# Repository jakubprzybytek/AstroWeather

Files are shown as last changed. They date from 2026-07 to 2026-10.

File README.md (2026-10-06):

# AstroWeather

AstroWeather shows whether the coming nights are good for observing the sky. A
serverless API combines astronomy (sunset, sunrise, sun and moon) with weather
forecasts for a configured location and serves them as a compact text payload.
A Wi-Fi host board fetches that payload every 6 hours and shows six observing
nights on LED displays: its own and up to five chained display boards.

```text
weather supplier ──> sst API (AWS) ──HTTP──> host board ──I2C──> display boards (up to 5)
 (Clearoutside)       GET /astro/{id}       STM32G0B1 +           same PCB, no Wi-Fi
                                            ST67W611M1 Wi-Fi
```

## Repository layout

| Folder | What it holds | Start here |
| --- | --- | --- |
| [`sst/`](sst/) | The server: an [SST](https://sst.dev/) app on AWS (API Gateway, Lambda, DynamoDB, CloudFront), the weather ingestion jobs and a web UI | [architecture](sst/docs/architecture.md) |
| [`firmware/HostControllerA/`](firmware/HostControllerA/) | Firmware for the Wi-Fi host board (STM32G0B1) | [README](firmware/HostControllerA/README.md) |
| [`firmware/DisplayController/`](firmware/DisplayController/) | Firmware for the remote display boards (STM32G070): local display and the I2C link to the host; runs on the first display board | [README](firmware/DisplayController/README.md) |
| [`firmware/Common/`](firmware/Common/) | Code compiled into both firmware images: display encoding and multiplexing, the SCT2xxx driver, the I2C message, task helpers, and their native tests | [README](firmware/Common/README.md) |
| [`firmware/Bypass/`](firmware/Bypass/) | Bench firmware for a separate STM32G0B0 board: a USB-to-UART bridge for talking to and flashing the ST67W611M Wi-Fi module | [README](firmware/Bypass/README.md) |
| [`firmware/Docs/`](firmware/Docs/) | Documentation shared by the firmware projects: development workflow, display, I2C, testing, utilities | [README](firmware/Docs/README.md) |
| [`KiCad/`](KiCad/) | Schematic and PCB of the board. One design is populated as the host or as a display board | [README](KiCad/Docs/README.md) |

## Documentation

**Server (`sst/docs/`)**

- [architecture.md](sst/docs/architecture.md): components, data flow, storage, deployment stages
- [api.md](sst/docs/api.md) and [api-payload.md](sst/docs/api-payload.md): the forecast endpoint and its text payload, which the firmware parses
- [clearoutside-weather-supplier.md](sst/docs/clearoutside-weather-supplier.md): the weather source in use
- [meteosource-weather-supplier.md](sst/docs/meteosource-weather-supplier.md): evaluation of a possible second source
- [development.md](sst/docs/development.md): setup, local development and deployment
- [testing.md](sst/docs/testing.md): unit and integration tests

**Firmware**

Each firmware project starts with a README that lists its features and links
the document for each; documents shared by the projects are in
[firmware/Docs](firmware/Docs/README.md).

- [HostControllerA README](firmware/HostControllerA/README.md): what the host firmware does, its feature status table, quick start and documents
- [DisplayController README](firmware/DisplayController/README.md): the display board firmware, its feature status table, pins and documents
- [Common README](firmware/Common/README.md): the code shared by both firmware images
- [Development.md](firmware/Docs/Development.md): build, flash, debug, connecting over USB, CubeMX rules, for every project
- [Console.md](firmware/HostControllerA/Docs/Console.md): every console command, including Wi-Fi and server settings

**Hardware ([`KiCad/Docs`](KiCad/Docs/README.md))**

- [Hardware_Review.md](KiCad/Docs/Hardware_Review.md): design review, open issues, and measured current draw
- [Display-Issues.md](KiCad/Docs/Display-Issues.md): hardware problems seen on the LED displays, such as the prototype's matrix column faults around `U505`
- [Display_Board_Purchasing.md](KiCad/Docs/Display_Board_Purchasing.md) and [Display_Board_BOM.csv](KiCad/Docs/Display_Board_BOM.csv): parts for the display boards

## Status

- The server is deployed in stages (`prod`, `int`, ...; see
  [architecture.md](sst/docs/architecture.md#web-ui)); the host board fetches
  from the `int` stage.
- The host board fetches, shows and schedules the forecast. The first display
  board runs the DisplayController firmware on the host's I2C bus. See the feature table in the
  [firmware README](firmware/HostControllerA/README.md#features).
- The prototype host board carries hand rework for hardware issues that are not
  yet in the design files. See [Hardware_Review.md](KiCad/Docs/Hardware_Review.md#issues-sorted-by-severity).

## Getting started

- **Server:** [sst/docs/development.md](sst/docs/development.md).
- **Firmware:** the [quick start](firmware/HostControllerA/README.md#quick-start)
  in the firmware README, then [Development.md](firmware/Docs/Development.md)
  to build and flash. The board is pointed at the server with the `api` and
  `wifi` console commands.

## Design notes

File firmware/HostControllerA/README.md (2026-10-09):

# HostControllerA Firmware

Firmware for the AstroWeather host controller board: an STM32G0B1 with an
ST67W611M1 Wi-Fi module that fetches an astronomy and weather forecast and
shows it on seven-segment and dot-matrix LED displays, its own and those of up
to five remote display boards.

## What It Does

- Every 6 hours, at 00:10, 06:10, 12:10 and 18:10 local time, it joins Wi-Fi
  and fetches a line-based forecast payload over HTTPS from the AstroWeather
  server (`../../sst`), sending the device key saved with `api key`. A slot
  missed while the board was off or offline is caught up once, and failures
  are retried with a growing delay.
- It checks the payload's CRC, parses it, and shows it on its own LED board and
  on the remote display boards over I2C. Night *n* of the forecast goes to the
  board at address `0x10 + n`; every board, the host included, reads its
  address from its straps. It keeps the display boards' refresh in step with
  its own, so blinking and the `LED_1` heartbeat run together on every board.
- It keeps the date and time in the RTC, which runs from the 24 MHz crystal
  (HSE / 32) and is stepped to the server's time on every fetch. The time is shown as `HH:MM` on numeric display 3.
- It offers a USB CDC console for logs, status and commands, and keeps the
  last 24 warnings and errors over resets.
- It keeps its settings, including the Wi-Fi credentials, the server address
  and key and the clock trim, in an I2C EEPROM.
- It measures the board's supply current, die temperature and VDDA.
- Switch 1 starts a refresh; switch 2 toggles a low-brightness step on every
  board.

## Hardware

| Part | Role |
| --- | --- |
| STM32G0B1CETx | MCU: Cortex-M0+, 512 KB flash, 144 KB RAM, run at 16 MHz from a 24 MHz crystal |
| ST67W611M1 | Wi-Fi module, on SPI1 with DMA; runs ST's T01 firmware, so TCP/IP, DNS and TLS are in the module |
| 24AA04 | 512-byte I2C EEPROM for settings, on I2C1 at `0x50` |
| SCT2xxx | LED drivers in one SPI3 daisy chain, multiplexed in five slots |
| INA180A2 | Current-sense amplifier into ADC1 channel 10 (`PB2`) |
| `SWITCH_1`, `SWITCH_2` | Push buttons on `PB12` (astro refresh) and `PB13` (low brightness) |
| `LED_1`, `LED_2` | Heartbeat from the display refresh (`PC13`); switch presses and USB console traffic (`PB9`) |
| USB FS | CDC virtual COM port for the console |

The full pin map and the interrupt priorities are in
[Architecture.md](Docs/Architecture.md#peripherals-and-pins). The board design
and its known issues are in [KiCad/Docs](../../KiCad/Docs/README.md).

## Quick Start

1. Copy `Appli/App/app_credentials.h.template` to `Appli/App/app_credentials.h`
   (ignored by git) and set `APP_ST67_HTTP_HOST`, a bare host name, and
   `APP_ST67_HTTP_PATH`, starting with `/`. These are the built-in server; a
   board can be pointed elsewhere with `api host` and `api path`. The SSID and
   password macros in the template are not used.
2. Build, flash and open the console as described in
   [Development.md](../Docs/Development.md).
3. On the console, store the Wi-Fi credentials and the device key; both are
   saved to the EEPROM:

   ```text
   wifi set <ssid> <password>
   api key <key>
   ```

   `wifi set` runs a refresh straight away; `status` shows the result.
4. The clock needs no trim. If the drift measurement of a new board shows a
   crystal error of more than a few tens of ppm, set it with
   `time trim <ppm>` as described in [RTC.md](Docs/RTC.md#trimming).

## Features

Status: ✅ done · 🟡 partial · 🔴 not started · ⚠️ blocked by hardware.
Hardware issue IDs (C-1, H-1, ...) refer to
[Hardware_Review.md](../../KiCad/Docs/Hardware_Review.md).

| Feature | Status | Notes | Document |
| --- | --- | --- | --- |
| **Connectivity** | | | |
| Wi-Fi connection (ST67W611M1): join, DHCP, failure diagnosis | ✅ | Credentials set with `wifi set`, saved to the EEPROM | [WiFi.md](Docs/WiFi.md) |
| Fetch over HTTPS | ✅ | TLS in the module (T01), certificate chain and hostname verified against the built-in Amazon Root CA 1; 100/100 stress cycles | [WiFi.md](Docs/WiFi.md#http) |
| Server host, path and device key from the console | ✅ | `api host`, `api path`, `api key`, saved; `app_credentials.h` gives the built-in fallback | [WiFi.md](Docs/WiFi.md#server) |
| Module power saving between fetches | 🔴 | The module stays initialized between fetches | [WiFi.md](Docs/WiFi.md#open-items) |
| **Astro data** | | | |
| Payload parser (protocol 3, 6 blocks) | ✅ | Unit tested | [AstroRefresh.md](Docs/AstroRefresh.md) |
| Refresh every 6 hours with retry and catch-up | ✅ | The last success is lost on power loss | [AstroRefresh.md](Docs/AstroRefresh.md#schedule) |
| Refresh from switch 1 or the console | ✅ | A second request while busy is rejected | [AstroRefresh.md](Docs/AstroRefresh.md#triggers) |
| **Display** | | | |
| Local LED board: interrupt-driven multiplexing, refresh progress bar | ✅ | Matrix column 1 stays lit on the prototype ([Display-Issues.md](../../KiCad/Docs/Display-Issues.md)) | [Display.md](../Docs/Display.md) |
| Blinking and four brightness levels per segment and pixel | ✅ | The forecast's matrix rows carry levels and blink; the clock's colon and the progress bar blink | [Display.md](../Docs/Display.md#blink-and-brightness-levels) |
| Numeric formatting: fixed point, time, `?`, "no data" | ✅ | -0.5 shows as `-0.5`; values that do not fit four digits show the error pattern | [Display.md](../Docs/Display.md#numeric-representation) |
| Boot screens: slot test, then the host's strap address and build number | ✅ | Shared with the display boards | [Display.md](../Docs/Display.md#boot-screens) |
| Remote display boards over I2C | ✅ | Board `0x11` runs the [DisplayController](../DisplayController/README.md) firmware; I2C pull-ups needed (H-4) | [I2C.md](../Docs/I2C.md) |
| Timeline sync: the display boards' refresh, blinking and heartbeat in step with the host's | 🟡 | `DisplaySync` broadcasts on the I2C general call at boot, on request and every 2 min, and polls each board's status; `time sync [now]`. Unit tested, simulated and bench-measured on one board | [TimelineSync.md](../Docs/TimelineSync.md) |
| Heartbeat on `LED_1`, 20 ms every 2 s | ✅ | From the refresh interrupt, so it shows the refresh is running | [TimelineSync.md](../Docs/TimelineSync.md#the-timeline-on-every-board) |
| Low-brightness step (`LOW_POWER_ENABLE`) for every board | ✅ | `display low on\|off` or switch 2, saved; cuts LED current by about half | [Display.md](Docs/Display.md#low-brightness) |
| **Time** | | | |
| RTC clock on numeric display 3, `time` commands | ✅ | Lost on power loss (no LSE crystal or backup battery) | [RTC.md](Docs/RTC.md) |
| Clock sync from the server, with drift measurement | ✅ | | [RTC.md](Docs/RTC.md#sync-from-the-api) |
| RTC on the 24 MHz crystal (HSE / 32), clock trim | ✅ | The crystal's error not measured yet; `time trim` by hand, ±1000 ppm | [RTC.md](Docs/RTC.md#clock-source) |
| System clock from the 24 MHz crystal | ✅ | `time hsi` and `tools/hsi_measure.py`'s trim are left over from HSI16 and have no effect | [TimelineSync.md](../Docs/TimelineSync.md#the-hosts-clock) |
| **Power and sensing** | | | |
| Current, temperature and VDDA monitor | ✅ (reworked board) | Needs the C-1 and H-1 rework | [CurrentSense.md](Docs/CurrentSense.md) |
| VBUS voltage sense | ⚠️ | PC7 is not an ADC pin and has no divider (H-1, H-2) | [Hardware review](../../KiCad/Docs/Hardware_Review.md) |
| USB-PD negotiation for more than 5 V | 🔴 | Hardware changes needed; see the [study](../../KiCad/Docs/archive/USB_PD_Feasibility.md) | |
| Reading the USB-C current limit (CC pins) | 🔴 | Worst-case load exceeds the USB default (H-5) | [Hardware review](../../KiCad/Docs/Hardware_Review.md) |
| **System** | | | |
| USB console: commands, help, log, statistics | ✅ | `help`, `help <group> <command>`, `help all` | [Console.md](Docs/Console.md) |
| Display commands for this board, a remote board or all | ✅ | `display 0x12 test`, `display all clear` | [Console.md](Docs/Console.md#display) |
| Error log: the last 24 warnings and errors, kept over resets | ✅ | `errors [clear]`; lost on power loss | [Console.md](Docs/Console.md#error-log) |
| EEPROM settings | ✅ | | [Settings.md](Docs/Settings.md) |
| Interrupt priorities: USB 1, everything else 3 | ✅ | | [Architecture.md](Docs/Architecture.md#interrupt-priorities) |
| Firmware version and git hash | 🔴 | Only the build time and a build number (`BUILD_NUMBER`, one more every build) are stamped | [Architecture.md](Docs/Architecture.md#shared-code) |
| Unit tests | 🟡 | 16 native suites run in CI; the console, the settings store and the remote boards are not covered yet | [Testing.md](Docs/Testing.md) |

## Known Limitations and Open Items

Hardware:

- **The prototype host board carries hand rework** that the design files do not
  show yet: `VREF+` rewired to VDD (C-1) and the current-sense net taken to PB2
  (H-1). Boards built from the current files need the same changes.
- **Random contents at power-up (L-3):** the host still starts `SCT_ENABLE`
  low; the display boards already start it high
  ([Display-Issues.md](../../KiCad/Docs/Display-Issues.md#other-known-issues)).

Firmware, with details in each document's open items:

- Wi-Fi: module power policy, repeated cold restarts, the HTTP error paths at
  run time, small heap retentions, no fetch cancellation, certificate validity
  dates ([WiFi.md](Docs/WiFi.md#open-items)).
- Astro refresh: stale data after a failed noon refresh, low-power wake
  ([AstroRefresh.md](Docs/AstroRefresh.md#open-items)).
- Clock: measure the crystal's error, and the time lost over a flash
  ([RTC.md](Docs/RTC.md#open-items)).
- Display timeline sync: a run over a day's temperature, the display boards'
  HSI16 wander, the leftover `time hsi`
  ([TimelineSync.md](../Docs/TimelineSync.md#open-items)).
- Settings: a torn write is detected but not recovered, credentials are stored
  in the clear, unknown tags are not preserved
  ([Settings.md](Docs/Settings.md#limitations)).
- RAM: the forecast payload is held twice; holding it once would save 4 KB
  ([Firmware-RAM-Usage.md](Docs/Firmware-RAM-Usage.md)).
- Tests: the console, `Settings::Store`, the EEPROM driver and
  `BufferedDisplayBoard` ([Testing.md](Docs/Testing.md#not-covered-yet)).

## Documentation

This project ([Docs](Docs/)):

- [Architecture.md](Docs/Architecture.md): boot, tasks, inter-task communication, interrupt priorities, pins, memory
- [Console.md](Docs/Console.md): the USB device, the log, the error log and every console command
- [WiFi.md](Docs/WiFi.md): the ST67 module, the session, HTTPS, the server settings
- [AstroRefresh.md](Docs/AstroRefresh.md): the refresh pipeline, the payload, the display mapping, the schedule
- [Display.md](Docs/Display.md): the host's side of the displays: the aggregate display, remote boards, progress bar, low brightness
- [RTC.md](Docs/RTC.md): the clock, its trim and the sync from the server
- [Settings.md](Docs/Settings.md): the EEPROM settings image
- [CurrentSense.md](Docs/CurrentSense.md): current, temperature and VDDA
- [Testing.md](Docs/Testing.md): this project's suites, coverage and bench tests
- [Firmware-RAM-Usage.md](Docs/Firmware-RAM-Usage.md): static RAM breakdown
- [archive](Docs/archive/README.md): plans, investigations and measurement logs

Shared with the display boards ([firmware/Docs](../Docs/README.md)):

- [Development.md](../Docs/Development.md): build, flash, debug, connecting over USB, CubeMX rules
- [Display.md](../Docs/Display.md): the display, its encoding and refresh
- [TimelineSync.md](../Docs/TimelineSync.md): the timeline sync to the display boards, its schedule, the clocks
- [I2C.md](../Docs/I2C.md): the bus, the messages, the addresses, both sides of the link
- [Testing.md](../Docs/Testing.md): the native test kit
- [Utilities.md](../Docs/Utilities.md): tasks, mutexes, switches, the microsecond clock, HSI trim, LEDs

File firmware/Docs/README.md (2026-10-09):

# Firmware Documentation

Documents that apply to more than one firmware project. Each project's own
documents are listed in its README.

| Document | Covers |
| --- | --- |
| [Development.md](Development.md) | Toolchain, building, flashing and debugging every project, connecting to the host's USB CDC console, and keeping application changes CubeMX-compliant |
| [Display.md](Display.md) | The LED display shared by every board: content model, blink and brightness levels, PCB encoding, the interrupt-driven refresh, boot screens and "no data", the `SCT2xxx` chain |
| [TimelineSync.md](TimelineSync.md) | How the display boards keep their refresh in step with the host's: the shared timeline, the host's schedule of syncs, a board's decisions, the clocks and HSITRIM, measuring it over SWD, accuracy |
| [I2C.md](I2C.md) | The I2C link between the host and the display boards: bus, addresses and straps, message format, the timeline sync broadcast and status read, the host's master side and the display board's target side |
| [Testing.md](Testing.md) | Native unit tests: running and writing them, the shared stubs and assertions, CI, coverage, the shared code's suites |
| [Utilities.md](Utilities.md) | The shared tasks, mutexes, switches, CRC-32, microsecond clock, HSI trim and status LEDs, and the rules for code in `Common` |

## Projects

| Project | Board | README |
| --- | --- | --- |
| `HostControllerA` | Wi-Fi host, STM32G0B1 | [README](../HostControllerA/README.md) |
| `DisplayController` | Remote display boards, STM32G070 | [README](../DisplayController/README.md) |
| `Common` | Code compiled into both of the above | [README](../Common/README.md) |
| `Bypass` | Bench USB-to-UART bridge for the ST67 module, STM32G0B0 | [README](../Bypass/README.md) |

The board hardware (schematic review, display board parts, known display
faults) is documented in [KiCad/Docs](../../KiCad/Docs/README.md).

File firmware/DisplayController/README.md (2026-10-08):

# DisplayController Firmware

Firmware for the AstroWeather remote display boards: an STM32G070CBT6 that
receives its display content from the host over I2C and multiplexes it onto
its own four seven-segment displays and 5x21 dot matrix. A display board is
the same PCB as the host, populated without the Wi-Fi module, the USB port and
the EEPROM; see
[Display_Board_Purchasing.md](../../KiCad/Docs/Display_Board_Purchasing.md).

The first display board runs it on the host's I2C bus at `0x11`.

## Features

Status: ✅ done and checked on the board · 🔵 built and unit tested, not yet
checked on the board · 🔴 not started.

| Feature | Status | Notes | Document |
| --- | --- | --- | --- |
| **Display** | | | |
| Drive the local LED board: five slots, 50 Hz frames, four passes per slot | ✅ | `PcbDisplayBoard` from TIM6's interrupt, SPI1 by DMA; shared with the host | [Display.md](../Docs/Display.md#refresh-operation) |
| Blink and four brightness levels per segment and pixel | ✅ | Sent by the host as attribute planes with the content | [Display.md](../Docs/Display.md#blink-and-brightness-levels) |
| Refresh timeline kept on the host's: blinking and the heartbeat in step on every board | 🔵 | Syncs broadcast by the host on the I2C general call; per-frame rate and phase correction, simulated within a few ms | [TimelineSync.md](../Docs/TimelineSync.md) |
| HSITRIM moved to follow the host's clock | 🔵 | Up to 8 steps from the boot trim, never across an HSICAL band edge; the servo covers the rest, up to 2 % | [TimelineSync.md](../Docs/TimelineSync.md#following-the-host) |
| Safe power-up: outputs blanked, all slots off | ✅ | `SCT_ENABLE` and the slot selects start high (CubeMX); the first frame is prepared before the outputs are enabled | [Architecture.md](Docs/Architecture.md#boot) |
| Boot screens: slot test (each `DISPLAYx_EN` slot on its own, 1 s), then the board address (`Ad11`) and build number, 2 s | ✅ | Shared with the host (`Display::showBootScreens()`) | [Display.md](../Docs/Display.md#boot-screens) |
| "No data" until the first frame, and again after 7 h without one | 🔵 | Shared state (`Display::noDataState()`); 7 h is just over the host's 6-hour refresh interval | [Architecture.md](Docs/Architecture.md#screens) |
| **I2C link to the host** | | | |
| Address from the `ADDR_0..2` straps, `0x10`–`0x2A` | ✅ | Floating 0, ground 1, VCC 2; board 1 reads `0x11` | [I2C.md](../Docs/I2C.md#addresses-and-straps) |
| I2C target: content and attribute messages | ✅ | Interrupt-driven listen; the messages are decoded in the `DisplayApp` task. The I2C interrupt is at priority 1 so every message is acknowledged | [I2C.md](../Docs/I2C.md#display-board-side) |
| Listen only once the address is known | ✅ | Nothing answers on CubeMX's placeholder `0x10` | [I2C.md](../Docs/I2C.md#display-board-side) |
| Timeline sync on the general call, status on a one-byte read | 🔵 | `0xA0` with flags: locked, needs content; a reset board asks for and gets the host's content within a minute | [I2C.md](../Docs/I2C.md#timeline-sync) |
| Reject unknown commands and short writes, keeping the previous frame | 🔵 | Counted in `g_displayStats` | [I2C.md](../Docs/I2C.md#display-board-side) |
| Recover from bus errors | 🔵 | Listening restarts after an error and is checked every second | [I2C.md](../Docs/I2C.md#display-board-side) |
| **Brightness** | | | |
| Never drive the bussed `LOW_POWER_ENABLE` line | ✅ | `PB8` stays analog; the host drives it for every board ([Hardware review](../../KiCad/Docs/Hardware_Review.md) M-4) | [Display.md](../Docs/Display.md#low-brightness) |
| **Development aids** | | | |
| Heartbeat on `LED_1`, 20 ms every 2 s, from the refresh interrupt | 🔵 | Frame 1 of every 100 on the shared timeline, so in step with the host once synced; twice (frames 1 and 11) while not locked to it | [TimelineSync.md](../Docs/TimelineSync.md#the-timeline-on-every-board) |
| `LED_2` flashes on every write addressed to the board | 🔵 | 20 ms, from the address-match interrupt, through the shared `PulseLed`; not for the sync broadcast or the status reads | [Architecture.md](Docs/Architecture.md#screens) |
| Switch 1 steps through test screens, switch 2 shows the address | 🔵 | All segments, then an identify pattern; test screens close after 60 s, the address after 3 s | [Architecture.md](Docs/Architecture.md#screens) |
| Diagnostic counters, read over SWD | ✅ | `g_displayStats`: frames, attributes, rejects, short writes, probes, I2C errors, refresh counters; the sync counters, error, drift, rate and HSITRIM (🔵) | [Architecture.md](Docs/Architecture.md#diagnostics) |
| Stack overflow hook | ✅ | Halts with the task name in `g_stackOverflowTaskName` | [Architecture.md](Docs/Architecture.md#diagnostics) |
| Console over USART2 (`PA2`/`PA3`, 115200) | 🔴 | The G070 has no USB; USART2 is disabled in CubeMX. Wiring in [Display_Board_Purchasing.md](../../KiCad/Docs/Display_Board_Purchasing.md#console-over-uart) | |
| **Platform** | | | |
| CubeMX project on the STM32G070, `Debug` and `Release` presets | ✅ | Compiles the shared code from `../Common` | [Development.md](../Docs/Development.md) |
| FreeRTOS with static tasks; `defaultTask` exits at start | ✅ | The 3072-byte heap is used only by `defaultTask` until it exits | [Architecture.md](Docs/Architecture.md#tasks) |
| Interrupt priorities: I2C 1, everything else 3 | ✅ | | [Architecture.md](Docs/Architecture.md#interrupt-priorities) |
| Native tests for the screens, the stale-data timeout and the frame assembly | ✅ | 3 suites in `tests/`; the shared code's suites, the timeline sync's among them, are in `../Common/tests` | [Testing.md](../Docs/Testing.md) |

## Hardware

From `DisplayController.ioc`; the pins and their labels match the host so the
shared code compiles unchanged.

| Peripheral | Pins | Use |
| --- | --- | --- |
| SPI1, master TX only, 1 Mbit/s, TX by DMA1 channel 1 | `PB3` SCK, `PB5` MOSI | SCT2xxx daisy chain |
| GPIO | `PB6` `SCT_LATCH`, `PB7` `SCT_ENABLE` (starts high: outputs blanked) | SCT latch and output enable |
| GPIO | `PD3`, `PA15`, `PD1`, `PD2`, `PD0` = `DISPLAY_1_EN`..`DISPLAY_5_EN` (start high: off) | Active-low multiplex selects |
| TIM6, prescaler 15 (1 MHz count) | none | Display refresh; the interrupt sets each pass's length (the G070 has no TIM2) |
| I2C1, target, interrupt at priority 1 | `PA9` SCL, `PA10` SDA | Messages from the host, at `0x10` + the strap ID; the timeline sync on the general call (enabled in code, not the `.ioc`) |
| GPIO inputs | `PB10`, `PB11`, `PB14` = `ADDR_0`..`ADDR_2` | Board address straps; analog once read |
| GPIO EXTI, falling edge, internal pull-up | `PB12` `SWITCH_1`, `PB13` `SWITCH_2` | Switches; the buttons and their external pull-ups are optional on a display board |
| GPIO | `PC13` `LED_1`, `PB9` `LED_2` | Heartbeat from the refresh interrupt, I2C writes to the board |
| Analog | `PB8` `LOW_POWER_ENABLE` | Bussed net driven by the host; never driven here |
| SWD | `PA13`, `PA14` | Debug |
| TIM1 | none | HAL time base |

## Build and Flash

The toolchain, presets, flashing and native tests are shared with the other
firmware projects and described in
[Development.md](../Docs/Development.md). In short:

```bash
cmake --preset Debug
cmake --build --preset Debug
STM32_Programmer_CLI -c port=SWD -w build/Debug/DisplayController.elf -v -hardRst
```

## Layout

| Path | Owner |
| --- | --- |
| `DisplayController.ioc`, `Core/`, `Drivers/`, `Middlewares/`, `cmake/stm32cubemx/`, the startup file and linker script | CubeMX; application changes only inside `USER CODE` sections |
| `CMakeLists.txt`, `CMakePresets.json` | The project: adds `User/` and `../Common` to the CubeMX target |
| `User/Inc`, `User/Src` | Application code specific to the display board |
| `tests/` | Native tests of that code |
| `../Common` | Code shared with the host, compiled into this image ([README](../Common/README.md)) |

## Documentation

This project:

- [Docs/Architecture.md](Docs/Architecture.md): boot, tasks, screens, interrupt priorities, the SWD diagnostics
- [Docs/archive](Docs/archive/): [I2C_NACK_Investigation.md](Docs/archive/I2C_NACK_Investigation.md), how the I2C interrupt priority was found

Shared with the host ([firmware/Docs](../Docs/README.md)):

- [Development.md](../Docs/Development.md): build, flash, debug, CubeMX rules
- [Display.md](../Docs/Display.md): the display, its encoding and refresh
- [TimelineSync.md](../Docs/TimelineSync.md): the timeline kept on the host's, the sync schedule and decisions, HSITRIM, measuring it with `tools/stats_log.py`
- [I2C.md](../Docs/I2C.md): the bus, the messages, the addresses, both sides of the link
- [Testing.md](../Docs/Testing.md): native tests
- [Utilities.md](../Docs/Utilities.md): tasks, mutexes, switches, the microsecond clock, HSI trim, LEDs

Hardware: [KiCad/Docs](../../KiCad/Docs/README.md).

## Known Limitations and Open Items

- Not yet checked on the board: rejecting unknown commands and short writes,
  recovery from bus errors, the 7-hour "no data" timeout and the switch test
  screens.
- The timeline sync: a run over a day's temperature, the cause of the host's
  clock wander
  ([TimelineSync.md](../Docs/TimelineSync.md#open-items)).
- No console: the counters are read over SWD until the USART2 console exists.
- The FreeRTOS heap (3072 B) could shrink, since only `defaultTask` uses it
  and only until it exits.

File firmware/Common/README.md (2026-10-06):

# Common Firmware Code

Code shared by the two AstroWeather firmware images:
[HostControllerA](../HostControllerA/README.md), the Wi-Fi host on an
STM32G0B1, and [DisplayController](../DisplayController/README.md), the remote
display boards on an STM32G070.

## What Is Here

| Directory | Contents |
| --- | --- |
| `Src/Display`, `Inc/Display` | Logical display content and attributes (`DisplayTypes`), the PCB segment and matrix encoding (`DisplayCodec`), the pass sequencing (`RefreshSequencer`), the interrupt-driven multiplexing (`PcbDisplayBoard`), the refresh timeline and its sync (`Timeline`, `TimelineServo`, `TimelineSync`), the boot screens (`BootScreens`), the I2C message format (`DisplayI2cProtocol`), the address straps (`DisplayAddress`) and the `DisplayBoard` interface |
| `Src/Device`, `Inc/Device` | The `SCT2xxx` LED driver chain over SPI; `HsiTrim`, the HSI16 user trim |
| `Src/Utils`, `Inc/Utils` | `Task`/`TaskBase` (CMSIS-RTOS2 tasks with static stacks and a registry), `Mutex`, `SwitchInput`, `Crc32`, `microsNow()` (`MicroClock`) |
| `Src/Debug`, `Inc/Debug` | `PulseLed` and `activityLed()` (`LED_2`, also from interrupts and C through `ActivityLedBridge.h`); the `LED_1` heartbeat comes from the refresh interrupt (`PcbDisplayBoard`) |
| `tests/` | Native unit tests for the above, and the pieces both projects' own tests reuse: the HAL and RTOS stubs (`stubs/`), `Expect.hpp` (`support/`), `add_native_test()` (`NativeTest.cmake`) and a stand-in `main.h` (`board/`) |

Each part is documented in the shared firmware docs, [firmware/Docs](../Docs/README.md):

| Part | Document |
| --- | --- |
| Display content, attributes, PCB encoding, the multiplexing refresh, the timeline sync and the heartbeat, boot screens, `SCT2xxx` | [Display.md](../Docs/Display.md) |
| The I2C message format, the sync broadcast and status read, the address straps | [I2C.md](../Docs/I2C.md) |
| `Task`, `Mutex`, `SwitchInput`, `Crc32`, `microsNow()`, `HsiTrim`, the LEDs | [Utilities.md](../Docs/Utilities.md) |
| The native test kit and the suites in `tests/` | [Testing.md](../Docs/Testing.md) |

## How It Is Built

This is not a library. Each firmware project includes `CommonSources.cmake`
and compiles `${COMMON_SOURCES}` itself, against its own HAL, device define
(`STM32G0B1xx` or `STM32G070xx`), `stm32g0xx_hal_conf.h`, `FreeRTOSConfig.h`
and `main.h`. A change here must therefore be built in both projects.

Rules for code in this tree:

- It may include `main.h`, `cmsis_os2.h` and `FreeRTOS.h`, and may use the pin
  labels both CubeMX projects define: `LED_1`, `LED_2`, `SWITCH_1`, `SWITCH_2`,
  `ADDR_0`..`ADDR_2`, `DISPLAY_1_EN`..`DISPLAY_5_EN`, `SCT_LATCH`, `SCT_ENABLE`.
  Peripheral handles (`hspi3` on the host, `hspi1` on the display board, the
  refresh timer) are passed in by the project, never named here.
- It must not depend on anything only one project has: the host's `LogService`,
  USB, the settings store, the EEPROM, Wi-Fi.

## Tests

The native suites build with the host compiler and run under CTest, without a
board (MSYS2 UCRT64 on the development workstation, see the presets):

```bash
cmake --preset NativeTests
cmake --build --preset NativeTests
ctest --test-dir build/native-tests-local --output-on-failure
```

`NativeTests-Coverage` adds `--coverage` for `gcovr`. The GitHub Actions
workflow `firmware-native-tests.yml` runs these suites and both projects' on
every push. How to write a test, the stubs and what each suite covers are in
[Testing.md](../Docs/Testing.md).

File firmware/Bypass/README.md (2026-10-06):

# AstroWeather ST67 Bypass

## Purpose

Firmware for an STM32G0B0-based board that turns a PC's USB connection into a
binary-transparent bridge to an ST67W611M Wi-Fi/BLE NCP module:

```text
PC (USB CDC)  <->  STM32G0B0 Bypass firmware  <->  USART2 (2,000,000 baud)  <->  ST67W611M
```

It supports two purposes:

1. **UART bypass ("Manufacture" mode)** - a transparent pass-through so a PC
   tool can talk to the ST67's normal UART shell/AT-style interface.
2. **Bootloader mode** - applies the ST67's verified bootloader strap/reset
   sequence and then provides the same transparent transport, so the PC-side
   vendor tool `QConn_Flash_Cmd` can erase/program/verify the ST67 over USB
   instead of needing direct wiring to the module's UART pins.

The STM32 firmware never parses or interprets the ST67 protocol in either
mode; it only applies the correct GPIO strap sequence and moves bytes.

[Docs/ST67_Bypass_Maintainer_Notes.md](Docs/ST67_Bypass_Maintainer_Notes.md)
covers the architecture, mode selection, host tooling, the verified ST67 flash
map and known tooling quirks. The original implementation plan and bring-up
guide are in [Docs/archive](Docs/archive/).

## Building

Prerequisites: `arm-none-eabi-gcc`, `cmake`, and `ninja`. If you have
STM32CubeIDE installed instead of a standalone toolchain, it bundles all
three under its `plugins/com.st.stm32cube.ide.mcu.externaltools.*/tools/bin`
folders - add those to `PATH` for the commands below.

The project builds with four CMake presets, one per combination of build
type and ST67 startup mode (`CMakePresets.json`):

| Preset | Build type | ST67 startup mode |
|---|---|---|
| `Debug-Manufacture` | Debug | Manufacture (default) |
| `Release-Manufacture` | Release | Manufacture (default) |
| `Debug-Bootloader` | Debug | Bootloader |
| `Release-Bootloader` | Release | Bootloader |

```bash
cmake --preset Debug-Manufacture
cmake --build --preset Debug-Manufacture
```

Each preset configures into its own `build/<PresetName>` directory and
produces a `Bypass.elf` there, so manufacture and bootloader builds never
overwrite each other. The startup mode is also a plain CMake cache variable
if you prefer configuring manually:

```bash
cmake -S . -B build/manual -G Ninja \
  -DCMAKE_TOOLCHAIN_FILE=cmake/gcc-arm-none-eabi.cmake \
  -DCMAKE_BUILD_TYPE=Debug -DST67_DEFAULT_MODE=BOOTLOADER
```

Flash the resulting `Bypass.elf` with your usual SWD tool (STM32CubeProgrammer,
STM32CubeIDE debug launch, OpenOCD, etc.) - this project does not script
flashing the STM32 itself.

## Usage

### UART bypass (Manufacture mode)

1. Flash a `*-Manufacture` build.
2. Plug the board in over USB. It enumerates as a CDC serial port named
   **"AstroWeather ST67 Bypass"**.
3. Open that port with any terminal/tool. Opening it (DTR asserted) triggers
   an ST67 reset into Manufacture mode so its startup banner/output isn't
   missed. Bytes sent/received over the port are forwarded to/from the ST67's
   UART untouched - no line parsing, no echo, no translation.
4. Two status LEDs: **LED_1** lights while data is being sent to the ST67,
   **LED_2** lights while data is being received from the ST67 (both also
   used as a basic "is this thing alive" indicator, since LED_1 stays on
   from boot until the first real transfer).

### Programming the ST67 (Bootloader mode)

1. Flash a `*-Bootloader` build. On mode entry the firmware applies the
   verified `BOOT=1`/`CHIP_EN` reset sequence and keeps `CS` high, putting
   the ST67 into its ROM bootloader instead of its normal shell.
2. Optionally verify communication first without any risk of changing the
   device, using the non-destructive chip/efuse query:

   ```bash
   ./tools/Query-ST67.sh --port COM4
   ```

   This only reads the efuse/identity region; it never needs `--force`.
3. Program a signed vendor image with the Bypass-specific wrapper around
   `QConn_Flash_Cmd`:

   ```bash
   ./tools/Program-ST67.sh --port COM4 --profile MissionT01 --force
   ```

   (`--profile` is one of `MissionT01`, `MissionT02`, `Manufacturing`.)
   Without `--force` the script validates every input (vendor tool, config,
   image, efuse file) and prints a lock-risk warning, then stops before
   touching the device - use that first to sanity-check your arguments.
   A PowerShell equivalent, `tools/Program-ST67.ps1`, is also available with
   the same flags for native PowerShell/CI use on Windows.

   **For the AstroWeather HostController use the project's own flash
   configuration**, which replaces the vendor LittleFS image (31 sample
   certificates and keys) with one holding only the CA the firmware trusts:

   ```bash
   ./tools/Build-LittleFS.sh
   ./tools/Program-ST67.sh --port COM4 --profile MissionT01 \
       --config-path tools/astroweather_t01_flash_prog_cfg.ini --force
   ```

   The X-CUBE driver lists the module's whole file system before every
   certificate upload, one entry per ~100 ms, and gives up after 2 s; with
   the vendor image every HTTPS fetch failed in `W6X_FS_ListFiles`
   (2026-10-04). The certificate source is
   `tools/littlefs/Certificates/lfs/AmazonRootCA1.pem`, which must stay
   byte-identical to `HostControllerA/User/Src/WiFi/TrustedCa.cpp`.
4. `tools/Dump-ST67-Flash.sh` reads flash content back for inspection, e.g.
   to confirm which image a board is actually running:

   ```bash
   ./tools/Dump-ST67-Flash.sh --port COM4 --length 0x400000
   ```

   See [Docs/ST67_Bypass_Maintainer_Notes.md](Docs/ST67_Bypass_Maintainer_Notes.md)
   for the verified flash map and how to match a dump against a vendor image.

None of the host scripts ever invoke STM32CubeProgrammer or select a NUCLEO
host image - they only ever touch the Bypass board's own USB CDC port and
ST67 NCP images.

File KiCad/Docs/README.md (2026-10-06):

# AstroWeather Hardware

One KiCad design, `AstroWeather`, is populated two ways: as the host
controller (STM32G0B1, ST67W611M1 Wi-Fi, USB-C, EEPROM, current sense, light
sensor) and as a display board (STM32G070, power supply and displays only).
Both carry the same LED displays: four four-digit seven-segment displays and a
5x21 dot matrix, driven by SCT2xxx chips.

## Design Files

| File | Content |
| --- | --- |
| `AstroWeather.kicad_pro`, `AstroWeather.kicad_sch` | The project and its root sheet, which also holds the USB-C connector and the `J102`/`J104` daisy-chain connectors |
| `HostController.kicad_sch` | MCU (`U302`), switches, LEDs, address straps |
| `Display.kicad_sch` | LED displays, SCT2xxx chain, slot switches, current-set stages |
| `PowerSupply.kicad_sch` | The 3.3 V supply (`U601`, `U602`, `L601`) |
| `LightSensor.kicad_sch` | The light sensor and the `LED_BRIGHTNESS` divider with `LOW_POWER_ENABLE` |
| `ST67W611M1.kicad_sch` | The Wi-Fi module |
| `AstroWeather.kicad_pcb` | The board |
| `AstroWeather.csv` | Bill of materials of the full (host) population |
| `gerber/` | Fabrication outputs |
| `Controller.kicad_sch` | Not used by the root sheet |

## Documents

| Document | Content |
| --- | --- |
| [Hardware_Review.md](Hardware_Review.md) | Design review against the firmware pin map: issues sorted by severity (C-1, H-1, ... referenced from the firmware docs), per-subsystem notes, measured current draw, what to measure on the bench |
| [Display-Issues.md](Display-Issues.md) | Faults seen on the LED displays, such as the prototype's matrix column faults around `U505` |
| [Display_Board_Purchasing.md](Display_Board_Purchasing.md) | Parts for the display-board population, with [Display_Board_BOM.csv](Display_Board_BOM.csv) |
| [archive/](archive/) | [USB_PD_Feasibility.md](archive/USB_PD_Feasibility.md): the study of negotiating more than 5 V over USB Power Delivery |

The firmware for both populations is described in
[firmware/Docs](../../firmware/Docs/README.md).

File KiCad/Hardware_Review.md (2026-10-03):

# AstroWeather Hardware Design Review

**Date:** 2026-09-23
**Scope:** `KiCad/AstroWeather.kicad_sch` and its sub-sheets (`HostController`, `Display`, `PowerSupply`, `LightSensor`, `ST67W611M1`), cross-checked against the firmware pin map (`firmware/HostControllerA/Core/Inc/main.h`, `HostControllerA.ioc`, `Core/Src/main.c`) and the hardware notes in `firmware/HostControllerA/docs/`.

## Method and limits

- The netlist and BOM were exported read-only with KiCad 9 `kicad-cli` (`sch export netlist`, `sch export bom`, `sch erc`) into a scratch folder, then parsed with a throwaway Python script. No project file was modified.
- For a few key parts (`U302`, `U601`, `Q501`, `R304`, `R305`), the net assignments on the PCB pads were read from `AstroWeather.kicad_pcb`. **The PCB layout itself (placement, copper, antenna keep-out, thermal, return paths) was not reviewed.**
- The `STM32G0B1C(B-C-E)Tx` pin positions and alternate functions come from the STM32CubeMX MCU database installed with STM32CubeIDE 1.19.
- Part values come from the schematic `Value` fields. The schematic has **no MPN or manufacturer fields**. Where a value is missing or a placeholder (`dnp`, `x`, `4k7 / 10k`, `D_TVS`), this review says so and does not guess.
- `KiCad/Controller.kicad_sch` (an STM32G030F6 sheet) is not part of the hierarchy and was not reviewed.
- The same PCB is built in two ways: as the **Host Controller** (fully populated) and as up to five **Display Controllers** (no USB-C, INA180, ST67 or light sensor; see `Display_Board_Purchasing.md`). Findings note which build they affect.
- Datasheets used:
  - SCT2024: [StarChips SCT2024 (TME copy)](https://www.tme.eu/Document/8876e3da3e0cc25d8b4c7cdeea8b8a88/SCT2024.pdf)
  - TPS54202: [TI SLVSD26C](https://www.ti.com/lit/ds/symlink/tps54202.pdf)
  - Si2333CDS: [Vishay 68717](https://www.vishay.com/docs/68717/si2333cd.pdf)
  - ST67W611M1 data brief: [DB5452](https://mm.digikey.com/Volume0/opasdata/d220001/medias/docus/7049/DB5452_ST67W611M1.pdf) and the [ST wiki on power supply](https://wiki.st.com/stm32mcu/wiki/Connectivity:ST67W611M1_Power_supplies_and_grounding) (search summary only; the full ST67 datasheet could not be downloaded)
  - FYM-7571AUHR-11 parameters: [TME product page](https://www.tme.eu/en/details/fym-7571auhr-11/led-displays-matrix/foryard/)
  - LFD028BUE-103A: TME/Amazon listings (red, 640 nm, common anode). The Wenrun datasheet itself was not available.
  - Other limits (MCP1825S, INA180, MCP6006, 24AA04/AT24CS01, USB) are quoted from memory and marked "needs datasheet check" where they drive a conclusion.

## Power tree

```
J106 USB-C VBUS (5 V) ──┬── J105 AUX_POWER pin 2   (same node, no protection)
      "VBUS_IN"         ├── R304 (10k sch / 100k PCB) ──> PC7 + C306 1u      (no divider, no ADC on PC7)
                        └── R101 50 mΩ shunt ── U101 INA180A2 (G=50, V+ = 3.3 V)
                               │                    └─ OUT ─ R305 (10k sch / 100k PCB) ─ C307 1u ─> PC6 (no ADC; bodged to PB2)
                               ▼
                             "VBUS" ─┬── J102/J104 pins 6,8 ──> up to 5 Display Controllers (each has its own buck + LDO)
                                     └── U601 TPS54302 (TPS54202 on new boards), C602 10u/35V + C603 100n
                                           L601 33 µH, R601 100k / R602 19k2, C608 47p, C604+C605 2×22u
                                           ▼
                                        "VDD" = 0.596 × (1 + 100/19.2) = 3.70 V  (3.61–3.79 V over the Vref tolerance)
                                           ├── D501 (fitted as a short) ──> VDD_LED ──> Q501–Q505 Si2333 ──> VDD_DIG1..5
                                           │                                          ──> LED anodes ──> SCT2024/SCT2167 sinks
                                           └── U602 MCP1825S-3.3 (C606 4u7 in, C607 1u out)
                                                 ▼
                                              "+3.3V" ──> STM32G0B1 VDD/VBAT (C301 100n, C302 4u7), ST67W611M1 VDD33/VDDIO
                                                          (C201–C203 3×10u), INA180 (C101), EEPROM U301, SCT VDD via
                                                          10 Ω + 1u + 4u7 (×4), MCP6006 ×4, LDR divider, J101/J103
```

Ground: single `GND` net. `VREF+` is also on `GND` (see **C-1**; reworked to VDD on the prototype).

### Load estimate (needs measurement)

The LED current is set by the analog `LED_BRIGHTNESS` voltage, not by a fixed REXT (see the Display notes). The SCT2024 formula is `IOUT ≈ 30 × (630 / REXT)` mA. That is 18.9 V divided by the REXT resistance in mA, and 21 mA at 900 Ω (SCT2024 datasheet, p.10). Depending on the internal REXT reference (0.63 V or 1.26 V, not stated), the gain is 30× or 15× the current drawn from REXT. With `R504` = 4k7 and the brightest light-sensor voltage (1.17 V), that gives **3.7–7.5 mA peak per segment**.

| Load | Per board | Notes |
|---|---|---|
| LEDs, all 53 channels lit in a slot (32 numeric + 21 matrix) | 0.20–0.40 A at 3.7 V | One slot is lit at any time, so this is continuous. It halves with `R504` = 10k. |
| SCT ×4 IDD, MCU, op-amps | ≈ 45 mA at 3.3 V | SCT2024 IDD(ON) 7–10 mA each |
| ST67W611M1 TX burst (host only) | ≈ 300–400 mA at 3.3 V | **Not verified.** 21 dBm Wi-Fi 6 module, typical figure. Needs ST67 datasheet check. |
| **Host, from VBUS** | ≈ 0.35–0.7 A | assuming 85% buck efficiency |
| **5 display boards, from VBUS** | ≈ 5 × (0.2–0.4 A) = 1.0–2.0 A | all of it flows through the host's `R101` and `J106` |
| **System worst case** | **≈ 1.4–2.7 A** | above the USB 2.0 limit (500 mA) and the Type-C 1.5 A level. Only a 3 A Type-C source is safe. |

### Measured current (host board, 2026-09-24)

These readings come from the host's own current sense (`adc log on`) on the reworked prototype, firmware built 2026-09-23 17:11:34, with no remote boards connected. They are the VBUS input current through `R101`, at 5 V. The sense path is filtered by `R305`/`C307` (τ = 100 ms) and sampled at 10 Hz (see [`CurrentSense.md`](../firmware/HostControllerA/docs/CurrentSense.md)). **Anything shorter than about 100 ms is averaged out. Instantaneous peaks, such as Wi-Fi TX bursts, are higher than shown.**

**LEDs.** All four numeric displays were set to `8.888` and all 5×21 matrix dots were lit. That is 50 of the 53 channels; `display set` can light only one decimal point per display. The LED current depends on `LED_BRIGHTNESS`, so on the ambient light. The light level was not measured.

| State | Current at 5 V | Notes |
|---|---|---|
| All LEDs off, Wi-Fi idle | 12–17 mA, typ. 14 | MCU, LDO, SCT idle, op-amps, ST67 idle |
| All LEDs on, dimmer light | 53–57 mA, typ. 55 | LEDs ≈ 42 mA, about 1 mA per segment |
| All LEDs on, brighter light (two runs) | 154–163 mA, typ. 157 | LEDs ≈ 143 mA, about 3.3 mA per segment at 3.7 V |

The brighter reading is just below the 3.7–7.5 mA per segment estimated above for 1.17 V on `LED_BRIGHTNESS`. The maximum brightness case has not been measured yet.

**Low brightness (`LOW_POWER_ENABLE` high, `Q701` on).** All LEDs lit as above, firmware built 2026-09-24 10:14:44, alternating `display low off`/`on` three times in the same light:

| State | Current at 5 V | LEDs (minus 14 mA) |
|---|---|---|
| Normal | 73–79 mA | 59–65 mA |
| Low | 42 mA | 28 mA |
| Either, all LEDs off | 13–15 mA | — |

The LED current falls to about 0.45 of normal. The divider ratio alone (1.5 kΩ instead of 4.7 kΩ at the bottom) predicts 0.32–0.42, so the current-set stages do not track `LED_BRIGHTNESS` exactly (M-5). The ratio is likely to change with the light level.

**Low brightness in a dark room (2026-09-27/28).** In a dark room the result reverses: low brightness makes the LEDs dimmer, but the board current rises to almost twice the normal-brightness reading. With all LEDs off, both states read 12–13 mA, so the extra current appears only while LEDs are lit, and only in the dark. Host board only, no remote boards, read with the INA180 (`status`). The exact lit-LED readings were not recorded. See M-8.

**Astro refresh.** Three `astro refresh` runs were captured with the normal display content shown. Each keeps the ST67 active for about 5 s: joining, getting an IP, downloading, disconnecting. All three succeeded.

| Run | Before refresh | Wi-Fi active, typical | Highest sample | Rise over baseline |
|---|---|---|---|---|
| 1 | 67 mA | 110–120 mA | 144 mA (joining) | +77 mA |
| 2 | 56 mA | 110–135 mA | 161 mA (joining) | +105 mA |
| 3 | 73 mA | 115–130 mA | 162 mA (joining) | +89 mA |

The highest filtered samples came while joining the network; the download stage sat steadier at 125–147 mA. Averaged over 100 ms, the ST67 adds about 45–65 mA while active and at most about 105 mA. That is well below the 300–400 mA TX figure assumed in the load table. Short TX bursts may still reach that level, but they would need a scope across `R101` to see. For `L601` (M-1), the filter hides nothing that matters thermally, but it could hide short saturation peaks.

Log: 1,608 samples, captured with `astro_console.py send --wait 40 "adc log on" "astro refresh" "astro refresh" "astro refresh" "adc log off"`.

## Issues (sorted by severity)

Confidence key:
- **Confirmed:** confirmed from the schematic (and PCB where noted).
- **Measure:** needs a bench measurement.
- **Datasheet:** needs a datasheet check.

| ID | Severity | Sheet / Ref(s) | Issue | Evidence | Suggested fix | Confidence |
|---|---|---|---|---|---|---|
| C-1 | **Critical** | Host Controller / U302 pin 5 | **`VREF+` is tied to GND.** The ADC and DAC have no reference, so every ADC result (current sense, VREFINT, temperature) is meaningless. This very likely explains the unexplained readings in [`ADC_Current_Monitor_Troubleshooting.md`](../firmware/HostControllerA/docs/archive/ADC_Current_Monitor_Troubleshooting.md) (0x0FF/0x1FF, 16·N−1 patterns, no match with the 20–30 mV seen on the scope). | Netlist: `U302.5(VREF+)` is on `GND`. The PCB pad 5 net is `GND`. CubeMX DB: LQFP48 pin 5 = `VREF+`, pin 6 = `VDD` (VDD/VDDA). The STM32G0 datasheet requires VREF+ to be within 2 V…VDDA while the ADC is used (needs datasheet check for the exact limit). | **Reworked on the prototype host board:** pin 5 rewired to VDD, and current sensing now works. The schematic and PCB are not updated yet. Other boards: lift pin 5 or cut its GND connection, then strap it to pin 6 (VDD/VDDA) with 100 nF (+1 µF) to GND. Next revision: route `VREF+` to `+3.3V` with local 100 nF + 1 µF. Then repeat the known-voltage ADC test in the troubleshooting doc. | Confirmed (schematic + PCB); fixed by rework on the prototype |
| H-1 | High | Host Controller / U302 pins 30, 31 | **Both analog sense nets land on pins that have no ADC input.** `CURRENT_SENSE_FLTR` goes to PC6 and `VOLTAGE_SENS_FLTR` goes to PC7. The firmware reads `ADC1_IN10` on PB2 through a bodge from PC6 to PB2 (TP301 / MCO net). PC7 cannot be measured at all. | CubeMX DB: PC6 = LPUART2_TX/TIM2_CH3/TIM3_CH1/UCPD1_FRSTX; PC7 = LPUART2_RX/TIM2_CH4/TIM3_CH2/UCPD2_FRSTX (no ADC). PB2 = ADC1_IN10 and PB0 = ADC1_IN8 (PB0 is unconnected). `main.h`: `CURRENT_SENSE_Pin` = PB2. | Next revision: route current sense to PB2 (IN10) and voltage sense to PB0 (IN8, currently free). Keep PC6/PC7 unconnected or give them other uses. | Confirmed |
| H-2 | High | Host Controller / R304, C306, PC7 | **5 V VBUS goes straight to an MCU pin with no divider.** A pin in analog mode (the `.ioc` sets PC7 to `GPIO_Analog`) must stay below VDDA. The 5 V pushes a small injected current into the pin permanently. Even if it were an ADC pin, it would read full scale. | Netlist: `R304` goes from `VBUS_IN` to `PC7`, `C306` 1u to GND, and there is no bottom resistor. The value is 10k in the schematic and **100k on the PCB**. Already flagged in `USB_PD_Feasibility.md` §4. | Add a bottom resistor to form a divider (for example 100k / 68k, which gives 2.0 V at 5 V and 8.1 V at full scale), and move it to PB0 (see H-1). Current boards: remove R304 until a divider is added. | Confirmed; the injected current is a datasheet check |
| H-3 | High | Display / Q501–Q505, PD3/PA15/PD1/PD2/PD0 | **The slot P-FETs cannot be fully turned off.** The source is on `VDD_LED` = `VDD` ≈ 3.70 V (D501 shorted), and the gate is driven directly by a 3.3 V push-pull GPIO. So Vgs(off) ≈ −0.4 V (range −0.3 … −0.5 V over the tolerances). Si2333CDS Vgs(th) is −0.4 V min … −1.0 V max at 250 µA, and its magnitude falls with temperature. A worst-case part conducts hundreds of µA in the "off" state, which is enough to make "off" digits and matrix rows glow. There is no gate resistor and no gate pull-up to VDD_LED. | Netlist: `Q50x.2(S)` on `VDD_LED`, `Q50x.1(G)` directly on `DISPLAYx_EN` (MCU pins 41/37/39/40/38). Si2333CDS datasheet p.2: VGS(th) −0.4…−1 V, tempco +2.6 mV/°C. `Display_Board_Purchasing.md` predicted the same. When on, Vgs ≈ −3.7 V gives RDS(on) ≤ 35–45 mΩ, which is fine. | Pick one: **(a)** configure `DISPLAY_x_EN` as **open-drain** and add 10k pull-ups from each gate to `VDD_LED` (needs PD0–PD3 and PA15 to be FT/5 V-tolerant; check the G0B1 pin table). This also keeps the FETs off during reset. **(b)** Fit a Schottky at D501 so VDD_LED ≈ 3.3–3.4 V. Its Vf falls at low current, so the margin is small. **(c)** Next revision: add an NPN/N-FET gate driver with a gate pull-up to VDD_LED (the design that `Display.md` already describes). **2026-09-24: no glow visible on the prototype host board**, so (a) and (b) are not needed now; keep (c) as an improvement for the next PCB revision, since the margin depends on each FET's threshold and on temperature. | Confirmed (topology); glow not observed on the prototype; next revision |
| H-4 | High | Host Controller / R301, R302 | **The schematic has no I2C pull-ups.** R301/R302 (to +3.3V on SDA/SCL) have the value `dnp`. The firmware sets PA9/PA10 to `GPIO_NOPULL`. `Display.md` says 2.2k pull-ups are required, or the bus latches BUSY. | Netlist: R301/R302 value `dnp` on both builds. `Display_Board_BOM.csv`: "leave unfitted" (which is correct for display boards only). | Put `2k2` in the schematic for the host, and add a variant/DNP field so they are fitted on the host only. Check that the host board in use actually has them. | Confirmed (schematic); current board: Measure |
| H-5 | High | Root / J106, R101, U601/L601; system | **The power budget exceeds USB defaults, and nothing enforces a limit.** The worst case is ≈ 1.4–2.7 A for six boards at full brightness with Wi-Fi TX (see the load table). The CC pins are read by nobody (UCPD not enabled), so the firmware cannot tell a 500 mA port from a 3 A port. The INA180 channel saturates at ≈ 1.3 A (3.3 V ÷ 2.5 V/A), and the ADC is broken anyway (C-1). | Load table above. The `.ioc` does not enable UCPD1. `R101` 0.05 Ω 1206 dissipates 0.36 W at 2.7 A (typical 1206 rating 0.25 W; needs datasheet check for the fitted part). | Once C-1 is fixed, read the CC voltage (Rp level) and cap brightness in firmware, or limit brightness/segment count globally. Specify a 5 V/3 A supply. Next revision: consider a 2512 shunt or a lower gain (INA180A1), and see `USB_PD_Feasibility.md` for higher-voltage options. | Measure |
| M-1 | Medium | Power Supply / L601, U601 | **The inductor is far from the datasheet recommendation, has low saturation current, and has a footprint mismatch.** The fitted part is 33 µH `SRR6838A-330M` with Isat 1.02 A (per `Display_Board_Purchasing.md`). The TPS54202 table recommends 10 µH for 3.3 V out at 28 V in; at 5 V in, the Eq. 8 minimum is only ≈ 3–6 µH. The TPS54202 high-side current limit is 2.5–3.9 A, so on overload or short the inductor saturates long before the regulator limits. The host rail (LEDs + Wi-Fi ≈ 0.6–0.8 A) leaves little margin to 1.02 A. The ripple is only ≈ 60 mA, so the device runs in pulse-skip mode (300 mA peak threshold) up to fairly high loads. The schematic footprint is `L_Bourns_SRP7028A`, not the SRR6838A land pattern. | TPS54202 datasheet Table 7-2 (3.3 V: L = 10 µH, COUT = 44 µF, C6 = 56 pF), Eq. 8, I(LIM_HS) 2.5–3.9 A, I(SKIP) 300 mA. Schematic value `SRR6838-33u`, footprint `L_Bourns_SRP7028A_7.3x6.6mm`. | Use a 6.8–10 µH shielded inductor with Isat ≥ 3 A (≥ 2.5 A for TPS54202) on a matching footprint. Check the transient response with the 2×22 µF + 4.7 µF output (below the 44 µF in the table once DC bias is counted) and C608 47 pF. | Datasheet (confirmed values); stability: Measure |
| M-2 | Medium | Power Supply / U601 swap | **The TPS54302 → TPS54202 swap is pin-compatible**, but check the following. The TPS54202 is rated 2 A (the TPS54302 3 A), and runs at 500 kHz (not 400 kHz). EN floats to enable (internal pull-up, **confirmed**). VIN min is 4.5 V, UVLO rising is 4.2 V typ / **4.4 V max**, falling 3.7 V typ. A display board at the end of a daisy chain carrying ≈ 2 A can see VBUS near or below 4.4 V after cable and connector drops, and then fails to start. | TPS54202 datasheet: pinout GND, SW, VIN, FB, EN, BOOT = pins 1–6, which matches the netlist. "Float the EN pin to enable". Electrical table: UVLO, 0.596 V ±2.5% reference. The resulting VDD is 3.61–3.79 V. | Measure VBUS at the last board under full load. Keep the daisy chain short or use thicker wire. Next revision: consider feeding the chain from both ends, or a star connection. | Datasheet confirmed; margin: Measure |
| M-3 | Medium | Root / J105 AUX_POWER, VBUS_IN | **The AUX power header is wired straight onto USB VBUS.** Supplying J105 while USB is plugged in back-feeds the PC or charger. There is also no reverse-polarity protection (a 2-pin 2.54 mm header is easy to reverse, and TPS54x02 VIN abs min is −0.3 V), no fuse or polyfuse, and no VBUS TVS. | Netlist `VBUS_IN`: J105.2, J106 VBUS pins, R101, R304, U101.IN+. D101/D102 are only on D+/D−. | Add an ideal-diode OR, or a Schottky from each source, a polyfuse, and a VBUS TVS (for example SMF5.0A). | Confirmed |
| M-4 | Medium | Host Controller + all boards / PB8, J102/J104 pin 9, Q701 | **`LOW_POWER_ENABLE` is driven push-pull by every board.** The net is bussed to every board. The host's `main.c` configures PB8 as a push-pull output (driven low), and the DisplayController firmware used to share that configuration. As soon as the host drives it high, it shorts against five low outputs. Since 2026-09-24 the host drives it (switch 2 toggles low brightness); since 2026-09-25 the DisplayController is a separate CubeMX project whose `.ioc` leaves PB8 in analog mode. | Host `main.c` `MX_GPIO_Init`: `LOW_POWER_EN_Pin` is `GPIO_MODE_OUTPUT_PP`, reset level low. `DisplayController.ioc`: `LOW_POWER_ENABLE` is `GPIO_Analog`. | Next revision: add a series resistor (1k) at each board's PB8. | Confirmed; firmware fixed 2026-09-24, series resistor still open |
| M-5 | Medium | Display + Light Sensor / LED_BRIGHTNESS, U503/U507/U511/U515, Q506–Q509, R504/R507/R510/R513 | **Analog brightness control has little headroom at both ends.** (1) The `LED_BRIGHTNESS` divider gives ≈ 1.17 V in bright light, 0.49 V with Q701 on, and ≈ 0.04 V in the dark (LDR 2 MΩ). At 40 mV, the op-amp offset (a few mV) and the ground offset along the daisy chain (LED return current in the cable, estimated tens of mV) are a large fraction of the signal. Remote boards and the four driver groups will then differ visibly, and remote boards may go dark. (2) The resulting SCT current is well below the SCT2024's regulated range of 5–45 mA. (3) If REXT sits near 1.2 V, the BC847 saturates at the bright end (V_E ≈ 1.17 V) and the loop loses control. (4) `R504`/`R507`/`R510`/`R513` are still "4k7 / 10k". (5) There is no filter capacitor on `LED_BRIGHTNESS`, which runs on the cable next to SCL/SDA. | Netlist: R701 4k7 + R703 (LDR 4k–2M) from 3.3V, R702 470k from 3.3V, R704 1k5 + R705 3k2 to GND (Q701 shorts R705). SCT2024 datasheet: recommended IOUT 5–30 mA at VDD 3.3 V. The REXT pin voltage is not stated. | Measure the REXT pin voltage and TP501–TP504 (emitters) at both light extremes. Add a minimum-brightness offset (for example a resistor from 3.3V to the bottom of the divider) and 100 nF at each op-amp input. Next revision: send brightness digitally over I2C and generate it locally (DAC or filtered PWM) on each board. Fix the R504 value. | Measure |
| M-6 | Medium | Display / U506, U508, U509 (FYM-7571AUHR-11) | **The matrix polarity needs checking.** The schematic drives `COL1..5` from the high-side P-FETs (anodes) and `ROW1..7` into SCT sinks (cathodes). TME lists FYM-7571AUHR-11 as "common electrode: cathode". If the custom `JPDisplays:FYM-7571A` symbol assigns anode/cathode wrongly, the matrix stays dark (reverse biased, no damage at 3.7 V). | TME parameters: cathode, VF 1.9–2.5 V, 20 mA. The Foryard datasheet could not be downloaded. The symbol pins are all type `input`, so no polarity is encoded. | Compare the symbol with the Foryard pinout drawing, or light one dot with a bench supply and a resistor. If it is already working on the host board, record that and close this item. | Datasheet |
| M-7 | Medium | ST67W611M1 / U201, U602 | **The 3.3 V LDO has limited margin for Wi-Fi TX bursts.** MCP1825S is a 500 mA LDO. The host 3.3 V load is roughly ST67 TX peak (≈ 300–400 mA, not verified) + ~45 mA logic. Dropout at 500 mA is ≈ 210 mV typ / 350 mV max (needs datasheet check) against 400 mV of headroom (3.7 → 3.3 V). The decoupling of 3×10 µF (one per VDD pin) matches the ST recommendation, and the supply range is 2.97–3.63 V. | ST wiki: one 10 µF per VDD pin. DB5452: input 2.97–3.63 V. Netlist: C201–C203 10u on +3.3V, no 100 nF. | Measure the 3.3 V droop during TX (scope on C201). If it droops below ≈ 3.1 V, raise VDD slightly (R602 18k → 3.9 V, which also worsens H-3) or use a 1 A LDO. | Measure / Datasheet |
| M-8 | Medium | Display + Light Sensor / U503/U507/U511/U515, Q506–Q509, Q701 | **Low brightness raises the current in the dark instead of lowering it.** In bright light low brightness roughly halves the LED current (see [Measured current](#measured-current-host-board-2026-09-24)). In a dark room it dims the LEDs but nearly doubles the board current. With all LEDs off, both states draw the same 12–13 mA, so the PB8/Q701 path itself adds nothing, and with no remote boards connected M-4 contention is ruled out. The extra current, about the size of the whole 13 mA baseline, is far above what the LEDs can take in the dark: `LED_BRIGHTNESS` ≈ 40 mV normal and ≈ 13 mV low gives about 8.5 µA and 3 µA per BC847 emitter, or 0.1–0.25 mA peak per segment in normal mode. First suspect: the current-set loop (L-4) oscillates at a very low bias. **2026-10-03: TP501–TP504 (BC847 emitters) were scoped with no oscillation at any light or brightness level, so this is now less likely.** **The `REXT` pins of all four SCTs (U501, U505, U510, U513) oscillate at about 2 MHz, 100 mV pp, only in the dark** (2026-10-03; whether it differs between normal and low brightness was not recorded). The emitters stay clean because a BC847 collector is a current source: its voltage can swing without moving the emitter. That points to the SCT's own `REXT` regulation instead of the op-amp loop. The SCT holds `REXT` at an internal reference, expecting a resistor to GND. Here it sees a high-impedance collector, at µA currents far below its 5 mA minimum, so its internal amplifier may lose its phase margin. Whether this explains the extra current is open: the oscillation could raise the SCT IDD, or disturb the INA180 (outcome (b)). At a few µA the BC847's gm and fT collapse, adding phase lag near the MCP6006's 1 MHz crossover, and the 13 mV setpoint is close to the op-amp offset. Two possible outcomes: **(a)** the oscillation really draws current (op-amps, SCT `REXT` regulation); **(b)** the current is normal, but high-frequency noise on the 0.65 mV shunt signal is rectified in the INA180 input stage and reads as DC. | Measured 2026-09-27/28, host board only: lit LEDs in the dark, normal vs low, current nearly doubles; all LEDs off in the dark, 12–13 mA in both states. Divider values from M-5. 2026-10-03: no oscillation on TP501–TP504 at any level; all four SCT `REXT` pins oscillate at ≈ 2 MHz, 100 mV pp, only in the dark. | **Measure first:** (0) compare the `REXT` oscillation in the dark between normal and low brightness, and find the light level where it starts; (1) an external USB meter in series with VBUS, normal vs low with LEDs lit in the dark, to tell (a) from (b); (2) scope TP501–TP504 and one `REXT` pin, AC-coupled, in dark + low; (3) with low brightness on, uncover the LDR slowly: an abrupt drop in current at some light level points to the loop. **Bench fixes, in order:** 100 nF on each MCP6006 supply; 470 Ω–1 kΩ in series with each BC847 base; ≈ 1 nF from each op-amp output to its inverting input. Next revision: the minimum-brightness offset from M-5 keeps the stage out of the µA region. | Observed; cause: Measure |
| L-1 | Low | Host Controller / SW301, SW302 | **Button net names are swapped relative to the firmware.** In the schematic, `SWITCH_1` goes to pin 25 (PB13) and `SWITCH_2` to pin 24 (PB12). In `main.h`, `SWITCH_1` = PB12 and `SWITCH_2` = PB13. | Netlist vs `main.h`. | Rename in either place so they agree. | Confirmed |
| L-2 | Low | Host Controller / U301 | **The EEPROM part disagrees with the firmware.** The schematic has `AT24CS01-STUM` (1 Kbit, 128 B). The firmware driver is `Eeprom24AA04` (4 Kbit, and "answers on 0x50–0x57"). The SOT-23-5 pinouts match (SCL, GND, SDA, VCC, WP). WP is tied to GND, so writes are enabled. There is no local decoupling capacitor for U301. | Netlist: `U301.5(WP)` on GND. `User/Inc/Device/Eeprom24AA04.hpp`. | Put the fitted part in the schematic. The settings image is 256 B, so the 512-byte 24AA04 (the verified part) is required; a 128-byte AT24CS01 would not hold it. Add 100 nF at U301. | Confirmed / Datasheet |
| L-3 | Low | Display / U501, U505, U510, U513 | **Display power-up and reset behaviour.** OE/ has an internal 400k pull-up and LA/ a 400k pull-down, so the outputs are off and latched during MCU reset. But `MX_GPIO_Init` drives `SCT_ENABLE` (PB7) **low** before any data is latched, which can briefly show random latch contents. The P-FET gates float during reset (see H-3 (a)). | SCT2024 datasheet: R_UP on OE/ 400 kΩ, R_DOWN on LA/ 400 kΩ. `main.c`: PB7 reset level low. | Set the PB7 initial level high in CubeMX, and enable only after the first latch. | Confirmed |
| L-4 | Low | Display / U503…U515, MCP6006 | There is no decoupling on the op-amp supplies, and no base resistor between the op-amp output and the BC847. The loop (op-amp, emitter follower, 1k feedback) could oscillate with the REXT pin capacitance. | The netlist has no capacitors on the MCP6006 V+ pins. | Add 100 nF per op-amp. Look for oscillation at TP501–TP504. Suspected cause of M-8 (observed 2026-09-28); 2026-10-03: the emitters are clean, but all four `REXT` pins oscillate at ≈ 2 MHz in the dark (see M-8). | Measure |
| L-5 | Low | Root / J106 shield, D101/D102 | The USB-C shield is marked no-connect. The D+/D− TVS parts are the generic `D_TVS` with no part number, so the capacitance for full-speed USB is not checked. VBUS has no TVS (see M-3). | Netlist: `J106.S1` has a no-connect flag. | Tie the shield to GND (directly, or through 1 MΩ ‖ 4.7 nF). Pick a low-capacitance USB TVS (for example USBLC6-2 or PESD5V0 with ≤ 1 pF). | Confirmed |
| L-6 | Low | Root / C602, display boards | **VBUS capacitance** is 10 µF on the host plus 10 µF on each display board (plus the buck soft-start load), about 60 µF in total. That exceeds the USB 2.0 10 µF inrush guideline. Type-C chargers usually tolerate it. | Netlist: C602 10u/35V on VBUS on every build. | Accept for a mains-supplied product, or add soft-start or load switches if hot-plug on a PC port is required. | Datasheet |
| L-7 | Low | Host Controller / Y301, R303, C303/C304 | **The crystal circuit is inconsistent across documents.** The schematic has Y301 at 24 MHz, R303 with value `x`, and 20 pF caps. The BOM doc lists an 8 MHz ABM3B with 0R. The `.ioc` sets `HSE_VALUE` = 8 MHz but runs from HSI, so HSE is unused. | Netlist, `Display_Board_BOM.csv`, `.ioc`. | Decide DNP or a value, and fix R303. If HSE is later used, the capacitors must match the crystal's CL. | Confirmed |
| L-8 | Low | Host Controller / PC14, PC15 | **The RTC runs from the LSI, which is not a precise clock.** PC14/PC15 (LSE) are unconnected. A dangling `OSC_32_OUT` label is left on the root sheet. The project already measures LSI drift and syncs from the network. | ERC: `label_dangling OSC_32_OUT`. Netlist: PC14/PC15 unconnected. | Next revision: add a 32.768 kHz crystal with the proper load caps on PC14/PC15. | Confirmed |
| L-9 | Low | PCB vs schematic | **The PCB is out of sync with the schematic.** The PCB has R304/R305 = **100k**, the schematic has 10k. The troubleshooting doc's 100k/1 µF (τ = 100 ms) matches the PCB. | `AstroWeather.kicad_pcb` footprint values. | Run *Update PCB from Schematic* before the next fab, and decide on the value. | Confirmed |
| L-10 | Low | Docs / Display.md | **`Display.md` describes hardware that is not there.** It says the slot FET is "switched on hard through a BC847 but turned off only by its gate pull-up resistor". In the schematic, the gate is driven directly from the MCU and has no pull-up. The BC847s are in the REXT current-set stages. The ghosting explanation and the 10 µs settle time are based on that wrong picture. | Netlist `DISPLAYx_EN` nets: only the MCU pin and the FET gate. | Update the doc. The residual "off" glow is H-3, not slow turn-off. | Confirmed |
| L-11 | Low | ERC | There are 21 ERC errors. All are expected or cosmetic: power flags missing on `+3.3V`/`VBUS`/`VDD`; ST67 XTAL32K pins without no-connect flags; U510 Out5–7 unused; the `SCT_SDO` hierarchical pin dangles (end of chain); `VDD`/`VLED` and `3.7V`/`+3.7V` alias pairs; many "net not bus member" warnings. | `kicad-cli sch erc` report. | Add PWR_FLAGs and no-connect markers so that real errors stand out. | Confirmed |
| I-1 | Info | Host Controller / UCPD1 | PA9/PA10 (I2C1) double as the UCPD1 dead-battery pins (DBCC1/DBCC2). The external 5.1k Rd on CC (R102/R103) is fine for a 5 V-only sink. Whether the internal dead-battery Rd briefly appears in parallel during reset, while the I2C pull-ups hold DBCC high, is unclear. See `USB_PD_Feasibility.md` for the PD blockers. | CubeMX DB: `UCPD1_DBCC1` on pin 29, `UCPD1_DBCC2` on pin 32. `.ioc`: `DisableDeadBatterySignals`. | No action for 5 V operation. | Datasheet |
| I-2 | Info | Light Sensor | The MCU never reads the light sensor. `LED_BRIGHTNESS` feeds only the op-amps and TP701. `LOW_POWER_ENABLE` (PB8 → Q701) is driven since 2026-09-24: `display low on|off` and switch 2 (`LowBrightness`). | grep of `User/`, and the netlist. | Optional: route `LED_BRIGHTNESS` to an ADC pin (after C-1) for logging or auto-dimming. | Confirmed |
| I-3 | Info | Host Controller | The unused pins PB0, PB4, PC14 and PC15 are left in their reset (analog) state, which is fine. PB0 is the natural home for the voltage sense (H-1). | Netlist. | — | Confirmed |
| I-4 | Info | `Controller.kicad_sch` | This is an orphan sheet (STM32G030F6P) that is not referenced by the root. | Root `Sheetfile` list. | Delete it or move it out of the project folder. | Confirmed |

## Per-subsystem notes

### STM32G0B1 (U302)

- **Supplies:** VDD/VDDA (pin 6) has 100 nF (C301) and 4.7 µF (C302), which matches ST's recommendation. VBAT (pin 4) is tied to +3.3V. **VREF+ (pin 5) is on GND (C-1)**; the prototype is reworked to VDD.
- **Reset and boot:** NRST has 100 nF (C305) and goes to SWD pin 5. BOOT0 shares PA14/SWCLK and is set by option bytes, so no strap is needed. SWD J103: 1 = 3.3V, 2 = SWCLK, 3 = GND, 4 = SWDIO, 5 = NRST, 6 = NC.
- **USB:** PA11/PA12 go directly to J106 D−/D+ (both rows), with TVS D101/D102 to GND. The pull-up is internal and series resistors are not needed for the G0 FS PHY. The firmware uses HSI48/CRS, so no crystal is needed.
- **5 V on MCU pins:** the only 5 V source is H-2 (PC7). I2C, `LOW_POWER_ENABLE` and `LED_BRIGHTNESS` on the cable are all 3.3 V domain.
- **Firmware pin map vs schematic:** everything matches (ST67 SPI1/USART2/CHIP_EN/RDY/CS/BOOT, SPI3 PB3/PB5, LA PB6, OE PB7, DISPLAY_1..5_EN = PD3/PA15/PD1/PD2/PD0, LED1 PC13, LED2 PB9, ADDR PB10/PB11/PB14, I2C PA9/PA10, USB), **except** CURRENT_SENSE (PB2 in firmware, PC6 in the schematic; H-1), the button names (L-1), and PC7, which the firmware sets to analog but cannot convert.
- **LED1 on PC13:** PC13 is in the backup domain (low drive, max about 2 MHz). With the 2k2 series resistor, the current is below 1 mA, which is fine.

### Display (U501/U505/U513 SCT2024, U510 SCT2167, Q501–Q509, U503…U515)

- **Segment mapping:** the segment-to-SCT-output mapping in the netlist matches the tables in `Display.md` for all four numeric displays, and matrix columns 1–21 map to U505 Out0–15 and U510 Out0–4. The chain order is U501 → U505 → U510 → U513, 56 bits in total, which matches the 7-byte frame.
- **Logic levels:** SCT VDD ≈ 3.2 V (3.3 V through 10 Ω). VIH = 0.7·VDD ≈ 2.25 V, so the 3.3 V MCU drive is fine. LA/ latches when low and is transparent when high, which matches the firmware sequence.
- **SPI clock:** `SCT_CLK` passes through R502 1k and C504 10 pF (plus four clock-input loads), giving τ ≈ 20–40 ns. At the current 1 MHz this is fine. Above about 4 MHz, check the edges (the SCT inputs are Schmitt triggers).
- **LED headroom:** VDD_LED 3.7 V − Si2333 drop (< 20 mV) − red LED Vf 1.8–2.5 V leaves 1.2–1.9 V at the SCT output. The dropout is about 0.55 V at 20 mA and less at 3–8 mA, so there is enough headroom. Power per SCT2024 at the highest estimated current is 16 × 7.5 mA × ≈ 1.8 V ≈ 0.22 W, and at 88 °C/W (SSOP24) that is about +19 °C, which is fine.
- **Duty cycle:** 5 slots at 250 Hz give a 1/5 duty and a 50 Hz frame. The peak current of 3.7–7.5 mA gives an average of 0.75–1.5 mA per segment, which may be dim in daylight. Displays are rated at 20 mA DC.
- **Slot switches:** see H-3.

### Power Supply (U601, U602)

- **VDD:** 3.70 V nominal, as computed from the divider. The input caps (10 µF/35 V + 100 nF) are adequate for 5 V in. BOOT has 100 nF (C601). EN floats (no UVLO divider), which is acceptable. See M-1 and M-2 for the inductor and the input range.
- **MCP1825S:** the pinout (1 VIN, 2 GND/tab, 3 VOUT) matches the netlist. Cin is 4.7 µF and Cout 1 µF, plus about 45 µF downstream. Dissipation is (3.7 − 3.3) × 0.45 A ≈ 0.18 W, which is fine. For the dropout margin, see M-7.

### USB-C input and current sense (root sheet)

- **CC:** 5.1k Rd on both CC lines (R102/R103), which is correct for a 5 V sink. The firmware does not read the advertised current (H-5).
- **INA180A2:** V+ is 3.3 V (C101 100 nF). The common-mode of 5 V is inside the −0.2…26 V range. The gain of 50 with the 50 mΩ shunt gives 2.5 V/A, so full scale is ≈ 1.3 A. The output feeds R305 (100k on the PCB) and C307 1 µF, τ = 100 ms. With a 160.5-cycle sample time and the 1 µF reservoir, the source impedance is acceptable.

### I2C bus (J101, J102/J104, U301)

- **Topology:** a daisy chain through the 10-pin connectors. Pins 1/3/5/7 are GND, 2 is SCL, 4 is SDA, 6/8 are VBUS, 9 is `LOW_POWER_ENABLE`, 10 is `LED_BRIGHTNESS`. There should be one pull-up pair, on the host only (H-4). With 2.2 kΩ and ≈ 300 pF, the rise time is ≈ 0.85 × R × C ≈ 0.56 µs, below the 1 µs Standard-mode limit.
- **Levels:** all 3.3 V, and PA9/PA10 are 5 V-tolerant anyway.
- **Ground noise:** the LED return current shares the GND pins. The resulting offset is small compared with the I2C VIL (≈ 1 V) but not small compared with `LED_BRIGHTNESS` (M-5).

### ST67W611M1 (U201)

- **Power:** VDD33 and both VDDIO pins are on +3.3V, with one 10 µF per VDD pin, as ST recommends.
- **CHIP_EN:** 33k pull-up with 100 nF (τ ≈ 3.3 ms), and PA0 push-pull. At power-up the module is enabled by the RC while the MCU is still in reset, then the firmware takes over. That is acceptable.
- **BOOT (PB1):** no external pull-down, so it floats during MCU reset. Check the module's internal default (datasheet).
- **SPI and UART:** SPI1 at 2 MHz and USART2 at 921600 baud, all at 3.3 V. SPI_RDY on PA4 has an internal pull-down.
- **XTAL32K pins:** left open (ERC flags them).
- **Antenna:** the module variant (-B PCB antenna or -U connector) is not recorded in the schematic. The antenna keep-out was not reviewed (PCB layout is out of scope).

### Light Sensor (Q701, R701–R705)

- **Divider:** described in M-5. Q701 (Si2374DS, N-channel) is driven from PB8 at 3.3 V, which is fine. Its gate has no pull-down, so it floats in reset. Only the brightness is affected.
- **Firmware use:** the sensor is not read; `Q701` is driven from PB8 by `display low` and switch 2 (I-2).

## Measure on the bench

1. **VREF+ (U302 pin 5):** confirm 0 V. After the rework, confirm 3.3 V, then apply 0.33 V, 1.0 V and 1.65 V to PB2 and check for raw ≈ 410, 1241 and 2048.
2. **Slot FET gate-source voltage when off:** measure V(VDD_LED) − V(gate) with the MCU driving high, and V(VDD_DIGx) on an "off" slot. In a dark room, check "off" digits and matrix rows for glow. Log VDD (expected 3.61–3.79 V).
3. **REXT pin voltage** on each SCT, and **TP501–TP504** (BC847 emitter) at bright, dark and Q701-on light levels. Check for BC847 saturation (Vce < 0.2 V) and op-amp oscillation (scope, AC-coupled). Dark + low brightness is the most likely case to oscillate (M-8). *2026-10-03: TP501–TP504 checked, no oscillation at any level. All four `REXT` pins oscillate at ≈ 2 MHz, 100 mV pp, only in the dark. Vce and op-amp outputs are still open.*
4. **Segment current:** put a series ammeter (or a shunt) in one segment path at bright and dark light levels, to establish the real SCT gain.
5. **Rail ripple and droop:** VDD (3.7 V) and +3.3V at C201 during Wi-Fi TX bursts and slot switching. 20 MHz bandwidth, short ground spring.
6. **VBUS at every board** in the chain with all segments lit at full brightness (worst case). Check that it stays at or above 4.5 V at the last board (TPS54202 VIN min).
7. **Total VBUS current** at J106 at full load (use an external USB meter while the ADC is untrustworthy). Measure the L601 temperature and ripple current. Look for inductor saturation (peaked triangle on the SW-node current) at maximum load.
8. **I2C rise time** on SCL/SDA at the host and at the farthest board (target < 1 µs at 100 kHz). Confirm that pull-ups are fitted on the host only.
9. **PC7 voltage** with USB connected (expected ≈ 5 V through R304). Remove R304 until the divider is added.
10. **`LOW_POWER_ENABLE`:** check its level with all boards connected, and confirm that no board fights the host.
11. **LED_BRIGHTNESS at each remote board** relative to that board's GND, in darkness with the display fully lit, to size the ground offset (M-5).
12. **Matrix polarity:** if it has not been seen lit yet, bias one dot with a bench supply through 1 kΩ.
13. **Low brightness in the dark (M-8):** VBUS current on an external meter next to the INA180 reading, normal vs low, all LEDs lit, dark room.

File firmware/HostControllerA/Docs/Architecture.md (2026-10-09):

# Firmware Architecture

## Overview

This page describes how the firmware is put together: how it boots, which
tasks run and how they talk to each other, which peripherals and pins it uses,
which interrupts it enables and at what priority, what the unit tests cover,
and which code is present but unused. The feature
documents listed in the [README](../README.md#documentation) describe each
subsystem in depth.

The firmware is C++17 on top of the STM32CubeMX-generated C code for an
STM32G0B1CETx (Cortex-M0+, 16 MHz from a 24 MHz crystal through the PLL,
512 KB flash, 144 KB RAM),
FreeRTOS through CMSIS-RTOS2 and the ST67W6X network driver in its T01
architecture, where TCP/IP and TLS run in the Wi-Fi module. Application
code lives under `User/` and, for the parts shared with the DisplayController
firmware, under `../Common/` (see [Shared Code](#shared-code)); CubeMX owns
`Core/`, `Drivers/`, `Middlewares/`,
`USB_Device/` and `ST67W6X_Network_Driver/`, and application changes
there stay inside `USER CODE` sections (see
[Development.md](../../Docs/Development.md#cubemx-compliance)).

## Boot Sequence

`main()` in `Core/Src/main.c` runs the generated sequence:

1. `HAL_Init()`, `SystemClock_Config()`.
2. `MX_GPIO_Init()`, `MX_DMA_Init()`, `MX_SPI1_Init()`, `MX_USART2_UART_Init()`,
   `MX_SPI3_Init()`, `MX_I2C1_Init()`, `MX_TIM2_Init()`, `MX_ADC1_Init()`,
   `MX_RTC_Init()`. The `Check_RTC_BKUP` user section returns early from
   `MX_RTC_Init()` when backup register DR0 holds the `TIME` marker, so a reset
   keeps the calendar (see [RTC.md](RTC.md)).
3. `osKernelInitialize()`, then `defaultTask` is created.
4. `AstroWeather_Init()` in `User/Src/AstroWeather.cpp`, from the
   `RTOS_THREADS` user section.
5. `osKernelStart()`.

All of `AstroWeather_Init()` runs before the scheduler starts. The objects it
uses are file-scope statics, constructed before `main()`; their `Mutex` members
create their FreeRTOS mutexes from static storage at that point.

### Init order

`AstroWeather_Init()` first creates the timer of the `activityLed()`
`PulseLed` on `LED_2`, then, in order (`LED_1`, the heartbeat, needs no setup:
the refresh interrupt drives it once `localBoard` starts):

1. `LogService` `init()` (creates the log queue) and `start()`.
2. `Display::detectBoardAddress()` reads the host's `ADDR_0`..`ADDR_2` straps,
   as a display board does, and `display.setLocalAddress()` takes the result
   before anything submits: it decides which forecast block the local board
   shows and which remote address is skipped (see
   [AstroRefresh.md](AstroRefresh.md#display-mapping)). The address is logged,
   with a warning if it is outside `0x10`–`0x15`, but USB CDC has not
   enumerated yet, so the line is normally lost (the warning is also kept in
   `errors`); `status` shows the address as `host` on the `remote` line.
3. `settingsStore.load()` reads the EEPROM; the outcome, not the values, is
   logged. This works before the scheduler because EEPROM reads take no
   `osDelay` and the bus mutex is uncontended. A saved HSI trim other than 64
   is applied at once (`HsiTrim::set()`, logged as `HSI trim <n>`); it has no
   effect, since the host runs from its crystal and HSI16 clocks nothing
   ([TimelineSync.md](../../Docs/TimelineSync.md#the-hosts-clock)).
4. `CurrentSenseTask`: logging and display flags from settings, the display,
   then `start()`.
5. `ConsoleService`: `init(&display)`, EEPROM and settings pointers, `start()`.
6. `LowBrightness::set()` applies the saved low brightness to `PB8`, before the
   displays light up.
7. The local board gets the "no data" state (`Display::noDataState()`, see
   [Display.md](../../Docs/Display.md#time-blank-and-no-data)) but does not show it yet: the first
   slot-test frame (`Display::slotTestState(0)`) is shown instead, then
   `localBoard.start()` enables the SCT outputs and starts TIM2, whose
   interrupt refreshes the board, keeps the refresh timeline and drives the
   `LED_1` heartbeat from then on. `Display` holds back every
   local submit until `MainLoopTask` has run the boot screens.
8. `ClockTask`: display flag and trim from settings, the display, `start()`. A
   saved trim beyond ±1000 ppm, measured for the LSI the RTC ran from before,
   is replaced by 0 with a warning; an error is logged if the RTC rejects
   the trim ([RTC.md](RTC.md#trimming)).
9. `DisplaySyncTask`: `init(&i2c1Bus, &display)`, `start()`; after
   `localBoard.start()`, since the sync carries its refresh timeline
   ([TimelineSync.md](../../Docs/TimelineSync.md#syncs-from-the-host)).
10. `SetSt67CredentialSource(&settingsStore)`, then `StartSt67HttpFetchTask()`.
   The credential source must be set first, since the fetch task reads the
   credentials on every connect.
11. `AstroDataRefreshTask`: `init(&display)` restores the last successful
    refresh time from backup register DR1 when the RTC is set, then `start()`.
12. `MainLoopTask`: `init(activityLed(), &settingsStore, &display)` (switch 2
    saves low brightness), `start()`. Its first act once the scheduler runs is
    `display.runBootScreens()`: each `DISPLAYx_EN` slot lit on its own for
    200 ms, then `AdNN` (the host's strap address) on numeric display 1 for
    2 s, then the local board's own state, which clients have kept writing
    meanwhile. See [DisplayController Architecture](../../DisplayController/Docs/Architecture.md#screens).
13. `SwitchInput::attach()` routes the `SWITCH_1`/`SWITCH_2` EXTI interrupts to
    `MainLoopTask` as thread flags.

`defaultTask` initialises the USB device (`MX_USB_Device_Init()`) once the
scheduler runs and then ends itself (`osThreadExit()` in the `USER CODE 5`
section): USB runs from its interrupt, and the idle task returns the stack to
the heap. CubeMX does not allow removing the task, so this keeps it from ever
waking again.

## Shared Code

The remote display boards run the separate
[DisplayController](../../DisplayController/README.md) project, an STM32G070.
Code both images need lives in [`../Common`](../../Common/README.md) and is
compiled into each project against that project's HAL, `main.h` and FreeRTOS
configuration, so the two CubeMX projects keep the same labels for the pins it
uses. It is documented once, for both, in [firmware/Docs](../../Docs/README.md):
the display model, encoding, refresh and timeline sync in
[Display.md](../../Docs/Display.md), the I2C link in
[I2C.md](../../Docs/I2C.md), and the tasks, mutexes, switches and LEDs in
[Utilities.md](../../Docs/Utilities.md).

Everything else under `User/` is host-only: `Astro/` (the refresh task, parser,
mapper, progress bar and schedule), `Clock/`, `WiFi/`, `Console/`, `Settings/`,
`Sensors/`, `LogService`, the EEPROM driver and `I2cBus`, the aggregate
`Display` with its `BufferedDisplayBoard`s, `DisplaySyncTask` and its
`SyncSchedule`, `LowBrightness` and `MainLoopTask`.
Shared code must not depend on any of these, in particular not on `LogService`.

Every build also counts itself in `BUILD_NUMBER` and regenerates
`BuildInfo.cpp` with that number and the build time
(`../Common/cmake/BuildInfo.cmake`), reported by the console and the address
boot screen ([Development.md](../../Docs/Development.md#build)). There is no
version number or git hash.

## Static Object Graph

The HostController objects are defined at file scope in
`User/Src/AstroWeather.cpp`. `i2c1Bus` is declared first because
objects in one translation unit are constructed in declaration order and the
others hold a reference to it.

| Object | Type | Wraps / owns |
| --- | --- | --- |
| `i2c1Bus` | `Device::I2cBus` | `hi2c1`, with a mutex per transfer |
| `localSct` | `SCT2xxx` | `hspi3`, `SCT_ENABLE`, `SCT_LATCH` |
| `localBoard` | `Display::PcbDisplayBoard` | `localSct`, `htim2`, `DISPLAY_1_EN`..`DISPLAY_5_EN`; refreshed from TIM2's interrupt, which also keeps the refresh timeline the display boards follow and drives the `LED_1` heartbeat |
| `remoteBoard10`..`remoteBoard15` | `Display::BufferedDisplayBoard` | `i2c1Bus` at 7-bit addresses `0x10`..`0x15`, one per forecast block; the one at the host's own address is unused |
| `display` | `Display::Display` | `localBoard` plus the six remote boards; `AstroWeather_Init()` sets the host's address from its straps (`setLocalAddress()`) |
| `settingsEeprom` | `Device::Eeprom24AA04` | `i2c1Bus`, address `0x50` |
| `settingsStore` | `Settings::Store` | `settingsEeprom` and the in-RAM `Values` |
| `activityLed()` | `PulseLed` (`../Common/Src/Debug/PulseLed.cpp`) | `LED_2`: a 250 ms pulse for switch 1, 50 ms for switch 2 (`MainLoopTask`), and 20 ms for every USB CDC transfer in either direction (`CDC_Receive_FS` in the USB interrupt, `CDC_Transmit_FS` after a successful send). The pin is set at once and a static FreeRTOS one-shot timer clears it, so a pulse never blocks and works from an interrupt; overlapping pulses merge. |

The application tasks are singletons reached through `instance()`. The fetch task is private to `User/Src/WiFi/St67HttpFetchTask.cpp`
and is reached through `StartSt67HttpFetchTask()`, `FetchSt67Data()` and
`TriggerSt67ConnectivityCycle()`.

## Tasks

`Task<N>` in `../Common/Inc/Utils/Task.hpp` holds its stack and control block as
members, so application tasks are allocated statically. **`N` is in bytes**,
passed straight to `osThreadNew()` as `stack_size`. `TaskBase` keeps a registry
of up to 16 such tasks, which `stats on` walks to report stack headroom.
Middleware tasks come from the FreeRTOS heap and are not in that registry.

CMSIS-RTOS2 priorities are FreeRTOS priorities (`configMAX_PRIORITIES` is 56):
`osPriorityLow` = 8, `BelowNormal` = 16, `Normal` = 24, `Normal4` = 28,
`AboveNormal` = 32, `Realtime` = 48.

The local display is not refreshed by a task: `Display::PcbDisplayBoard`
runs the multiplexing from TIM2's update interrupt, with SPI3 transfers by
DMA, so its timing depends on interrupt latency only; see
[Display.md](../../Docs/Display.md#refresh-operation).

| Task name | Owner | Priority | Stack (bytes) | Allocation | Does |
| --- | --- | --- | ---: | --- | --- |
| `Modem_Process` | ST67 driver `w61_at_common.c` | 47 | 2048 | heap | AT response and event handling |
| `spi_xfer_engine` | ST67 driver `spi_iface.c` | 46 | 1536 | heap | SPI1 transfers to the module |
| `DisplaySync` | `Display/DisplaySyncTask.cpp` | AboveNormal (32) | 2048 | static | Broadcasts the refresh timeline to the display boards, polls their status and re-sends the content of a board that asks for it; a few milliseconds a minute, above the normal tasks so a due sync is not held up ([TimelineSync.md](../../Docs/TimelineSync.md#syncs-from-the-host)) |
| `defaultTask` | `Core/Src/main.c` | Normal (24) | 512 | heap | Starts USB, then exits (stack freed) |
| `LogService` | `Debug/LogService.cpp` | Normal (24) | 1536 | static | Drains the log queue to USB CDC; `stats` output |
| `ConsoleService` | `Console/ConsoleService.cpp` | Normal (24) | 2816 | static | Assembles and runs console commands |
| `AstroDataRefresh` | `Astro/AstroDataRefreshTask.cpp` | Normal (24) | 3840 | static | Refresh pipeline, 6-hourly schedule, progress bar |
| `MainLoopTask` | `MainLoopTask.cpp` | Normal (24) | 2048 | static | Boot screens on the local board (about 3 s, 944 B of stack at peak), then switch presses: switch 1 requests a refresh, switch 2 toggles low brightness and saves it |
| `CurrentSense` | `Sensors/CurrentSenseTask.cpp` | BelowNormal (16) | 2048 | static | ADC every 100 ms, idle while `adc display` and `adc log` are both off |
| `Clock` | `Clock/ClockTask.cpp` | BelowNormal (16) | 1024 | static | RTC, `HH:MM` on display 3 |
| `St67HttpFetch` | `WiFi/St67HttpFetchTask.cpp` | BelowNormal (16) | 4096 | static | Owns the ST67 session and the HTTPS fetch |
| `Tmr Svc` | FreeRTOS | 2 | 1024 | static | FreeRTOS timer service |
| `IDLE` | FreeRTOS | 0 | 512 | static | Idle |

The two middleware tasks are created on the first fetch by `W6X_Init()`. After
an ordinary refresh the module stays up, so they persist. Their priorities, 46
and 47, and the SPI engine's 1536-byte stack are set in the `USER CODE` block of
`ST67W6X_Network_Driver/Target/w61_driver_config.h` (see
[Development.md](../../Docs/Development.md#cubemx-compliance)). No task
priority affects the display, which is refreshed from TIM2's interrupt.

## Interrupt Priorities

The Cortex-M0+ has four interrupt priority levels, 0 (highest) to 3. It has no
`BASEPRI`, so a FreeRTOS critical section masks every interrupt (`PRIMASK`);
the levels only decide which interrupt runs first and which may preempt
another. The application uses two of them. Set in `HostControllerA.ioc` and
generated into `MX_DMA_Init()`/`MX_GPIO_Init()` (`Core/Src/main.c`), the MSP
functions (`Core/Src/stm32g0xx_hal_msp.c`) and `HAL_PCD_MspInit()`
(`USB_Device/Target/usbd_conf.c`):

| Interrupt | Priority | Source |
| --- | ---: | --- |
| `USB_UCPD1_2` | 1 | USB FS device: the CDC console |
| `TIM2` | 3 | Display refresh, once per pass ([Display.md](../../Docs/Display.md#refresh-operation)) |
| `DMA1_Channel1` | 3 | SPI1 RX, ST67 module |
| `DMA1_Channel2_3` | 3 | SPI1 TX (channel 2), ST67 module; ADC1 (channel 3), current sense |
| `DMA1_Ch4_7_DMA2_Ch1_5_DMAMUX1_OVR` | 3 | SPI3 TX (channel 4), the local display's SCT chain |
| `EXTI4_15` | 3 | `ST67_RDY` (`PA4`), `SWITCH_1` (`PB12`), `SWITCH_2` (`PB13`) |
| `ADC1_COMP` | 3 | ADC1 |
| `TIM1_BRK_UP_TRG_COM` | 3 | HAL time base (`TICK_INT_PRIORITY`) |
| `SysTick`, `PendSV` | 3 | FreeRTOS tick and context switch |

I2C1 has no interrupt: the host is a polled master with timeouts (see
[I2C.md](../../Docs/I2C.md)).

USB is the one interrupt above the rest because the USB peripheral does not
answer a new SETUP packet while the previous endpoint-0 interrupt is still
pending, and the host gives up after three tries; queued behind a refresh
interrupt (up to about 170 us) it missed requests, so the COM port failed to
open or enumerate. See [Console.md](Console.md#usb-device). The refresh
interrupt can in turn be delayed by a USB interrupt (100-290 us in the Debug
build); its shortest pass is 480 us, and a late one is counted as
`late interrupts` in `status`.

## Inter-task Communication

Tasks wake on CMSIS thread flags almost everywhere; there are two message
queues and five mutexes.

### Thread flags

| Receiver | Set by | Meaning |
| --- | --- | --- |
| `MainLoopTask` | `HAL_GPIO_EXTI_Falling_Callback()` via `SwitchInput` | `kEventSwitch1`, `kEventSwitch2` |
| `CurrentSense` | ADC DMA complete / error callbacks | Conversion done or failed |
| `CurrentSense` | `setDisplayEnabled()`, `setLoggingEnabled()` | Re-check whether to sample |
| `ConsoleService` | USB CDC RX and line-state callbacks | Command queued, host connected |
| `LogService` | `log()` from any task; `setStatsEnabled()` | Log queued, stats changed |
| `Clock` | display and time setters | Redraw |
| `AstroDataRefresh` | `requestRefresh()` from any task | Run a refresh |
| `DisplaySync` | `requestBurst()` (`time sync now`) | Start a burst of syncs |
| `St67HttpFetch` | `trigger()`, driver callbacks | Run a batch; DNS, HTTP, scan, connect, disconnect, driver error |
| Refresh caller (`AstroDataRefresh`) | `St67HttpFetch` | `kFetchFlagDone`, `kFetchFlagStage` |

The ST67 `RDY` line (`PA4`) interrupts on its rising edge;
`HAL_GPIO_EXTI_Rising_Callback()` in `User/Src/WiFi/St67SpiReady.cpp` passes it
to the driver's `spi_on_txn_data_ready()`.

### Queues

| Queue | Depth | Producer | Consumer |
| --- | ---: | --- | --- |
| `LogService` log queue | 16 `LogEvent` | any task | `LogService`; when full, the oldest entry is dropped and counted |
| `ConsoleService` command queue | 8 lines | `ConsoleService`, which assembles lines from a 256-byte ring filled by the USB receive callback | `ConsoleService` |

### Mutexes

All are `Utils::Mutex` (priority inheritance, static storage).

| Mutex | Protects |
| --- | --- |
| `I2cBus::mutex_` | One I2C1 transfer at a time: the EEPROM and the five remote boards, driven from the console, refresh and `DisplaySync` tasks. The clock and current-sense tasks only use `submitLocal()` and never touch I2C. Held per transfer, not per operation; the sync broadcast also suspends the scheduler for its transfer, about 1 ms ([I2C.md](../../Docs/I2C.md#devicei2cbus)). |
| `Display::submitMutex_` | The SPI/I2C transfer sequence of `submit()` and `submitLocal()`. Setters are not locked; concurrent writers are last-writer-wins. |
| `PcbDisplayBoard::submitMutex_` | One `submit()` at a time encoding into the back frame set; the refresh interrupt takes no lock and swaps the sets at a frame boundary. |
| `ClockTask::rtcMutex_` | RTC reads and writes, from the clock task, the console and the refresh task's clock sync. |
| `Settings::Store::mutex_` | The Wi-Fi SSID and password and the API host and path, written by the console and copied by the fetch task on every connect or fetch; low brightness, written by the console and by `MainLoopTask` (switch 2); and the whole of `save()`, so a console save and a switch 2 save cannot interleave their page writes. Other settings are written only by the console task and are not locked. |

Short state shared with other tasks, such as the refresh `active_` flag, the
schedule summary and the last Wi-Fi connect result, is guarded with
`taskENTER_CRITICAL()`.

### Refresh and fetch handoff

`AstroDataRefreshTask` owns a 4096-byte `responseBuffer_` and an
`St67FetchRequest`. It calls `FetchSt67Data()`, which runs on the refresh task:
it places the request in the fetch task's single slot, sets its trigger flag and
waits on `kFetchFlagDone | kFetchFlagStage`, waking at least every 250 ms to
redraw the progress bar. The fetch task writes the body straight into the
caller's buffer, advances `request->stage` and sets `kFetchFlagStage` at each
step, and sets `kFetchFlagDone` after publishing the result. The caller gives up
after 180 s (`kClientFetchTimeoutMs`); the fetch task cannot be cancelled and
keeps the slot, so fetches report `Busy` until it finishes. Only the refresh
task touches the display during a fetch. See [WiFi.md](WiFi.md) and
[AstroRefresh.md](AstroRefresh.md).

## Peripherals and Pins

From `Core/Inc/main.h` and `HostControllerA.ioc`.

| Peripheral | Pins | Use |
| --- | --- | --- |
| SPI1, master, 2 Mbit/s | `PA1` SCK, `PA6` MISO, `PA7` MOSI | ST67W611M1, DMA1 channel 1 (RX) and 2 (TX) |
| GPIO | `PA5` `ST67_CS`, `PA0` `ST67_CHIP_EN`, `PA4` `ST67_RDY` (EXTI) | ST67 chip select, enable, ready; used by the driver's `spi_port.c` |
| SPI3, master TX only, 1 Mbit/s | `PB3` SCK, `PB5` MOSI | SCT2xxx daisy chain of the local board |
| GPIO | `PB6` `SCT_LATCH`, `PB7` `SCT_ENABLE` | SCT latch and output enable |
| GPIO | `PD3`, `PA15`, `PD1`, `PD2`, `PD0` = `DISPLAY_1_EN`..`DISPLAY_5_EN` | Multiplex selects |
| TIM2, 16 MHz / 16 = 1 MHz count | none | Display refresh: the interrupt sets each pass's length (four passes per 4 ms slot, 50 Hz frames) |
| I2C1 | `PA9` SCL, `PA10` SDA | 24AA04 EEPROM (`0x50`), remote boards (`0x10`..`0x15`) and the timeline sync broadcast (general call `0x00`) |
| ADC1, 16x oversampling | `PB2` `CURRENT_SENSE` (IN10), plus the internal temperature sensor and VREFINT | Current, temperature and VDDA; DMA1 channel 3 |
| RTC | none (HSE / 32, 750 kHz) | Calendar and backup registers |
| USB FS device, CDC | `PA11` DM, `PA12` DP | Console |
| GPIO EXTI | `PB12` `SWITCH_1`, `PB13` `SWITCH_2` | Switches, falling edge |
| GPIO | `PC13` `LED_1`, `PB9` `LED_2` | Heartbeat from the refresh interrupt; switch presses and USB CDC traffic |
| GPIO | `PB8` `LOW_POWER_EN` | Low-brightness step for every board, set by `display low` and toggled by switch 2 (HostController only; see [Display.md](Display.md#low-brightness)) |
| GPIO inputs | `PB10`, `PB11`, `PB14` = `ADDR_0`..`ADDR_2` | Board address straps, read once at boot by `detectBoardAddress()`, then left analog |
| HSE | `PF0` `OSC_IN`, `PF1` `OSC_OUT` | 24 MHz crystal `Y301`; the PLL makes the 16 MHz system clock |
| SWD | `PA13`, `PA14` | Debug |
| TIM1 | none | HAL time base |

Configured but unused:

- **USART2** (`PA2` `ST67_TX`, `PA3` `ST67_RX`, 921600 baud) is initialised by
  `MX_USART2_UART_Init()`; nothing uses `huart2`. The module is driven over SPI.
- **`ST67_BOOT`** (`PB1`) is an output driven only by the unused
  `St67ProbeTask`, so it stays at its reset level.

### RTC backup registers

Both survive a reset and are lost with power, like the calendar.

| Register | Macro | Contents |
| --- | --- | --- |
| DR0 | `RTC_TIME_SET_BKP_REGISTER` | `0x54494D45` (`TIME`) once the time has been set; checked by `MX_RTC_Init()` and `ClockTask` |
| DR1 | `RTC_ASTRO_REFRESH_BKP_REGISTER` | Time of the last successful astro refresh, seconds since 2000 local; restored into the schedule at boot |

## Memory

FreeRTOS uses `heap_4.c` with `configTOTAL_HEAP_SIZE` of 32000 bytes, against
a measured peak use of about 15.9 KB. The heap
holds `defaultTask` until it exits after starting USB, the two middleware tasks, the CMSIS objects created
without static memory, and the ST67 driver's allocations, including the HTTP
client's per-request buffers; application tasks and their stacks are static. See
[Firmware-RAM-Usage.md](Firmware-RAM-Usage.md) for the breakdown and
`stats on` ([Console.md](Console.md)) for live heap and stack headroom.

`configCHECK_FOR_STACK_OVERFLOW` is 2. `vApplicationStackOverflowHook()` in
`main.c` stores the task name in `g_stackOverflowTaskName`, disables interrupts
and spins. The board freezes with the display stopped and the console silent;
read `g_stackOverflowTaskName` with a debugger to find the task. There is no
watchdog, so it stays that way until reset.

## Unit Tests

The native suites in `tests/` build with the `NativeTests` preset
(`BUILD_NATIVE_TESTS=ON`) and run under CTest; see
[Testing.md](../../Docs/Testing.md). Decisions are kept out of the tasks: parsing,
mapping and timing logic lives in small hardware-free units (for example
`AstroDisplayMapper`, `AstroProgressBar`, `HttpResponseParser`,
`St67ConnectDiagnosis`), and the tasks only do the I/O around them. Code that
still needs the HAL, the RTOS or the log links the stand-ins in
`../Common/tests/stubs` and `tests/fakes`. The suites for the shared code are
a separate project in `../Common`.

The suites, what each covers, and what is still untested (console commands,
`Settings::Store` and the EEPROM driver, `BufferedDisplayBoard`, `LowBrightness`,
`resolveApiTarget()`, and the bench-only code) are listed in [Testing.md](Testing.md#coverage-by-module).

## Unused and Dead Code

Present in the tree, and compiled unless noted, but not used by the running
firmware:

- **`St67ProbeTask`** (`User/Src/WiFi/St67ProbeTask.cpp`): the raw-SPI probe from
  bring-up. `StartSt67ProbeTask()` is never called, so the linker discards it.
- **`TriggerSt67ConnectivityCycle()`**: starts the WiFi stress batch
  ([WiFi.md](WiFi.md#stress-batch)). No callers since switch 2 was given to low
  brightness; kept for bench use.
- **`TriggerSt67SmokeTest()`**: an old alias of `TriggerSt67ConnectivityCycle()`
  with no callers.
- **The driver's HTTP, MQTT and BLE services** (`Middlewares/ST/ST67W6X_Network_Driver/Core/w6x_http.c`,
  `w6x_mqtt.c`, `w6x_ble.c`): compiled by the CubeMX CMake list, with no
  callers; discarded at link time. The firmware uses its own
  `HttpClient::get()` in `User/Src/WiFi/HttpClient.cpp`; see
  [WiFi.md](WiFi.md#why-a-user-owned-http-client).
- **`Appli/App/main_app.h`, `User/Inc/logshell_ctrl.h`**: empty headers.
- **`St67Runtime::httpPayload`**: a 4 KB buffer inside the fetch task object,
  written only by the stress batches (no client request); every refresh writes to
  the refresh task's own buffer instead.
- **Unused `app_config.h` macros**: `APP_ST67_SCAN_TIMEOUT_MS`,
  `APP_ST67_SCAN_MAX_RESULTS`, `APP_ST67_HTTP_TOTAL_TIMEOUT_MS`,
  `APP_ST67_HTTP_MAX_HEADER_BYTES` (`HttpResponseParser.hpp` has its own
  2048-byte header limit, `kHeaderCapacity`), and `APP_ST67_WIFI_SSID` / `APP_ST67_WIFI_PASSWORD`, which the
  credentials template still defines although the credentials now come from the
  EEPROM (`wifi set`).

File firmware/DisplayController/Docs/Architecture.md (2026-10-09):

# DisplayController Architecture

How the display board firmware is put together. The display itself (content
types, PCB mapping, multiplexing) is shared with the host and described in
[Display.md](../../Docs/Display.md), the I2C link to the host in
[I2C.md](../../Docs/I2C.md); pins and peripherals are in the
[README](../README.md#hardware).

The first display board runs this firmware on the host's bus at `0x11`.

## Boot

`main()` runs the CubeMX sequence: `HAL_Init()`, `SystemClock_Config()` (HSI,
16 MHz), `MX_GPIO_Init()`, `MX_DMA_Init()`, `MX_SPI1_Init()`, `MX_I2C1_Init()`,
`MX_TIM6_Init()`, `osKernelInitialize()`, `defaultTask`, then
`DisplayController_Init()` from the `RTOS_THREADS` user section, then
`osKernelStart()`.

`DisplayController_Init()` (`User/Src/DisplayController.cpp`), before the
scheduler starts:

1. Creates the `activityLed()` timer for `LED_2`.
2. Shows the first slot-test frame (`Display::slotTestState(0)`) and starts the refresh
   (`PcbDisplayBoard::start()`: enables the SCT outputs and starts TIM6, whose
   interrupt then multiplexes the board with SPI1 DMA transfers, no task
   involved, keeps the board's refresh timeline and drives the `LED_1`
   heartbeat; see
   [Display.md](../../Docs/Display.md#refresh-operation)).
   The test frame is prepared first, so the first frames latched are the
   test, not whatever the drivers held at reset.
3. Starts the `DisplayApp` task and routes the switches to it
   (`Utils::SwitchInput`).
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

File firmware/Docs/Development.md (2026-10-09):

# Development

How to build, test, flash and talk to the AstroWeather firmware, and how to
keep application code out of the CubeMX-generated files. It covers every
firmware project:

| Project | Target | Artifact |
| --- | --- | --- |
| [HostControllerA](../HostControllerA/README.md) | STM32G0B1, the Wi-Fi host | `build/Debug/HostControllerA.elf` |
| [DisplayController](../DisplayController/README.md) | STM32G070, a remote display board | `build/Debug/DisplayController.elf` |
| [Common](../Common/README.md) | Code compiled into both; native tests only | none |
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

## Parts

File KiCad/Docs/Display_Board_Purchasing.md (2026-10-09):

# Display Board Purchasing

## Goal

Buy parts for display boards: the `AstroWeather` PCB populated only with the MCU, power supply and displays. These boards receive data over I2C from the host controller through `J102`/`J104`. They do not need USB-C, current sensing, the ST67 Wi-Fi module or the light sensor.

Prices and stock were first checked on 2026-09-22 and last on 2026-09-24; `L601` on 2026-09-28. Recheck them before ordering.

## Sources and caveats

- The BOM comes from `KiCad/AstroWeather.kicad_sch` (KiCad 9 `kicad-cli` BOM and netlist export). The per-board BOM is in [`Display_Board_BOM.csv`](Display_Board_BOM.csv).
- `KiCad/Controller.kicad_sch` is not part of the sheet hierarchy and was ignored.
- Mouser blocks automated fetches; it was checked on 2026-09-24 through a browser session on `mouser.pl`.
- TME prices are net. Farnell prices include 23% VAT. Mouser prices are compared as net.
- Quantities below assume 5 boards.

## What is on a display board

A display board gets `VBUS`, `GND`, I2C, `LED_BRIGHTNESS` and `LOW_POWER_ENABLE` from the 10-pin daisy-chain connectors `J102`/`J104`.

| Fitted | Not fitted |
|---|---|
| MCU `U302` + decoupling, SWD `J103`, `J102`/`J104` | ST67 sheet (`U201`, `C201`-`C204`, `R201`) |
| Power Supply sheet (`U601`, `U602`, `L601`, `C601`-`C608`, `R601`, `R602`) | Light Sensor sheet (`Q701`, `R701`-`R705`) |
| Display sheet, including the `MCP6006` + `BC847` current-set stages | USB-C `J106`, `R102`/`R103`, `D101`/`D102`, `J105` |
| | `U101` INA180 + `R101` shunt, `R304`/`C306`, `R305`/`C307` |
| | Optional: `Y301` crystal (the display firmware uses HSI; the host needs it, 24 MHz), LEDs, buttons, `U301` EEPROM, `R301`/`R302` (DNP) |

The `MCP6006` + `BC847` stages (`U503`/`U507`/`U511`/`U515`, `Q506`-`Q509`) are required. They load the SCT drivers' `REXT` pins from `LED_BRIGHTNESS`. Without them the displays stay dark.

## Decisions

| Item | Decision |
|---|---|
| `L601` | Ferrocore `DE0704-33` from TME (33 µH, IDC 0.96 A max, DCR 0.170 Ω max, shielded, 7.3×7.3×4.5 mm), chosen 2026-09-28. Same inductance and about the same current as the Bourns `SRR6838A-330M` (Isat 1.02 A) proven on the prototype, and it removes the Farnell order. See [L601: DE0704-33](#l601-de0704-33) |
| `D501` | Not fitted, pads shorted |
| `U601` | `TPS54202DDCR` replaces `TPS54302` (out of stock at TME and withdrawn at Farnell). Pin-compatible, and `EN` floats to enable: confirmed in `Hardware_Review.md` M-2. Rechecked 2026-09-24: TPS54302DDCR still 0 at TME; at Farnell the DDCR is not listed and the DDCT is withdrawn |
| `Q501`-`Q505` | `SI2333CDS-T1-E3` replaces `Si2333DDS` (TME has 1, Farnell lead time 56 weeks) |
| MCU | `STM32G070CBT6`, no USB; see [MCU](#mcu-stm32g070cbt6). The STM32G0B1CET6 ships from 2027-01-18 at Farnell, has a 14-week lead time at TME and a 52-week factory lead time at Mouser (checked 2026-09-24) |
| `R504`/`R507`/`R510`/`R513` | 4k7. With it the host board measured about 3.3 mA per segment in room light, already below the SCT2024's 5–30 mA range; 10k would halve that (`Hardware_Review.md`) |

## MCU: STM32G070CBT6

Display boards use the **STM32G070CBT6** (128 KB flash, 36 KB RAM, LQFP48),
chosen on 2026-09-24. The STM32G0B1CET6 ships from 2027-01-18 at Farnell, has a
14-week lead time at TME and a 52-week factory lead time at Mouser.

- **Same footprint and pins.** Every pin the display board uses is in the same
  place on all STM32G0 LQFP48 parts (checked in the CubeMX pin database): the SCT
  SPI and control lines, `DISPLAY_1_EN`..`DISPLAY_5_EN`, I2C1 on PA9/PA10,
  `LOW_POWER_EN`, the address straps, the switches, the LEDs and SWD. No wiring
  change. `R304`, `R305`, `C306` and `C307` stay unfitted; pins 30/31 are PC6/PC7
  as on the G0B1.
- **No USB.** The G070 has no USB peripheral. The console runs over USART2
  instead; see [Console over UART](#console-over-uart).
- **Firmware consequences** (the DisplayController firmware is still a stub):
  - It needs its own CubeMX project for the G070 (`.ioc`, startup file, linker
    script); it can no longer be a variant of the G0B1 build. The STM32G0 HAL is
    the same.
  - The SCT chain moves from SPI3 to SPI1, on the same PB3/PB5 pins.
  - The image must fit 36 KB of RAM: no USB, no WiFi, a small RTOS heap or none.
    The display code (`PcbDisplayBoard`, `DisplayCodec`, the I2C protocol) is
    portable.
- **Alternatives considered** (all LQFP48, pin-compatible; stock on 2026-09-24):
  - USB-capable: only the STM32G0B1CET6N was in stock (Farnell, Mouser). It needs
    `VDDIO2` (pin 31) wired to `+3.3V` and pin 30 grounded, because those pins
    are `VDDIO2`/`VSS` on the N package; on this board through `R304`'s MCU-side
    pad, 100 nF at `C306` and a 0R at `C307`, never fitting `R304`. The G0B0 and
    G0C1 were out of stock everywhere.
  - Without USB: STM32G071CBT6 (adds UCPD, which is Type-C power negotiation,
    not USB data), STM32G071C8T6 (64 KB), STM32G051C8T6 (18 KB RAM),
    STM32G030/031 (8 KB RAM). The G070CBT6 is the cheapest with 36 KB of RAM.
    Mouser sells it as `STM32G070CBT6TR` cut tape (25,651 in stock, 10+ 6.91),
    but its delivery charge rules it out for this order.

## L601: DE0704-33

- **Footprint:** the DE0704 recommended pattern is two 2.2 × 1.6 mm pads with a
  4.8 mm gap, so its terminals sit 2.4–4.0 mm from the centre. The
  `L_Bourns_SRP7028A_7.3x6.6mm` pads (2.95 × 3.5 mm at ±2.725 mm) cover
  1.25–4.2 mm along the axis and ±1.75 mm across it, so the terminals land fully
  on them.
- **Clearance:** the 7.3 mm square body is 0.5 mm wider than the SRR6838A. The
  nearest part is `C602`, whose pad edge is about 3.93 mm from the `L601` centre,
  against a body half-width of 3.65 mm: 0.27 mm nominal, about 0.07 mm at the
  +0.2 mm body tolerance. `C604`/`C605` and `TP601` have more room.
- **Current:** the datasheet gives only IDC (max), with no definition (ΔL or ΔT).
  0.96 A is close to the SRR6838A's 1.02 A Isat, so it does not address
  `Hardware_Review.md` M-1 (Isat ≥ 2.5 A); nothing in stock at TME in this size
  does.
- **DCR:** 0.170 Ω costs 1.7 mW at 0.1 A and 109 mW (3.7% of output power) at the
  host's 0.8 A worst case. It is inside the feedback loop, so VDD does not move.
- **Ripple:** ≈ 60 mA p-p gives about 1 mV p-p on VDD with ≈ 20 µF effective at
  `C604`/`C605`. The SCT2024 datasheet sets no ripple limit (line regulation
  ±1 %/V max, load regulation ±0.5 %/V max), and each driver has a 10 Ω + 5.7 µF
  filter, so ripple does not favour any inductance between 10 and 33 µH.

## Console over UART

Without USB, the development console (`tools/astro_console.py`, the log and
the commands) runs over USART2 through the ST-LINK/V2-1 of the NUCLEO-L152RE used
as the programmer, which appears as COM3 ("STLink Virtual COM Port").

| Display board | Signal | Wire to NUCLEO-L152RE |
|---|---|---|
| `U201` pad 23 (net `ST67_TX`, MCU pin 13) | PA2, USART2 TX | **CN3 RX** |
| `U201` pad 22 (net `ST67_RX`, MCU pin 14) | PA3, USART2 RX | **CN3 TX** |
| `J103` pin 3 | GND | already common through the SWD cable (CN4 pin 3) |

- `U201` (the ST67 module) is not fitted on display boards, so its pads are free;
  MCU pins 13/14 carry the same nets. Both sides are 3.3 V.
- CN3 is the ST-LINK's own USART (UM1724 section 6.8); its labels are from the
  ST-LINK's side.
- On the Nucleo, solder bridges SB13/SB14 (closed by default) also join CN3 to the
  on-board STM32L152's PA2/PA3. Keep the L152 from driving them: erase it (CN2
  jumpers on, erase with STM32CubeProgrammer, jumpers off again), or open
  SB13/SB14.
- For external programming the CN2 jumpers stay off, and SB12 must be open if
  CN4 pin 5 (NRST) is used (UM1724).
- Firmware: USART2 at 115200 8N1 on PA2/PA3 (AF1); then
  `python tools/astro_console.py --port COM3 status`.
- Next PCB revision: `J103` pin 6 is unconnected. Route USART2 TX there (or use
  an 8-pin connector with TX and RX) so no wires are needed.

## Shopping lists

Final list, chosen on cost, from the recheck of Farnell, TME and Mouser on
2026-09-24 and of `L601` on 2026-09-28. One order: everything from TME.

### TME

| Part | Qty | Stock | Net price per piece | Net total |
|---|---|---|---|---|
| STMicroelectronics STM32G070CBT6 | 10 | 250 | 7.80 (10+) | 78.00 |
| FORYARD FYM-7571AUHR-11 | 15 | 3,615 | 5.50 (10+) | 82.50 |
| WENRUN LFD028BUE-103A | 20 | 1,951 | 3.59 (5+) | 71.80 |
| STARCHIPS SCT2024CSSG | 15 | 14,515 | 2.455 (5+) | 36.83 |
| STARCHIPS SCT2167CSSG | 5 | 1,211 | 2.966 (3+) | 14.83 |
| TI TPS54202DDCR | 5 | 98 | 5.361 (1+) | 26.81 |
| Microchip MCP1825S-3302E/DB | 5 | 2,305 | 2.466 (1+) | 12.33 |
| Vishay SI2333CDS-T1-E3 | 25 | 383 | 1.818 (25+) | 45.45 |
| Nexperia BC847B,215 | 20 | 277,400 | 0.2214 (10+) | 4.43 |
| Samsung CL21A475KAQNNNE (4u7 0805 25 V X5R) | 30 | 333 | 0.3570 (10+) | 10.71 |
| Murata GRM21BR6YA106ME43L (10u 0805 35 V X5R ±20%, `C602`) | 10 | 88 | 0.8439 (10+) | 8.44 |
| CONNFLY DS1024-1*10R0 (TME `ZL263-10SG`, 1×10 right-angle socket, `J102`) | 5 | 1,469 | 0.951 (5+) | 4.76 |
| CONNFLY DS1022-1*20RUF1-1 (TME `ZL211-20KG-S`, 1×20 right-angle header, `J104`) | 5 | 1,919 | 0.714 (5+) | 3.57 |
| JST B6B-PH-K-S (LF)(SN) (`J103`, optional SWD) | 5 | 10,822 | 0.750 (1+) | 3.75 |
| Microchip MCP6006T-E/OT (`U503`/`U507`/`U511`/`U515`) | 20 | 949 | 0.718 (1+) | 14.36 |
| Samsung CL10B104KB8NNNC (100n 0603 50 V X7R ±10%) | 200 | 240,984 | 0.0876 (100+) | 17.52 |
| Murata GRM31CR61E226KE15L (22u 1206 25 V X5R ±10%, `C604`/`C605`) | 10 | 58,634 | 1.330 (10+) | 13.30 |
| Ferrocore DE0704-33 (33 µH, `L601`) | 5 | 340 | 1.087 (5+) | 5.44 |
| | | | **Subtotal** | **454.83 zł net (≈ 559.4 zł incl. VAT)**, plus 13.90 zł net delivery |

- STM32G070CBT6: 10 rather than 6, since 6 at the 1+ price (10.85) cost 65.10 zł
  and 10 at the 10+ price cost 78.00 zł. TME price breaks: 1+ 10.85, 10+ 7.80,
  25+ 6.63.

**Total: about 577 zł incl. VAT including delivery (468.73 zł net).** Moving `L601` from Farnell (57.23 zł incl. VAT with delivery) saves about 50 zł.

### Why not Mouser

Mouser (mouser.pl, checked 2026-09-24) carries the MCU (`STM32G070CBT6TR` cut
tape, 25,651 in stock, 10+ 6.91; tray 3,488, 10+ 7.96), the SRR6838A-330M (841,
1+ 4.35) and most catalogue parts, but not the SCT drivers or either display, so
TME is needed in any case. Mouser delivers free above 300 zł; below that FedEx
costs 105 zł (DDP: Mouser pays duty and customs), which outweighs its lower MCU
and inductor prices. It was dearer than TME on the shared parts (MCP1825 2.61,
MCP6006 0.80, SI2333 2.12 at 10+, B6B 1.06), except CL21A475 (0.33). Its listed
prices had no VAT added in the basket and are compared here as net.

### TME notes

- Order rules: SCT2024CSSG is sold in multiples of 5. SCT2167CSSG has a minimum of 3. ZL263-10SG and ZL211-20KG-S have a minimum of 5.
- More price breaks (net):
  - FYM-7571AUHR-11: 1+ 6.52, 3+ 5.99, 20+ 5.01
  - LFD028BUE-103A: 1+ 4.06, 25+ 3.07, 100+ 2.43
  - SCT2024CSSG: 25+ 2.154, 100+ 1.935
  - SCT2167CSSG: 10+ 2.651
  - CL21A475KAQNNNE: 100+ 0.2330
  - GRM21BR6YA106ME43L: 1+ 1.8101, 50+ 0.4803. Ten pieces cost less than five at the 1+ price.
  - ZL263-10SG: 20+ 0.755, 100+ 0.573
  - ZL211-20KG-S: 10+ 0.565, 100+ 0.425
  - B6B-PH-K-S (LF)(SN): 10+ 0.661, 25+ 0.608
  - MCP6006T-E/OT: 25+ 0.654 (25 pieces cost 16.35, more than 20 at the 1+ price)
  - CL10B104KB8NNNC: 10+ 0.1325, 1000+ 0.0549, 4000+ 0.0445
  - GRM31CR61E226KE15L: 1+ 2.394
  - DE0704-33: 25+ 0.860, 100+ 0.760, 500+ 0.680. Minimum 5.
- Lead times when stock runs out: SCT2024CSSG 9 weeks, SCT2167CSSG 14 weeks. TPS54202DDCR: 98 in stock on 2026-09-24 (147 on 2026-09-22), 6,000 expected on 2026-11-10.
- Standard delivery costs 13.90 zł net (17.10 zł incl. VAT). DPD, GLS and InPost cost 15.90 zł net.
- Stock changes seen on 2026-09-24: CL21A475KAQNNNE 1,614 → 333 (30 needed); MCP1825S-3302E/DB 702 → 2,305.
- Alternative for `Q501`-`Q505`: `SI2333CDS-T1-GE3`, 304 in stock, 10+ 2.495 net.
- CL10B104KB8NNNC: 20 are needed for 5 boards (`C101`, `C301`, `C305`, `C603`); 200 are bought as stock for the host board and later builds. 50 V also covers `C603` on VBUS.
- GRM31CR61E226KE15L: a 25 V part rather than 10 V, because an MLCC loses capacitance under DC bias and these are the buck's output capacitors at 3.7 V; the more voltage headroom, the more of the 22 µF is left (`Hardware_Review.md` M-1).
- ZL263-10SG: 1×10, 2.54 mm, 90°, THT, gold-plated contacts, 3 A, height 8.4 mm, lead length 3.2 mm.
- ZL211-20KG-S is a 1×20 header, cut in two for two boards, so 3 are enough for 5 boards. The 5-piece minimum leaves spares.
- `C602`: the previously used `GRM21BR6YA106KE43L` (±10%) has 0 in stock at TME. The ±20% `...ME43L` is the same part otherwise; tolerance does not matter for VBUS bulk decoupling. Alternative: TDK `C2012X5R1V106K125AC` (35 V X5R ±10%, 114 in stock, 1+ 1.578, 10+ 1.100).
- DE0704-33: 340 in stock on 2026-09-28, 4,000 more expected on 2027-01-12.
- The connectors and `C602` were checked on 2026-09-23, the MCP6006, CL10B104KB8NNNC and GRM31CR61E226KE15L on 2026-09-24. MCP6006T-E/OT has 15,000 more in external stock (2026-11-02).

## Not buying

Dropped from the order: 0805 capacitors 1u ×25, 10u ×5 (`C503`), 10p ×5 (`C504`), 100n ×5 (`C601`) and 47p ×5 (`C608`), and all 0805 resistors: 10R ×20, 1k ×25, 4k7 ×20, 100k ×5 and 19k2 ×5.

## Open items

None. Recheck stock and prices on both carts just before ordering.

Closed:

- **`L601` footprint:** the SRR6838A-330M fits the `L_Bourns_SRP7028A_7.3x6.6mm` pads, tightly, and works on the prototype. The DE0704-33 fits them too; see [L601: DE0704-33](#l601-de0704-33). `SRP7028A-330M` (Farnell 3373372) would match the footprint exactly if ever needed.
- **TPS54202 swap:** confirmed pin-compatible, with `EN` floating to enable; see the `U601` decision.
- **Faint glow on switched-off digits:** none visible on the prototype host board, whose `Q501`-`Q505` gates are driven straight from 3.3 V GPIOs against a 3.7 V source. The margin is still thin, so a gate driver is listed for the next PCB revision in `Hardware_Review.md` H-3.

## Parts that were rejected

- **`STM32G0B1CET6N`**: the only USB-capable part in stock on 2026-09-24, but it needs `VDDIO2` wired on every board; see [MCU](#mcu-stm32g070cbt6). ST's alternative pinout, not a part without USB PD. It adds a `VDDIO2` pin and a second UCPD port. Farnell's "no UCPD/FDCAN/CEC/LPUART" listing is wrong. Compared with the CET6 (CubeMX `STM32G0B1C(B-C-E)Tx.xml` vs `...TxN.xml`), only two pins differ:

  | LQFP48 pin | CET6 | CET6N | On our PCB |
  |---|---|---|---|
  | 30 | PC6 | `VSS` | `R305`/`C307`, not fitted on display boards |
  | 31 | PC7 | `VDDIO2` | `R304` to `VBUS_IN` (5 V) and `C306`, not fitted on display boards |

  Pin 30 is harmless. Pin 31 would float, and `VDDIO2` supplies `VDDUSB` and some I/Os, which are cut off while it is unpowered. Which I/Os those are was not checked. Using the CET6N needs a wire from pin 31 (the MCU-side pad of `R304`) to 3.3 V on every board, with 100 nF at `C306` and a 0R at `C307`, and `R304` must never be fitted. With `VDDIO2` tied to `VDD` it behaves as the CET6, and its USB works (VDDUSB comes from VDDIO2). Kept as the option if USB on the display boards is ever needed.
- **`STM32G0B1CET6`:** 0 in stock everywhere on 2026-09-24 (Farnell ships from 2027-01-18, Mouser 52-week factory lead time). At TME on 2026-09-22: 0 in stock, 13-week lead time (1+ 18.25 / 20.29 net, 10+ 14.24 / 15.68 net).
- **Bourns `SRR6838A-330M`** (Farnell 4655301, 5.45 incl. VAT, 29.99 zł delivery below 200 zł): proven on the prototype, and the fallback if the DE0704-33 does not work out. Not stocked at TME. Farnell notice: since 2026-07-01 some EU shipping methods need a valid EU VAT number on the account.
- **`SRR6838A-100M`** (10 µH, Isat 1.72 A, DCR 35 mΩ, Farnell 4655293): the TPS54202 datasheet value, with more saturation margin but ≈ 190 mA p-p ripple.
- **Ferrocore `DE0704-22`** (22 µH, IDC 1.23 A, 0.110 Ω, 1.125 net at 5+): the better part electrically, but 0 in TME stock on 2026-09-28 (6,430 expected 2026-10-14).
- **Ferrocore `DE0703-22`** (22 µH, IDC 1.07 A, 0.190 Ω, 3.2 mm high, 321 in stock, 1.125 net at 5+): only about 11% more current than the DE0704-33, with higher DCR.
- **At TME on 2026-09-28, no small quantities:** Bourns `SRP7028A-100M`/`-220M`/`SRP7028AA-150M` and `SRN6045TA-100M`/`-220M`/`-330M` (1,000-piece reels or 0 stock, business customers only); Panasonic `ETQP5M330YFM` (0 stock, minimum 1,000); Ferrocore `HPI0640-100` and `MPLF0630-330` (withdrawn).
- **SRR6038-330Y** at TME: sold only as a 1,000-piece reel, business customers only.
- **SRP7028A-330M** at TME: discontinued.
- Farnell does not list the FYM-7571, LFD028BUE or SCT2024 parts.

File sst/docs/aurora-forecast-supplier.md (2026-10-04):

# Aurora Forecast Supplier Evaluation

## Purpose

This document records the search for a source of aurora (northern lights)
forecasts for AstroWeather's configured locations (Wrocław by default), and
the feasibility assessment of the candidates found. It is based on live fetches
performed on **2026-09-28**.

The product asked for:

- forecasts for a given geographical location;
- forecasts by hour, so they can be drawn on the matrix display;
- an aurora probability expressible on the display's four-level scale;
- a 7-night horizon, matching the weather rows.

## Current Status

The aurora row is implemented on the server as designed below, with these
decisions:

- **Thresholds**: each configuration carries `aurora.kpMain`, the naked-eye
  Kp (Wrocław 7, Kraków 7.5); levels 1 and 3 are one Kp below and above. The
  procedure for computing it is in `configurations.ts`.
- **Nowcast from the first release**: raise-only with the placeholder
  thresholds (5 / 15 / 40 %) and blinking down, rather than logging only; the
  `aurora-calibration` log runs alongside, and the thresholds are to be tuned
  after the first storms.
- **Protocol 3**: blink down (`a`, `b`, `c`) is supported and used for the
  nowcast; blink up (`A`, `B`) and the GFZ ensemble blink up are not
  implemented. The device accepts protocol 3 only.
- **Refresh interval**: the `refreshIntervalMinutes` header record, `60` on a
  storm night.
- **Progress bar**: on the local board the parsed aurora row overwrites the
  progress bar at once, with no success hold; after a failed refresh tonight's
  row stays blank until the next success.

The HostController firmware accepts protocol 3 (parser, mapper and the
hourly schedule) and runs against the `int` stage.

## Executive Assessment

**No public source publishes a per-location, hourly, 7-night aurora
forecast, and none can**: geomagnetic activity is only forecastable from
measured solar-wind conditions (up to ~3 days ahead, driven by CME arrival and
high-speed-stream predictions); beyond that the only outlook is a 27-day
solar-rotation recurrence table with one daily value. Every aurora site or app
checked (AuroraMe, SpaceWeatherLive, Aurora Map, PolarForecast, …) is a
re-packaging of the same two upstream feeds plus a latitude rule.

The recommendation is therefore to build the aurora row from the **upstream
feeds directly**, which are free, keyless, machine-readable, and openly
licensed, and to apply the location rule ourselves:

| Nights | Source | Resolution | Updated | Format / licence |
| --- | --- | --- | --- | --- |
| 1–3 | GFZ Hp60 ensemble forecast (PAGER/SWIFT) | **hourly**, 72 h ahead, with probabilities per Kp band | hourly | JSON, CC BY 4.0 |
| 1–3 (fallback) | NOAA SWPC 3-day Kp forecast | 3-hour bins | ~twice daily | JSON, US public domain |
| 4–7 | NOAA SWPC 27-day outlook | **one "largest Kp" per day** | weekly (Mondays) | text, US public domain |
| current hour, storm nights | NOAA OVATION 30-minute nowcast | 1°×1° grid, per-location probability % | every 5 min | JSON, US public domain |

The per-location step is a geomagnetic-latitude threshold (see
[Deriving a four-level scale](#deriving-a-four-level-scale)); for Wrocław an
aurora is only plausible at Kp ≥ 6 and only a real display at Kp ≥ 8, i.e.
during G2+ and G4+ storms, a few nights per year. Most of the time the row
will be dark, which is the correct answer.

## Candidates Rejected

| Candidate | Finding |
| --- | --- |
| `api.auroras.live` (`/v1/?type=all&lat=…&long=…`) | Returns `HTTP 500` with an empty body; the service appears dead. |
| `auroraforecast.me/wrocaw` (AuroraMe) | Scrape-only page. Its own Kp comes from NOAA; hourly cloud from Open-Meteo. Shows 6 h and 27-day views, 72 h only in a paid app. No API. Nothing we could not assemble ourselves from the same feeds. |
| `aurora-service.eu` (Aurora Service Europe) | Forecast page says it is "down for maintenance". |
| `spaceweatherlive.com` | Republishes the NOAA 3-day (3-hourly) and 27-day (daily) Kp forecasts; "All rights reserved", no API. |
| NOAA "Aurora for Tonight and Tomorrow Night" (experimental) | Two-night horizon, North America only, published as PNG maps, not archived, no data file. |
| GFZ "Auroral Activity Forecast" | Kp-driven neural-network oval maps (Feng et al. 2025); image product, no data file found. |
| Met Office space weather | 4-day text summary only; data feeds need a "specialist space weather account". |
| Meteomatics space-weather API | Commercial. |
| Open-Meteo | No Kp/aurora parameter (open-meteo/open-meteo#328 remains a feature request). |

## Live Fetch Tests

All fetches were plain `curl` from a residential connection with a browser
`User-Agent`; no keys, cookies, or challenges were involved.

### GFZ Hp60 ensemble forecast (nights 1–3, primary)

```text
GET https://spaceweather.gfz.de/fileadmin/SW-Monitor/hp60_product_file_FORECAST_HP60_SWIFT_DRIVEN_LAST.json
```

- HTTP `200`, `application/json; charset=utf-8`, 18 KB, ~60 ms.
- `Last-Modified: Mon, 28 Sep 2026 19:05:18 GMT`; the page states the model
  runs every hour. No `Cache-Control` header.
- Shape: column-oriented, each column an object keyed by row index as a
  string. 73 rows at **1-hour spacing**, `28-09-2026 18:00` → `01-10-2026 18:00`
  UTC (72 h horizon).
- Columns: `Time (UTC)` (`dd-mm-yyyy HH:MM`), `minimum`, `0.25-quantile`,
  `median`, `0.75-quantile`, `maximum`, `prob 4-5`, `prob 5-6`, `prob 6-7`,
  `prob 7-8`, `prob >= 8`, and the individual ensemble members `hp60_0` …
  `hp60_N` (12–20 members, per the README).
- Hp60 is GFZ's hourly-resolution analogue of Kp on the same 0–9 scale (and,
  unlike Kp, is open-ended above 9); Kp-based thresholds apply directly.
- A sibling Kp product exists at
  `…/fileadmin/Kp-Forecast/CSV/kp_product_file_FORECAST_PAGER_SWIFT_LAST.json`
  (25 rows at 3-hour spacing, same columns with `kp_i` members) and Hp30 at
  `…/fileadmin/SW-Monitor/hp30_product_file_FORECAST_HP30_SWIFT_DRIVEN_LAST.json`.
- README: `https://spaceweather.gfz.de/fileadmin/SW-Monitor/README.rst`.
- Licence: GFZ states all index data and graphs are under **CC BY 4.0**, and
  asks that Matzka et al. (2021), doi:10.5880/Kp.0001 and
  doi:10.1029/2020SW002641, be cited. The forecast page adds an "as-is, no
  warranty" disclaimer. Produced within the EU PAGER (Horizon 2020) project.

### NOAA SWPC 3-day Kp forecast (nights 1–3, fallback)

```text
GET https://services.swpc.noaa.gov/products/noaa-planetary-k-index-forecast.json
```

- HTTP `200`, `application/json`, 7 KB, ~70 ms, `Access-Control-Allow-Origin: *`,
  `Cache-Control: max-age=60`.
- Array of `{time_tag, kp, observed, noaa_scale}` rows at **3-hour spacing**:
  ~7 days of `"observed"` history, two `"estimated"` bins, then `"predicted"`
  bins to the end of day 3 (`2026-10-01T00:00:00` when fetched).
- Same numbers as the human-readable
  `https://services.swpc.noaa.gov/text/3-day-forecast.txt` (issued 12:30 UTC)
  and `…/text/3-day-geomag-forecast.txt` (issued 22:05 UTC), which also carry
  daily probabilities of "Active / Minor / Moderate / Strong-Extreme storm".
- Licence: US federal government work, public domain; no key, no documented
  rate limit beyond the 60 s cache hint.

### NOAA SWPC 27-day outlook (nights 4–7)

```text
GET https://services.swpc.noaa.gov/text/27-day-outlook.txt
```

- HTTP `200`, `text/plain`, 1.6 KB. `:Issued: 2026 Sep 28 0221 UTC` — issued
  weekly on Mondays.
- Fixed-width rows `YYYY Mon DD  F10.7  Ap  LargestKp`, 27 days from the issue
  date; for example the fetched table forecast `Largest Kp 4` for Oct 4–6 and
  `5` for Oct 22. This is a **daily maximum**, so every hour of a night gets
  the same level.
- A JSON alternative, `https://services.swpc.noaa.gov/json/45-day-forecast.json`,
  carries daily `ap` and `f107` but not Kp; Ap→Kp needs a lookup table, so the
  text product is simpler.

### NOAA OVATION 30-minute nowcast (current hour, storm nights)

```text
GET https://services.swpc.noaa.gov/json/ovation_aurora_latest.json
```

- HTTP `200`, 920 KB, refreshed every 5 minutes; `Observation Time`,
  `Forecast Time` (~30–90 min ahead) and 65 160 `[lon, lat, probability%]`
  triples on a 1° grid (longitude 0–359, so Wrocław is `[17, 51, …]`; it read
  `0` at 20:03 UTC on the test day).
- This is the only feed that is per-location out of the box, but it is a
  nowcast, not a forecast: it refines one cell of the row. Note that its
  `Forecast Time` is 30–90 minutes after `Observation Time` (the solar wind's
  travel time from L1), so a fetch describes the *coming* hour, not the one
  it was fetched in. See [Fetch Cadence](#fetch-cadence).

## Deriving a Four-Level Scale

Kp/Hp60 is global; whether the aurora reaches a place depends on that place's
**magnetic latitude**. NOAA's viewing guidance gives the rule: at Kp 0 the
equatorward edge of the auroral oval sits at ~66° magnetic latitude and moves
~2° equatorward per Kp step (Kp 9 → ~48°), and the aurora "can often be
observed hundreds of kilometers equatorward" of that edge, low on the poleward
horizon. Magnetic longitude does not enter: two places on the same magnetic
latitude get the same thresholds, and longitude only matters through local
time (whether it is dark, and how close the hour is to magnetic midnight,
where the oval reaches furthest south).

### Which magnetic latitude

Two conventions give different numbers for the same place, and the choice is
worth about one Kp step:

- **Centred-dipole latitude** treats the field as a single tilted bar magnet
  through Earth's centre (north pole at ~80.7° N, 72.7° W) and is a pure
  spherical rotation of the geographic coordinates. For Wrocław
  (51.11° N, 17.03° E) it gives ~50°.
- **Corrected geomagnetic (CGM / AACGM) latitude** traces the actual IGRF
  field line from the location to the magnetic equator and labels the place
  with the dipole coordinates of that crossing. Auroral particles precipitate
  along field lines, so this is the latitude the oval actually follows, and it
  is what NOAA, OVATION and the aurora sites use. For Wrocław it gives ~47°.

They differ over Europe because the real field is offset ~500 km from
Earth's centre toward the western Pacific and bent by the non-dipole
Siberian anomaly, which connects European field lines to lower dipole
latitudes than the plain rotation suggests (and North American ones to
higher). That asymmetry is why the oval reaches further south over Canada and
the US than over Europe at the same geographic latitude.

**Use the CGM value.** Wrocław ≈ 47°, Kraków ≈ 46°; both should be stored as
a per-configuration constant rather than computed at runtime, since an AACGM
dependency is not worth it for two cities.

### Levels

Generalised for a location with CGM latitude `mlat` and a horizon-visibility
allowance of ~5° of latitude: `kpMin = (66 − (mlat + 5)) / 2` rounded to the
nearest whole step, then levels at `kpMin − 1`, `kpMin`, `kpMin + 1`. For
Wrocław `kpMin = 7`:

| Level | Kp / Hp60 | NOAA scale | What it means at Wrocław |
| --- | --- | --- | --- |
| `0` | < 6 | quiet – G1 | nothing to see |
| `1` | 6 – 6.99 | G2 | camera-only glow on the northern horizon, on a good night |
| `2` | 7 – 7.99 | G3 | faint naked-eye glow / red pillars low in the north |
| `3` | ≥ 8 | G4 – G5 | proper display, colour visible, possibly overhead |

This matches recent experience: the G3 storms of November 2023 and October
2024 (Kp 7) gave a photographable red glow across Poland, while only the
May 2024 G5 storm (Kp 9) put the aurora overhead.

Which value to threshold: for nights 1–3 use the GFZ **`median`** for the
level, and mark the slot to blink up to full (see
[Showing the Row on the Device](#showing-the-row-on-the-device)) when the
ensemble gives at least a 25 % chance of reaching level `3` (`prob >= 8`),
or its 0.75-quantile does, so a storm the ensemble is split about still shows as a
possibility. For nights 4–7 threshold the 27-day `Largest Kp` directly. These
weights are a first guess to tune by eye, like the cloud-coverage thirds were.

## Concerns And Risks

- **Skill drops sharply with lead time.** Days 1–3 come from a physics/ML model
  fed by live solar-wind data; days 4–7 come from a recurrence outlook that
  cannot see a CME launched after Monday. A big storm typically appears in the
  forecast 1–3 days ahead, so the display's far-right columns will mostly say
  "quiet" even in the week of a storm. That is inherent, not a supplier defect;
  the outlook's slots are capped at level `1`, "possible" (see
  [Showing the Row on the Device](#showing-the-row-on-the-device)), since
  brightness is already the level and cannot also carry confidence.
- **Two providers, two shapes, two clocks.** GFZ's JSON is column-oriented with
  `dd-mm-yyyy HH:MM` strings and no `Cache-Control`; NOAA's is row-oriented ISO
  timestamps without a `Z`. Both are UTC and must be re-binned into the
  local-noon-to-noon night model (`Europe/Warsaw`) already used by
  `#WEATHER`; the 27-day rows are UTC calendar days, so a "night" straddles two
  of them — take the max of both.
- **GFZ has no stated SLA and no cache headers.** `Last-Modified` moves hourly.
  Fetching every six hours with the existing job cadence is far below anything
  that would register.
- **File names encode the model** (`FORECAST_HP60_SWIFT_DRIVEN_LAST`); a PAGER
  pipeline change could rename them. The NOAA 3-day feed is the fallback for
  exactly that case, at the cost of 3-hour instead of 1-hour resolution.
- **Attribution.** CC BY 4.0 requires crediting GFZ (and the requested
  citation) wherever the data is republished — the API docs and any web UI.
  NOAA data is public domain but SWPC asks to be credited as the source.
- **Hp60 vs Kp above 9.** Hp60 is open-ended; clamp before thresholding.
- **Accuracy was not evaluated**; this test only established availability,
  shape, and terms.

## Fetch Cadence

The sources move at four different speeds and the device consumes at two, so
the cadence follows whichever is slower, and the nowcast is gated on activity
rather than scheduled.

### Device cadence and the storm-night flag

The HostController pulls the API every six hours (00:10, 06:10, 12:10 and
18:10 local). A flag in the API response switches it to **hourly** pulls; the
API sets the flag for a location's current night when there is a chance of
aurora. The flag is:

- **Eager**: set when any hour of the night has a GFZ `0.75-quantile` ≥ 5 or
  `P(≥6)` ≥ 25 %, or the NOAA 3-day forecast has a bin ≥ 5 — one Kp step below
  level `1`. An hourly pull is cheap, so a false alarm is cheap; a missed storm
  is not.
- **Sticky**: once set for a `nightId` it stays until that night ends, so the
  device does not alternate cadences as forecast runs disagree.
- **Late by design**: the device sees a newly set flag only at its next
  six-hourly pull, up to six hours after the forecast turned. The eager
  trigger, decided from a forecast that runs hourly, is what closes most of
  that gap.

### Job cadence

| Situation | Job runs | Fetches |
| --- | --- | --- |
| Quiet (no location flagged) | with the existing weather job, every 6 h at 00/06/12/18 local | Hp60, NOAA 3-day, 27-day outlook |
| Daily | once at ~03:00 UTC | 27-day outlook (issued Mondays ~02:20 UTC; catches a mid-week reissue) |
| Storm night (a location flagged and dark there) | **every 10 minutes** | Hp60, NOAA 3-day, OVATION |
| Any dark night | every 10 minutes | NOAA live Kp (28 KB): a storm no forecast flagged sets the flag and starts the sampling |

The three forecast feeds are global: one fetch per run serves every
configured location. Every source sends `Last-Modified`, so the runs poll
with `If-Modified-Since` and an unchanged file costs a 304. Runs are offset
from the hour (GFZ writes at ~:05, NOAA regenerates around :00), so the
storm-night schedule is `:03, :13, :23 …`, which also leaves the device's :10
pull a nowcast at most seven minutes old. NOAA's `Cache-Control: max-age=60`
is far above any of these rates. On a storm night the job moves about 55 MB
(OVATION is 920 KB) in ~60 invocations; on a quiet night, ~30 KB in four.

A feed that answers but has stopped updating does not fail the run: the file
is stored as usual, and the merge passes it over (see
[Merging Sources](#merging-sources)). When its `Last-Modified` is more than
12 hours old the run logs `Aurora forecast source stale` and lists the source
under `stale` in its summary. GFZ went quiet this way from 3 October 2026,
and nothing showed it in the logs.

### Why ten minutes and not an hour

For the display alone, hourly at :03 would do: the device pulls hourly and
Hp60 changes hourly. Ten minutes buys three things the display cadence does
not:

- **Substorm peaks.** Auroral activity is bursty on a 20–60 minute scale, so
  one snapshot per hour can land in a lull and print 3 % for an hour that
  peaked at 30 %. With six samples per hour the job stores the **maximum over
  the hour** for each slot as well as the latest value, so a back-filled slot
  says whether there was aurora that hour, not what L1 looked like at :03.
- **Calibration data.** The OVATION % → level mapping is the least known part
  of the design and is only ever calibrated on the few storm nights a year;
  ~60 samples a night instead of ~10 makes those nights count.
- **Resilience.** A failed :03 fetch leaves the device an hour-old nowcast
  under hourly polling, and a 13-minute-old one under ten-minute polling.

Thirty minutes is the worst of both: too coarse for peaks, no simpler than ten.

### How the nowcast lands in the row

- A fetch writes its level into the slot that OVATION's `Forecast Time` falls
  in — usually the *next* hour — and a slot keeps the latest nowcast that
  targeted it, plus the maximum seen. Over a storm night the row fills in
  hour by hour: the current hour shows the nowcast fetched about an hour ago,
  the next hour the fresh one, everything beyond stays forecast.
- Until the mapping is calibrated, the nowcast only **raises** a slot above
  its forecast level, never lowers it; the failure mode is then an optimistic
  hour, not a hidden storm. Placeholder thresholds: `1` ≥ 5 %, `2` ≥ 15 %,
  `3` ≥ 40 %, with the raw percentage logged on every storm-night fetch.
- Daylight slots are skipped; there is nothing to see and the nowcast would
  only add noise.
- The current and next slot blink down at their nowcast level when the
  nowcast puts them at level `1` or more, so a live cell can be told from a
  forecast one; back-filled past hours stay steady. See
  [Showing the Row on the Device](#showing-the-row-on-the-device).

The first implementation step is the cheapest: run the storm-night nowcast
fetch with **logging only**, so a calibration set accumulates before any
nowcast value reaches the display.

## Calibrating the Nowcast

The forecast row is in Kp; the nowcast cell is in OVATION's "probability of
visible aurora" for a 1° cell. Nothing published relates the two for a place
at 47° CGM, and the placeholder thresholds above (`1` ≥ 5 %, `2` ≥ 15 %,
`3` ≥ 40 %) are a guess. They can only be calibrated on real storms, which
come a few nights a year, so the logging has to be in place **before** the
next one, and the nowcast must not shape the display until it is done.

### When samples are taken, and where they are kept

A storm the forecasts missed is the case calibration needs most, so sampling
does not rely on the forecast flag alone. Every ten-minute run on a dark night
reads NOAA's live Kp estimate
(`https://services.swpc.noaa.gov/json/planetary_k_index_1m.json`, one row per
minute) and takes its maximum over the last 30 minutes. At or above the
location's flag Kp, the run flags the night itself (reason `live kp=…`), which
also switches the device to hourly refreshes from its next pull, and samples.
If the live file cannot be read, the run falls back to the flag alone.

Each sample is written twice: as the `aurora-calibration` log line (CloudWatch
keeps 30 days) and as a DynamoDB item that never expires, under
`pk = LOC#<configurationId>`, `sk = CALIBRATION#AURORA#<observedAt>`, one per
location and run. Storms worth calibrating on come a few times a year, so the
items are the record to analyse; the log line is for looking at a night while
it happens. A failed write is logged and does not stop the run.

### What each sample holds

One structured sample per location per ten-minute run:

| Field | Source | Why |
| --- | --- | --- |
| `observedAt`, `validAt` | OVATION `Observation Time`, `Forecast Time` | Aligns the sample with the hour it describes. |
| `cellPct` | OVATION, the location's cell | The value the placeholder mapping uses. |
| `northPct[]` | OVATION, the cells 1°–8° north on the same meridian | An observer at 47° CGM sees the oval low on the northern horizon, hundreds of kilometres away; the cell overhead can read 0 % while the cells at 54°–56° N read 30 % and the glow is plainly visible. The profile shows which cell, if any, predicts what is seen. |
| `hp60Median`, `hp60Max`, `probAtLeast6` | GFZ Hp60 for the hour of `validAt` | The forecast the nowcast is compared with. |
| `kpEstimated` | NOAA 3-day, the `observed` or `estimated` bin in progress when the sample is taken | NOAA's running estimate of the current Kp. |
| `kpNoaaAtValid`, `kpNoaaAtValidStatus` | NOAA 3-day, the bin covering `validAt` | What NOAA says for the hour the nowcast describes; usually still a forecast. NOAA marks the whole rest of the current UTC day `estimated`, so the status alone does not tell a measurement from a forecast. |
| `liveKp`, `liveKpAt` | NOAA live Kp, the last 30 minutes' maximum | The minute-by-minute Kp that also gates the sampling. |
| `sampledAt` | the run | When the sample was taken. |
| `level` | the row's forecast level for that slot | What the display would have shown without the nowcast. |
| `dark` | astronomy for the location | Daylight samples are excluded from the analysis. |

The definitive Kp for each three-hour bin arrives a day later as the
`observed` rows of the same NOAA file (or from `kp.gfz.de/app/json/`); the
analysis joins it by time rather than logging it live.

### Ground truth

Kp and OVATION are both proxies; the thing being calibrated is *visibility
from the configured locations*. For each storm night, record what was
actually seen, with times: own observations and photographs, and public
reports from Polish observers (the sighting threads that appear on every
G2+ night are dated to the minute and give the direction and height above the
horizon). A night with no reports despite clear skies is data too.

### Analysis

After each storm night, for every dark ten-minute sample:

1. Tabulate `cellPct`, `max(northPct)`, `hp60Median`, the definitive Kp and
   the visibility record for that time.
2. Check the forecast side first: did level `1`/`2`/`3` (Kp 6/7/8) coincide
   with camera-only / naked-eye / overhead reports? This validates the
   magnetic-latitude thresholds and is independent of OVATION.
3. Then find the `cellPct` (or `northPct`) values that coincide with the same
   three visibility classes, and set the nowcast thresholds from them. Decide
   from the data which cell predicts better, the location's own or the
   northern profile's maximum.
4. Compare the ten-minute samples within an hour with the hour's maximum, to
   see whether the max-over-hour rule is worth keeping.

### Exit criterion

Keep the nowcast in **raise-only** mode (it can lift a slot above its
forecast level, never lower it) until at least three G2+ nights have been
logged and analysed. Only then let it set the slot outright, and revisit the
thresholds after every further G3+ night; the oval's behaviour at the
equatorward edge is not linear in Kp, and the biggest storms are the ones the
row exists for.

## Merging Sources

Each slot of a night takes its value from the best source that covers it, so
the cut-over from a better source to a worse one falls exactly where the
better one runs out of data.

### The rule

For each of the night's 21 hourly observing slots (14:00 → 10:00 local), **the
highest-ranked source whose span contains the slot's midpoint wins**.
`observingSlots()` in `forecast/nights.ts` already gives each slot its
`midpoint`. With whole-hour zone offsets every span boundary falls on a slot
boundary, so the test is exact; the midpoint also handles half-hour zones and
OVATION's odd-minute windows without special cases.

| Rank | Source | Covers | Unit |
| --- | --- | --- | --- |
| 0 | OVATION nowcast | slots its `Forecast Time` fell in (latest and max over the hour) | % → level; **raise-only** until calibrated |
| 1 | NOAA observed Kp, and the estimated bin in progress | three-hour bins that have started | Kp |
| 2 | GFZ Hp60 | now → +72 h, hourly | Hp60 median, blinking up when the ensemble reaches level `3` |
| 3 | NOAA 3-day predicted | three-hour bins to the end of UTC day 3 | Kp |
| 4 | NOAA 27-day outlook | UTC days | largest Kp of the day |
| — | none | | `?` (unknown) |

For example (the exact hours move with each fetch): on a night in CEST where
GFZ ends at 18:00 UTC, GFZ covers 14:00–19:59 local, the NOAA 3-day bins may
carry on for a few more hours, and the 27-day outlook takes the rest: its
first UTC day until 01:59 local and the next UTC day from 02:00. A night
covered only by the outlook is the same case — two spans from two
consecutive UTC days, split at local 01:00 or 02:00.

### Details that make it work

1. **Merge on Kp, threshold once.** Ranks 1–4 all yield a Kp-equivalent, and
   the location's magnetic-latitude thresholds (see
   [Levels](#levels)) turn the merged value into a level in one place, so
   every source is judged on the same scale. The GFZ ensemble blink up (≥ 25 %
   for level `3`) applies to GFZ slots only. The nowcast is in a
   different unit, so it has its own % → level mapping and merges at the
   level stage.
2. **Past hours have a source.** GFZ starts at the current hour, so tonight's
   earlier slots would otherwise fall through to the outlook or to `?`.
   NOAA's `observed` bins and the `estimated` bin in progress cover them (an
   `estimated` bin that has not started is a forecast and ranks with the
   predicted ones, below GFZ), and on a storm night the
   nowcast's max over the hour raises them further, so past hours show what
   happened rather than an old forecast. (The web tool drops those bins; the
   merge keeps them.)
3. **Fallback is by freshness, not only presence.** GFZ outranks the NOAA
   3-day forecast only while its file was fresh when fetched (`fetchedAt` at
   most three hours after `Last-Modified`) and the fetch itself is recent (at
   most seven hours old, which allows one missed six-hourly run). The file's
   age cannot be judged at read time alone: with six-hourly ingestion the
   stored copy is routinely hours old. If the fetch failed or the file went
   stale, its slots fall through to rank 3; the cascade is the fallback.
4. **Seams are marked, not smoothed.** The 27-day value is a *daily maximum*,
   while GFZ gives an hourly median, so crossing from rank 2 to rank 4
   typically steps up (median 2 → daily max 4). That is honest — "this day
   may reach 4" — but reads as a spike. Each slot carries its `source`, and
   the outlook's slots are capped at level `1`, "possible", so the outlook can
   never look stronger than the forecast before the seam; see
   [Showing the Row on the Device](#showing-the-row-on-the-device).
5. **The nowcast is an overlay for now.** Until
   [calibration](#calibrating-the-nowcast) is done it only raises a slot above
   the cascade's result, never lowers it. After calibration it becomes rank
   0 outright.

### Where the merge runs

At **read time, in the API**, not at ingestion. Ingestion stores each
source's spans raw per night; a pure `mergeAurora(slots, sources, now,
thresholds)` function applies the cascade when the payload is assembled, as
`weather-reader.ts` and `assemble.ts` do for weather, and is unit-tested with
the saved fixtures. Changing the ranking, the freshness limit or the
thresholds then needs no re-ingestion, and the per-slot `source` can be shown
in the web tools for debugging.

Per slot the merge yields the `level`, the `source` and the value it came
from (Kp, or % for the nowcast), and whether the slot blinks. The payload
row is encoded as in
[Showing the Row on the Device](#showing-the-row-on-the-device); the
storm-night flag is decided from the same merged night.

## Showing the Row on the Device

### What the device and the payload can express

Every matrix pixel has a brightness **level** 0–3 (lit for 0 / 12 / 39 / 70 %
of its slot) and an independent **blink** bit: a blinking pixel shows at its
level for 0.5 s and is dark for 0.5 s, on a phase each board keeps itself
(see `firmware/HostControllerA/docs/Display.md`, "Blink and brightness
levels"). The protocol 2 payload uses only part of that: `0`–`3` are steady
levels, `*` is level 3 blinking, and `?` is unavailable (see
[api-payload.md](api-payload.md), "Matrix encoding").

Brightness is the aurora level itself, so it cannot also carry confidence:
there is no "level 2, but less sure" in four brightness states. Anything
beyond the level has to be carried by blinking.
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

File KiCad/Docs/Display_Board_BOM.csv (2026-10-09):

Section | References | Qty per board | Value | Part / MPN | Footprint | Notes
MCU | U302 | 1 | STM32G070CBT6 | STM32G070CBT6 (TME) | LQFP-48 7x7 | pin-compatible with the STM32G0B1 on this board; no USB - console over USART2 PA2/PA3 (see Display_Board_Purchasing.md)
MCU | C101,C301,C305 | 3 | 100n | MLCC X7R 50V | 0603 | decoupling + NRST
MCU | C302 | 1 | 4u7 | Samsung CL21A475KAQNNNE (25V X5R) | 0805
MCU | J103 | 1 | SWD | JST B6B-PH-K-S | JST PH 1x06 2.00mm vertical | programming; optional if you use pogo pins
MCU | J102 | 1 | Conn_01x10 | 1x10 female socket 2.54mm right-angle | PinSocket_1x10 horizontal | daisy chain: I2C / VBUS / GND
MCU | J104 | 1 | Conn_01x10 | 1x10 male header 2.54mm right-angle | PinHeader_1x10 horizontal | daisy chain: I2C / VBUS / GND
Power | U601 | 1 | TPS54202 | TPS54202DDCR (TME) | SOT-23-6 | TPS54302 unavailable - TPS54202 is pin-compatible (2A); buck VBUS -> VDD (~3.7V)
Power | U602 | 1 | MCP1825S | MCP1825S-3302E/DB (TME) | SOT-223-3 | 3.3V LDO
Power | L601 | 1 | 33u | Ferrocore DE0704-33 (TME) | L_Bourns_SRP7028A_7.3x6.6mm | 7.3x7.3x4.5 fits the SRP7028A pads (0.27 mm to C602); fallback Bourns SRR6838A-330M (Farnell 4655301)
Power | C601 | 1 | 100n | MLCC X7R 50V | 0805 | bootstrap
Power | C602 | 1 | 10u/35V | MLCC X5R/X7R 35V+ | 0805 | VBUS input
Power | C603 | 1 | 100n/35V | MLCC X7R 50V | 0603 | VBUS input
Power | C604,C605 | 2 | 22u | MLCC X5R/X7R 10V+ | 1206 | VDD output
Power | C606 | 1 | 4u7 | Samsung CL21A475KAQNNNE (25V X5R) | 0805 | LDO input
Power | C607 | 1 | 1u | MLCC X7R 10V+ | 0805 | LDO output
Power | C608 | 1 | 47p | MLCC C0G 50V | 0805 | feed-forward
Power | R601 | 1 | 100k | 1% | 0805 | FB divider
Power | R602 | 1 | 19k2 | 1% | 0805 | FB divider
Display | U501,U505,U513 | 3 | SCT2024 | SCT2024CSSG | SSOP-24 3.9x8.7mm | 16-ch LED driver
Display | U510 | 1 | SCT2167 | SCT2167CSSG | SSOP-16 3.9x4.9mm | 8-ch LED driver
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

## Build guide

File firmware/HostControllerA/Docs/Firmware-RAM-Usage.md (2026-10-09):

# Firmware RAM Usage

Where the HostController's RAM goes, from the Debug build of 2026-10-10
(`build/Debug/HostControllerA.elf`, GNU Tools for STM32 14.3.1). The ST67
module runs the T01 firmware, so TCP/IP and TLS are in the module and no
network stack is linked on the host; see [WiFi.md](WiFi.md). Earlier
measurements, including the T02 configuration with LwIP, and the reduction
plan are in [archive/RAM_Usage_History.md](archive/RAM_Usage_History.md).

## Summary

| Item | Bytes |
| --- | ---: |
| RAM capacity, STM32G0B1CETx | 147456 (144 KiB): the 139 KiB `RAM` region plus the 5 KiB `NOINIT` region |
| `.data` | 644 |
| `.bss` | 91472 |
| `._user_heap_stack`: C heap `0x200` + main stack `0x400` | 1536 |
| **`RAM` region in use**, as the link reports it | **93656** of 142336 (65.8%) |
| **`RAM` region left** | **48680** |
| `.noinit` (`NOINIT` region) | 4364 of 5120 |

The `NOINIT` region at the top of RAM holds the error log
(`ErrorLog::Storage`, 24 entries of 160-byte text). The startup code does not
clear it, so the log survives a reset; see [Console.md](Console.md#error-log).
The linker script change that creates it is described in
[Development.md](../../Docs/Development.md).

The figures are address-space reservation at link time, not use at any one
moment. 32 000 B of it is the FreeRTOS heap, whose use is only visible at run
time; see [FreeRTOS heap](#freertos-heap).

## Largest RAM Reservations

From `arm-none-eabi-nm -S --size-sort` on the same ELF:

| Allocation | Bytes | Owner / source |
| --- | ---: | --- |
| FreeRTOS heap (`ucHeap`) | 32000 | `configTOTAL_HEAP_SIZE` in `Core/Inc/FreeRTOSConfig.h` |
| `St67HttpFetchTask` object | 8928 | 4096-byte stack and `St67Runtime`, including its own 4096-byte `httpPayload`, and the fetcher's `ApiTarget`; `User/Src/WiFi/St67HttpFetchTask.cpp` |
| `AstroDataRefreshTask` object | 8552 | 3840-byte stack, 4096-byte response buffer and state; `User/Inc/Astro/AstroDataRefreshTask.hpp` |
| `LogService` object | 6464 | 1536-byte stack and a 16-entry queue of 257-byte events; `User/Inc/Debug/LogService.hpp` |
| Error log (`errorLogStorage`, `NOINIT`) | 4364 | `User/Src/Debug/LogService.cpp` |
| Error log copy for `errors` (`snapshot`) | 4364 | `User/Src/Console/ErrorsCommand.cpp` |
| `ConsoleService` object | 4768 | 2816-byte stack, 8-entry command queue of 128-byte lines, 256-byte RX ring; `User/Inc/Console/ConsoleService.hpp` |
| USB CDC buffers | 4096 | `UserRxBufferFS` and `UserTxBufferFS`, 2048 bytes each |
| `CurrentSenseTask` object | 2480 | 2048-byte stack |
| `MainLoopTask` object | 2480 | 2048-byte stack |
| `ClockTask` object | 1600 | 1024-byte stack |
| `DisplaySyncTask` object | 2528 | 2048-byte stack, the sync schedule and the boards' last status; `User/Src/Display/DisplaySyncTask.cpp` |
| USB device state | about 2000 | `hpcd_USB_DRD_FS` 736, `hUsbDeviceFS` 732, `USBD_StrDesc` 512 |
| FreeRTOS static support | about 3400 | Idle stack 512, timer stack 1024, their TCBs 384 each, ready lists 1120 |
| ST67 static driver state | about 1200 | `W61_Obj` 992 bytes, the SPI transfer engine state |
| `localBoard` (`PcbDisplayBoard`) | 968 | Content and attributes, two 280-byte sets of prepared pass frames, the sequencer, the timeline servo and its two frame records |
| `settingsStore` (`Settings::Store`) | 844 | `Values` (including the 65-byte API host and path), two 256-byte working images for `load()`/`save()`, the mutex; `User/Inc/Settings/SettingsStore.hpp` |

The same astro payload is held twice: once in `St67Runtime::httpPayload`,
which only the stress batches write, and once in
`AstroDataRefreshTask::responseBuffer_`, which every refresh uses. Holding it
once would save 4 KB; it is listed with the open items in the
[README](../README.md).

## FreeRTOS Usage

### FreeRTOS heap

`configTOTAL_HEAP_SIZE` is 32 000 B, for `heap_4.c`. It holds `defaultTask`
until it exits after starting USB, the CMSIS objects created without static
memory, the ST67 driver's two tasks and its queues, event group and transfer
buffers, and the HTTP client's per-request buffers: a 2 KiB header buffer, a
1 KiB read buffer and a 512-byte request, plus the driver's socket state.
Application tasks and their stacks are static.

Measured on the bench with this heap size:

| State | Free |
| --- | ---: |
| Before the module starts | about 31 000 B |
| Module and its two tasks up, idle | about 21 400 B |
| Lowest through an HTTPS fetch (`heapMin`) | about 16 400 B |

The peak demand is about 15.9 KB, on a re-initialisation after `stop()`,
which leaves about twice an 8 KiB margin; it stays flat over 100 HTTPS cycles.
Reduce the heap further only after measuring `heapMin` under the worst-case
WiFi workload: connect, DHCP, HTTPS, the certificate upload, failure paths
and a restart after `stop()`.

### Static reservation

- Idle task stack: `512` bytes (`configMINIMAL_STACK_SIZE` 128 words)
- Timer task stack: `1024` bytes (`configTIMER_TASK_STACK_DEPTH` 256 words)
- Idle and timer TCBs: `384` bytes each
- Ready-task lists and scheduler state: about `1120` bytes
- The application task objects listed above, whose stacks are static

### Runtime diagnostics

`stats on` makes `LogService::emitStats()` report periodically:

```text
[STATS] sent=<lines> dropped=<lines> busyDrop=<lines>
[MEM] heapFree=<current free bytes> heapMin=<minimum-ever free bytes>
[STACK] name=<task> configured=<configured bytes> remaining=<high-water bytes>
```

`[STACK]` covers the application's `Task<>` objects only, not `defaultTask`
or the middleware tasks. Reduce a stack only after checking its high-water
mark under its deepest call path. `log()` and `logf()` build their 257-byte
line on the caller's stack, so every task that logs needs that headroom.

### Tasks and configured stacks

Application tasks, with static stacks inside their objects:

| Task (name in `[STACK]`) | Stack | Priority | Source |
| --- | ---: | --- | --- |
| `St67HttpFetch` | 4096 | BelowNormal | `User/Src/WiFi/St67HttpFetchTask.cpp`; the W6X socket path and the driver's AT trace run on it |
| `AstroDataRefresh` | 3840 | Normal | `AstroDataRefreshTask.hpp`; the clock sync and the logging run on it; 2936 used after a refresh with clock sync (bench, 2026-10-10) |
| `ConsoleService` | 2816 | Normal | `ConsoleService.hpp`; `status` is its deepest command, 1824 used (bench, 2026-10-10) |
| `CurrentSense` | 2048 | BelowNormal | `CurrentSenseTask.hpp` |
| `MainLoopTask` | 2048 | Normal | `MainLoopTask.hpp`; the boot screens encode frames on it, 944 used at peak |
| `LogService` | 1536 | Normal | `LogService.hpp` |
| `Clock` | 1024 | BelowNormal | `ClockTask.hpp` |
| `DisplaySync` | 2048 | AboveNormal | `DisplaySyncTask.hpp`; 1008 used after a logged burst and a logged content re-send (bench, 2026-10-07) |

Generated and middleware tasks, with stacks from the FreeRTOS heap unless
noted:

| Task | Stack | Source |
| --- | ---: | --- |
| `defaultTask` | 512 | `Core/Src/main.c`, `128 * 4`; freed when it exits after starting USB |
| FreeRTOS idle | 512 | static, see above |
| FreeRTOS timer | 1024 | static, see above |
| ST67 modem RX task | 2048 | `W61_MDM_RX_TASK_STACK_SIZE_BYTES` in the ST67 driver |
| ST67 SPI transfer engine | 1536 | `SPI_THREAD_STACK_SIZE` in `ST67W6X_Network_Driver/Target/w61_driver_config.h` |

The driver's own HTTP client (`w6x_http.c`) is not linked: the firmware uses
its own `User/Src/WiFi/HttpClient.cpp` on the fetch task. `St67ProbeTask`
(`Task<2048>`) is compiled but has no instance in this image.

## ST67 Middleware Usage

ST67 has two kinds of RAM cost:

1. Static driver state linked into `.bss`, about 1200 bytes including the
   992-byte `W61_Obj`.
2. Dynamic allocations from the shared FreeRTOS heap: the modem RX task and
   its receive buffer (`W61_MAX_SPI_XFER = 1520` bytes), the SPI transfer
   task, queues, event group and transfer buffers, scan results, and socket
   state. The module up and idle costs about 10 KB of the heap, a fetch about
   5 KB more.

The dynamic allocations are not visible in the ELF; `heapFree` and `heapMin`
show them.

## Verification Commands

From Git Bash, with the toolchain on `PATH` (see
[Development.md](../../Docs/Development.md)):

```bash
arm-none-eabi-size -A -d build/<preset>/HostControllerA.elf
arm-none-eabi-nm -S --size-sort --radix=d -C build/<preset>/HostControllerA.elf
```

The most important link-time values are `.data`, `.bss`, `.noinit`,
`._user_heap_stack` and `ucHeap`. `arm-none-eabi-size -B` reports `bss`
including `._user_heap_stack`. Compare the link-time results again after every
RAM configuration change.

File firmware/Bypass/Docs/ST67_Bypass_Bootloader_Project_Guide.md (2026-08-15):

# ST67 Bypass and Bootloader Project Guide

## Purpose

Extend an already bootstrapped, working STM32G0B1 CMake firmware that currently echoes data over USB CDC. Its final job is to connect a PC to the ST67:

```text
PC USB CDC <-> STM32G0B1 USB device <-> USART2 <-> ST67
```

The starting project is otherwise empty and has no access to the mission application's source code. It already builds, flashes, enumerates as a CDC device, receives USB data, and sends the echo response. Preserve that working USB setup while replacing echo behavior with a foreground superloop, interrupt-driven UART reception, and bidirectional forwarding. Do not add FreeRTOS.

The bypass transport must be binary-transparent. This is required for a bootloader protocol and is also the least surprising behavior for manufacture-mode access. Do not parse lines, echo characters, translate line endings, strip ANSI escape sequences, or interpret payload bytes in the bridge.

## Hardware and Protocol Inputs

Treat the following as the complete implementation inputs; no external application code is required.

| Signal | STM32 pin | Configuration |
|---|---:|---|
| `ST67_CHIP_EN` | PA0 | GPIO push-pull output |
| `ST67_TX` | PA2 | USART2 TX, AF1, very-high speed, no pull |
| `ST67_RX` | PA3 | USART2 RX, AF1, very-high speed, no pull |
| `ST67_RDY` | PA4 | GPIO input, no pull |
| `ST67_CS` | PA5 | GPIO push-pull output; high while using UART |
| `ST67_BOOT` | PB1 | GPIO push-pull output |
| USB DM | PA11 | USB DRD FS |
| USB DP | PA12 | USB DRD FS |

The proven UART format is:

- USART2
- 2,000,000 baud
- 8 data bits
- no parity
- 1 stop bit
- no hardware flow control
- oversampling by 16
- peripheral clock from PCLK1
- UART FIFO enabled
- RX FIFO threshold 1/8

Configure USART2 directly at 2,000,000 baud.

The working manufacture-mode pin state is:

```text
ST67_CS      = 1
ST67_BOOT    = 0
ST67_CHIP_EN = 1
```

Use a deterministic entry sequence rather than relying on reset defaults:

```text
1. Drive ST67_CHIP_EN low.
2. Drive ST67_CS high.
3. Drive ST67_BOOT low for manufacture mode.
4. Wait at least 20 ms.
5. Drive ST67_CHIP_EN high.
6. Wait for ST67 startup before expecting traffic.
```

Use a 20 ms low pulse and initially wait at least 20 ms after raising `CHIP_EN`. Increase the final startup delay if the ST67 documentation requires it. `ST67_RDY` may be observed for diagnostics, but bypass traffic does not need to be gated on it.

### Bootloader mode is not yet electrically specified

Do not infer the ST67 bootloader strap from the name `ST67_BOOT` alone. The only established mode is that `BOOT=0`, `CS=1`, and an enable/reset cycle enters the observed manufacture shell. Before implementing bootloader entry, obtain the ST67W6 hardware/programming documentation and record:

- required `BOOT` level;
- required `CS` level;
- whether any additional strap pin is sampled;
- setup time before `CHIP_EN` rises;
- minimum reset/enable pulse width;
- UART baud and framing used by the ROM bootloader;
- bootloader handshake, timeout, and reset-exit behavior.

Keep mode selection isolated in one function so those verified values do not leak into the transport code.

## Integration Scope

Keep the existing project layout and add only a small bridge module. A typical resulting layout is:

```text
CMakeLists.txt
CMakePresets.json
<project>.ioc
cmake/
Core/
  Inc/
    main.h
    bridge.h
  Src/
    main.c
    bridge.c
    stm32g0xx_it.c
    stm32g0xx_hal_msp.c
USB_Device/
Drivers/
Middlewares/ST/STM32_USB_Device_Library/
```

Do not add these application-only parts:

- FreeRTOS and CMSIS-RTOS2;
- `app_freertos.c` and `FreeRTOSConfig.h`;
- `Task<>`, `DebugService`, `AstroWeather`, or application variants;
- SPI1, unless later required by a documented ST67 programming procedure;
- switch and application LED interrupts, unless deliberately used for mode selection/status.

C is sufficient for this project. Use C11 and avoid enabling C++ unless another project requirement needs it.

## CubeMX Configuration

The project is already bootstrapped, so do not recreate it. Verify its MCU is the exact device used by the board:

```text
STM32G0B1CET6, LQFP48
STM32CubeG0 firmware package 1.6.3
Toolchain: CMake
```

Keep the already-working USB CDC configuration. Add or verify only the settings below. If the existing project was generated from an `.ioc`, make peripheral changes there and regenerate so the CMake source inventory remains consistent.

### Clock tree

Verify the clock configuration:

- HSI: 16 MHz, enabled;
- HSI48: enabled for USB;
- PLL source: HSI;
- PLLM: /1;
- PLLN: x8;
- PLLR: /2;
- SYSCLK/HCLK/PCLK1: 64 MHz;
- USB clock: HSI48 at 48 MHz;
- voltage scaling: Scale 1;
- Flash latency: 2.

Use SysTick as the HAL time base in this non-RTOS project.

### USB

- Preserve the existing USB DRD FS device-only configuration.
- Preserve the existing USB Device CDC Full Speed middleware and `USB_UCPD1_2_IRQn`.
- Keep the existing generated `usb_device.c`, `usbd_desc.c`, `usbd_cdc_if.c`, and `usbd_conf.c` files.
- Keep the descriptors if the echo device already enumerates correctly; optionally use a product name that clearly identifies this utility firmware.

The generated USB interrupt handler must call:

```c
void USB_UCPD1_2_IRQHandler(void)
{
    HAL_PCD_IRQHandler(&hpcd_USB_DRD_FS);
}
```

### USART2

Configure PA2/PA3 for USART2 asynchronous TX/RX with the proven format above. Enable `USART2_LPUART2_IRQn` and choose an interrupt priority that cannot be blocked by USB processing for long periods. Without FreeRTOS, priority 1 is suitable; USB can use the generated default priority.

After `HAL_UART_Init`, enable FIFO mode and RX interrupts:

```c
if (HAL_UARTEx_SetTxFifoThreshold(&huart2, UART_TXFIFO_THRESHOLD_1_8) != HAL_OK) {
    Error_Handler();
}
if (HAL_UARTEx_SetRxFifoThreshold(&huart2, UART_RXFIFO_THRESHOLD_1_8) != HAL_OK) {
    Error_Handler();
}
if (HAL_UARTEx_EnableFifoMode(&huart2) != HAL_OK) {
    Error_Handler();
}

__HAL_UART_ENABLE_IT(&huart2, UART_IT_RXFNE);
HAL_NVIC_SetPriority(USART2_LPUART2_IRQn, 1, 0);
HAL_NVIC_EnableIRQ(USART2_LPUART2_IRQn);
```

Cube/HAL naming differs slightly between package versions. The direct register equivalent is:

```c
huart2.Instance->CR1 |= USART_CR1_RXNEIE_RXFNEIE;
```

### GPIO startup safety

Set output levels before configuring pins as outputs to prevent glitches. The safe initial state is `CHIP_EN=0`; set `CS` and `BOOT` to the desired strap values before enabling the ST67.

## Firmware Startup

The bare-metal startup order should be:

```c
int main(void)
{
    HAL_Init();
    SystemClock_Config();
    MX_GPIO_Init();
    MX_USART2_UART_Init();
    Bridge_Init();
    MX_USB_Device_Init();
    ST67_EnterMode(ST67_MODE_MANUFACTURE); /* or verified bootloader mode */

    while (1) {
        Bridge_Process();
    }
}
```

`Bridge_Init` must reset ring indices and enable the USART2 RX interrupt. Initialize USB before enabling the ST67, but keep `CHIP_EN` low until all ST67 strap outputs are configured. USB initialization does not mean that enumeration is complete or that the PC has opened the CDC port. The UART RX ring must therefore be large enough to retain startup output, or the design must provide a deliberate hardware reset action.

## Echo-to-Bypass Migration

Make the change in this order so the known-good USB path remains easy to test:

1. Confirm the unmodified project still echoes arbitrary binary USB packets using their explicit lengths.
2. Add the ST67 GPIO labels and USART2 configuration described above.
3. Add `bridge.h` and `bridge.c`, then include `bridge.c` in the existing CMake executable target.
4. Call `Bridge_Init()` after UART initialization.
5. Replace the echo operation in `CDC_Receive_FS` with `Bridge_OnUsbRx(buffer, *length)` and immediately rearm the OUT endpoint.
6. Wire `CDC_TransmitCplt_FS` to `Bridge_OnUsbTxComplete()`.
7. Replace the empty foreground loop with repeated `Bridge_Process()` calls.
8. Add the dedicated `USART2_LPUART2_IRQHandler` shown below.
9. Add `ST67_EnterMode()` and call it only after GPIO, UART, bridge, and USB initialization.
10. Rebuild and first retest USB enumeration, then test each bridge direction independently.

Remove all original echo state and echo transmission calls. After migration, `CDC_Receive_FS` must enqueue PC bytes for USART2; it must never send those bytes directly back to the PC.

For predictable operator behavior, a useful design is:

1. initialize USB and UART with ST67 disabled;
2. select manufacture or bootloader mode using a compile-time option or physical button;
3. enable ST67 immediately, without waiting for the PC CDC port to open;
4. optionally provide a hardware button or USB control command that repeats the mode-entry reset sequence.

Do not put bridge-control commands in the same byte stream unless there is an explicit escape/framing protocol. Arbitrarily recognizing text commands would make the bridge non-transparent and could corrupt bootloader data.

## Bridge Architecture

Use two single-producer/single-consumer paths:

```text
USB OUT callback -> PC-to-ST67 ring -> foreground -> USART2 TDR
USART2 RX ISR    -> ST67-to-PC ring -> foreground -> USB CDC IN
```

Recommended initial sizes:

```c
#define USB_TO_UART_RING_SIZE  512u
#define UART_TO_USB_RING_SIZE  4096u
#define USB_TX_BUFFER_SIZE     256u
```

The public interface in `bridge.h` is:

```c
#ifndef BRIDGE_H
#define BRIDGE_H

#include <stdint.h>

void Bridge_Init(void);
void Bridge_Process(void);
void Bridge_OnUsbRx(const uint8_t *data, uint32_t length);
void Bridge_OnUsbTxComplete(void);

#endif
```

Define the complete bridge state in `bridge.c`; none of it comes from another project:

```c
#include "bridge.h"

#include <stdbool.h>

#include "main.h"
#include "usbd_cdc_if.h"

extern UART_HandleTypeDef huart2;

#define USB_TO_UART_RING_SIZE  512u
#define UART_TO_USB_RING_SIZE  4096u
#define USB_TX_BUFFER_SIZE     256u

static uint8_t usb_to_uart_data[USB_TO_UART_RING_SIZE];
static volatile uint32_t usb_to_uart_head;
static volatile uint32_t usb_to_uart_tail;

static uint8_t uart_to_usb_data[UART_TO_USB_RING_SIZE];
static volatile uint32_t uart_to_usb_head;
static volatile uint32_t uart_to_usb_tail;

static uint8_t usb_tx_buffer[USB_TX_BUFFER_SIZE];
static volatile bool usb_tx_busy;

static volatile uint32_t usb_to_uart_overflow_count;
static volatile uint32_t uart_to_usb_overflow_count;
static volatile uint32_t uart_hardware_overrun_count;
```

Initialize the state and USART2 RX interrupt explicitly:

```c
void Bridge_Init(void)
{
    usb_to_uart_head = 0u;
    usb_to_uart_tail = 0u;
    uart_to_usb_head = 0u;
    uart_to_usb_tail = 0u;
    usb_tx_busy = false;
    usb_to_uart_overflow_count = 0u;
    uart_to_usb_overflow_count = 0u;
    uart_hardware_overrun_count = 0u;

    __HAL_UART_ENABLE_IT(&huart2, UART_IT_RXFNE);
    HAL_NVIC_SetPriority(USART2_LPUART2_IRQn, 1u, 0u);
    HAL_NVIC_EnableIRQ(USART2_LPUART2_IRQn);
}
```

Ring sizes must be powers of two if indexing uses a bit mask. Use monotonically increasing unsigned `head` and `tail` counters; occupancy is `head - tail`, and the storage index is `counter & (size - 1)`. A 4 KiB UART RX ring holds about 20 ms at 2 Mbaud, 8-N-1. Increase it if the host or USB stack can stall longer.

Declare indices shared with an ISR as `volatile`. On this Cortex-M0+ target, aligned 32-bit loads/stores are atomic. Preserve the single-producer/single-consumer ownership:

| Object | Producer | Consumer |
|---|---|---|
| USB-to-UART head/data | USB receive callback | foreground loop |
| USB-to-UART tail | foreground loop | foreground loop |
| UART-to-USB head/data | USART2 ISR | foreground loop |
| UART-to-USB tail | foreground loop | foreground loop |

Track overflow counters for both rings. On overflow, drop the incoming byte and increment the corresponding counter. Do not silently overwrite unread data because that destroys ordering and makes bootloader failures harder to diagnose.

## USART2 Interrupt Handler

At 2 Mbaud, byte-by-byte `HAL_UART_Receive` in the foreground loses data. The ISR must immediately drain every available FIFO byte:

```c
void USART2_LPUART2_IRQHandler(void)
{
    USART_TypeDef *uart = huart2.Instance;

    while ((uart->ISR & USART_ISR_RXNE_RXFNE) != 0u) {
        uint8_t byte = (uint8_t)(uart->RDR & 0xffu);
        uint32_t head = uart_to_usb_head;

        if ((head - uart_to_usb_tail) < UART_TO_USB_RING_SIZE) {
            uart_to_usb_data[head & (UART_TO_USB_RING_SIZE - 1u)] = byte;
            uart_to_usb_head = head + 1u;
        } else {
            ++uart_to_usb_overflow_count;
        }
    }

    if ((uart->ISR & USART_ISR_ORE) != 0u) {
        __HAL_UART_CLEAR_OREFLAG(&huart2);
        ++uart_hardware_overrun_count;
    }
}
```

Do not call the generic `HAL_UART_IRQHandler` after manually reading `RDR` unless the HAL receive state machine is deliberately in use. This bridge owns RX directly.

## USB Receive Path

The generated `CDC_Receive_FS` callback runs from USB processing context. Copy the packet immediately because the middleware reuses its receive buffer after rearming the endpoint:

```c
static int8_t CDC_Receive_FS(uint8_t *buffer, uint32_t *length)
{
    Bridge_OnUsbRx(buffer, *length);

    USBD_CDC_SetRxBuffer(&hUsbDeviceFS, buffer);
    USBD_CDC_ReceivePacket(&hUsbDeviceFS);
    return USBD_OK;
}
```

`Bridge_OnUsbRx` only appends bytes to the USB-to-UART ring. It must not block waiting for UART TX and must not retain the middleware's `buffer` pointer.

```c
void Bridge_OnUsbRx(const uint8_t *data, uint32_t length)
{
    for (uint32_t index = 0u; index < length; ++index) {
        uint32_t head = usb_to_uart_head;
        if ((head - usb_to_uart_tail) >= USB_TO_UART_RING_SIZE) {
            ++usb_to_uart_overflow_count;
            continue;
        }

        usb_to_uart_data[head & (USB_TO_UART_RING_SIZE - 1u)] = data[index];
        usb_to_uart_head = head + 1u;
    }
}
```

## UART Transmit Path

The foreground loop can initially use direct TX FIFO polling. RX remains safe because the higher-priority USART ISR can interrupt this loop:

```c
static void bridge_usb_to_uart(void)
{
    while (usb_to_uart_tail != usb_to_uart_head) {
        while ((huart2.Instance->ISR & USART_ISR_TXE_TXFNF) == 0u) {
        }

        huart2.Instance->TDR =
            usb_to_uart_data[usb_to_uart_tail & (USB_TO_UART_RING_SIZE - 1u)];
        ++usb_to_uart_tail;
    }
}
```

This is adequate for the first implementation. UART TX interrupt or DMA can be added later if foreground blocking becomes measurable.

## USB Transmit Ownership

This point is critical: the USB middleware does not copy the application TX buffer. It retains the pointer until the IN transfer completes. A buffer must not be refilled merely because `CDC_Transmit_FS` returned `USBD_OK`.

Use a persistent buffer and an explicit busy flag:

```c
static uint8_t usb_tx_buffer[USB_TX_BUFFER_SIZE];
static volatile bool usb_tx_busy;

static void bridge_uart_to_usb(void)
{
    if (usb_tx_busy || uart_to_usb_tail == uart_to_usb_head) {
        return;
    }

    uint16_t length = 0u;
    while (uart_to_usb_tail != uart_to_usb_head &&
           length < sizeof(usb_tx_buffer)) {
        usb_tx_buffer[length++] =
            uart_to_usb_data[uart_to_usb_tail & (UART_TO_USB_RING_SIZE - 1u)];
        ++uart_to_usb_tail;
    }

    usb_tx_busy = true;
    if (CDC_Transmit_FS(usb_tx_buffer, length) != USBD_OK) {
        usb_tx_busy = false;
        uart_to_usb_tail -= length;
    }
}
```

Clear the flag only from the generated transmit-complete callback:

```c
static int8_t CDC_TransmitCplt_FS(uint8_t *buffer,
                                  uint32_t *length,
                                  uint8_t endpoint)
{
    (void)buffer;
    (void)length;
    (void)endpoint;
    Bridge_OnUsbTxComplete();
    return USBD_OK;
}

void Bridge_OnUsbTxComplete(void)
{
    usb_tx_busy = false;
}
```

Before dereferencing CDC class state, harden the generated helper for startup/disconnect:

```c
uint8_t CDC_Transmit_FS(uint8_t *buffer, uint16_t length)
{
    if (hUsbDeviceFS.pClassData == NULL) {
        return USBD_BUSY;
    }

    USBD_CDC_HandleTypeDef *cdc =
        (USBD_CDC_HandleTypeDef *)hUsbDeviceFS.pClassData;
    if (cdc->TxState != 0u) {
        return USBD_BUSY;
    }

    USBD_CDC_SetTxBuffer(&hUsbDeviceFS, buffer, length);
    return USBD_CDC_TransmitPacket(&hUsbDeviceFS);
}
```

The rollback in `bridge_uart_to_usb` is safe only because that function is the sole consumer of the UART-to-USB ring. An alternative is to advance `tail` only after `CDC_Transmit_FS` accepts the transfer.

## Foreground Processing

The process function should be short and continuously callable:

```c
void Bridge_Process(void)
{
    bridge_usb_to_uart();
    bridge_uart_to_usb();
}
```

Do not call `HAL_Delay` in the normal bridge loop. Delays are acceptable only during a deliberate ST67 reset/mode-entry sequence. Avoid logging over the same CDC interface because diagnostic text would be indistinguishable from ST67 data. Expose overflow information through a debugger, LEDs, or a separate explicitly framed control interface.

## Binary Transparency Requirements

The following transformations are forbidden in both directions:

- ANSI escape removal;
- CR/LF conversion;
- null termination;
- printable-character filtering;
- command echo;
- UTF-8 or text decoding;
- packet-boundary assumptions;
- use of `strlen` on received data.

USB packets and UART reads are fragments of a byte stream. Forward exactly the received byte count, including `0x00`, `0x1b`, and bytes above `0x7f`.

## CMake Requirements

Do not replace the working CMake setup. Confirm its existing STM32CubeMX target already contains:

- startup assembly for STM32G0B1;
- `main.c`, interrupt, MSP, syscall, and system sources;
- USB application and target sources;
- USB Device Core sources;
- USB CDC class source;
- required HAL sources for GPIO, RCC, PWR, UART, PCD, and USB LL;
- CMSIS and HAL include directories;
- USB Device Core and CDC include directories;
- compile definitions `USE_HAL_DRIVER` and `STM32G0B1xx`.

It must not contain FreeRTOS sources, CMSIS-RTOS2 include paths, `app_freertos.c`, or a `FreeRTOS` object library.

A typical top-level addition is only the new source:

```cmake
target_sources(${CMAKE_PROJECT_NAME} PRIVATE
    Core/Src/bridge.c
)
```

Keep the already-working compiler, linker script, presets, and artifact generation unchanged. No new library dependency is required.

## Mode Selection Design

Represent modes explicitly even if bootloader details are initially unavailable:

```c
typedef enum {
    ST67_MODE_MANUFACTURE,
    ST67_MODE_BOOTLOADER
} St67Mode;

void ST67_EnterMode(St67Mode mode);
```

Implement manufacture mode now with the proven levels. For bootloader mode, fail at compile time or leave it unavailable until its strap/timing values are verified; do not silently reuse manufacture-mode levels.

Reasonable ways to select the mode are:

- separate CMake presets that define `ST67_DEFAULT_MODE`;
- a dedicated physical button sampled before raising `CHIP_EN`;
- two separately named firmware artifacts from the same source tree.

A compile-time selection is simplest and cannot collide with bridged payload data. Example:

```cmake
target_compile_definitions(${CMAKE_PROJECT_NAME} PRIVATE
    ST67_DEFAULT_MODE=ST67_MODE_MANUFACTURE
)
```

## Host-Side Behavior

The PC serial application's selected baud rate does not control USB CDC transfer speed. The STM32 should report ordinary line coding through the CDC control callback but keep physical USART2 fixed at the mode-specific ST67 baud unless dynamic baud changes are an intentional feature.

For manufacture mode, test first with a terminal that can open the VCP without changing payload bytes. The expected shell prompt is `qcc74x />`. A terminal can send `help` followed by CR/LF to confirm bidirectional operation.

For bootloader mode, use the vendor programming tool or protocol client. A terminal is not a meaningful validation because the protocol may be binary.

## Bring-Up and Validation Checklist

1. Build with no FreeRTOS or CMSIS-RTOS2 references.
2. Flash the dedicated firmware and confirm the CDC device enumerates with its distinct product name.
3. Confirm PA2 with an oscilloscope or logic analyzer: 2 Mbaud, 8-N-1.
4. Confirm manufacture entry levels during the rising edge of `CHIP_EN`: `CS=1`, `BOOT=0`.
5. Open the CDC port and verify the manufacture prompt/traffic is received.
6. Send `help\r\n` and verify exact byte-for-byte UART output and response forwarding.
7. Send a payload containing `00 1b 7f 80 ff` in both directions and verify no byte is filtered or changed.
8. Send sustained data at the maximum expected rate and watch all three counters: USB-to-UART overflow, UART-to-USB overflow, and UART hardware overrun. All must remain zero.
9. Disconnect USB while ST67 transmits, reconnect, and verify firmware remains responsive. Buffer overflow during a long disconnect is expected and must be counted, not deadlock the bridge.
10. Repeatedly reset or power-cycle ST67 and verify mode entry is deterministic.
11. After bootloader straps and protocol are documented, validate bootloader entry electrically before running the vendor tool.
12. Program a known image, verify it, reset into the intended post-program mode, and confirm the image boots.

## Acceptance Criteria

The project is complete when:

- it builds and links as a standalone STM32G0B1 CMake firmware without FreeRTOS;
- PC-to-ST67 and ST67-to-PC forwarding is byte-exact;
- continuous 2 Mbaud ST67 output causes no UART hardware overruns under normal connected-host operation;
- USB TX memory is not modified until transmit completion;
- manufacture mode enters reliably using the known levels;
- bootloader mode is enabled only after its pin levels, timing, UART settings, and protocol are verified from authoritative ST67 documentation;
- no application source or application debug/logging dependency is linked into the utility firmware.

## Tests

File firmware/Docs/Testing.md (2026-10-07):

# Native Tests

The firmware logic is tested by native unit tests: small C++17 executables
built with the PC's compiler and run by CTest, without a board. Each of the
three projects has its own suites; the test kit they share lives in
`firmware/Common/tests`. Code that needs hardware is tested on the bench (see
the host's [Testing.md](../HostControllerA/Docs/Testing.md#bench-tests)).

The rule that keeps most code testable is to keep decisions out of the tasks:
parsing, mapping and timing logic lives in small units that take plain values
and return plain values, and the FreeRTOS task only reads the hardware, calls
the unit and acts on the result. Where a unit still needs the HAL, the RTOS or
the log, the test links a stand-in instead of the real thing.

## Suites

| Project | Suites | What they cover |
| --- | ---: | --- |
| `Common` | 10 | The shared display code, the timeline sync, the I2C message, the address straps, `Crc32`; listed [below](#common-suites) |
| `HostControllerA` | 16 | Parser, mapper, progress bar, schedule, clock, display sync schedule, settings codec, HTTP and Wi-Fi rules, error log; see the host's [Testing.md](../HostControllerA/Docs/Testing.md#coverage-by-module) |
| `DisplayController` | 3 | `FrameAssembler` (staging of the attribute messages), the screens, the stale-data timeout |

### Common suites

| Suite | Covers |
| --- | --- |
| `numeric_display_tests` | `setFixed()`, including magnitudes below one and values that do not fit, both `setValue()` overloads, `setTime()` with the blank leading zero and the error pattern, `setTimeUnset()`, `setBlank()`, `setSegments()`, `setNoData()` and `noDataState()` |
| `display_attributes_tests` | Attribute defaults, the blink and level setters with their masks, clamping and out-of-range indices, the plane operations keeping bits 21-23 zero |
| `display_codec_tests` | Golden vectors from the wiring tables in [Display.md](Display.md#pcb-encoding): every segment of every digit on its bit, byte and slot, the indicators, the 21 matrix columns and bits 21-23, the order of the matrix rows in the frame |
| `display_passes_tests` | The pass table's invariants (sums to 100, the level percentages, the matrix's 70 %), which elements each pass and blink phase show, and that `encodePasses()` is `encodePcb()` of exactly those |
| `refresh_sequencer_tests` | Pass lengths from the table and their validation, the longest-first order, slot and frame boundaries, `peek()`, the blink phase per frame, the frame adjustment's split over the slots, renumbering the frames |
| `timeline_sync_tests` | `TimelineServo`'s rate and slew, `TimelineSync`'s jump, rate and HSITRIM decisions, `HsiTrim::allowedSteps()`, the heartbeat frame, `positionMicros()`, and a simulated board against the host's sync schedule ([TimelineSync.md](TimelineSync.md#accuracy)) |
| `display_i2c_protocol_tests` | The 36-byte layout, the round trip, masking of bits 21-23, rejection of short, long and null messages and unknown commands without touching the destination; the sync message |
| `boot_screens_tests` | The slot test and address screens and their timing, shown without disturbing the board's own state |
| `display_address_tests` | All 27 strap combinations through the stub GPIO, the pins left analog without pull, `boardAddress()` limits, `detectBoardAddress()` |
| `crc32_tests` | `Crc32` against known vectors |

Not covered natively: the refresh interrupt itself (frame starts, stamps,
`applySync()`), `Utils::microsNow()`, the HSITRIM register access, the DMA
and SPI transfers, and I2C transfer failures.

## Running the Tests

From the project's directory (`firmware/Common`, `firmware/HostControllerA` or
`firmware/DisplayController`):

```bash
export PATH="/c/Progs/msys64/ucrt64/bin:$PATH"   # MSYS2 UCRT64 compiler and its DLLs
cmake --preset NativeTests
cmake --build --preset NativeTests
ctest --test-dir build/native-tests-local --output-on-failure
```

The presets take the compiler from `C:/Progs/msys64/ucrt64` (see each
`CMakePresets.json`). Its `bin` directory must also be on `PATH`: without it
`cc1plus` cannot load its DLLs, every compile fails with `FAILED: [code=1]` and
no message, and `ctest` quietly runs the old executables.

If `ctest` is unavailable, run a suite directly, for example
`./build/native-tests-local/tests/settings_codec_tests.exe`.

### Coverage

The `NativeTests-Coverage` preset builds the same suites with `--coverage`
into `build/native-tests-coverage`. After running them, `gcovr`
(`python -m pip install gcovr`) prints line coverage, for example for the
host's `User/`:

```bash
cmake --preset NativeTests-Coverage
cmake --build --preset NativeTests-Coverage
ctest --test-dir build/native-tests-coverage
python -m gcovr -r . --filter 'User/' \
    --gcov-executable /c/Progs/msys64/ucrt64/bin/gcov.exe \
    build/native-tests-coverage --txt
```

The report lists only files that some suite compiles, so a file that no test
links does not show up as 0 %.

### Continuous Integration

`.github/workflows/firmware-native-tests.yml` builds and runs the suites of
`firmware/Common`, `firmware/HostControllerA` and `firmware/DisplayController`
with coverage on Ubuntu for every push and pull request that touches any of
them, and writes the `gcovr` summaries to the job summary. It configures CMake
directly because the presets carry Windows toolchain paths.

## Writing a Test

Each suite is one `tests/<Name>Tests.cpp` with a `main()`, registered in the
project's `tests/CMakeLists.txt`:

```cmake
add_native_test(<name>
    SOURCES <Name>Tests.cpp
    SUT User/Src/<path to the code under test>.cpp
    [STUBS]
    [FAKE_LOG]
)
```

- `SUT` paths are relative to the project root; shared sources are reached as
  `../Common/Src/...`. `../Common/Inc`, `User/Inc` and `../Common/tests/support`
  are always on the include path.
- `STUBS` adds `../Common/tests/stubs` and the project's `Core/Inc`, so the
  real `main.h` compiles against a stand-in HAL, and links the stub
  implementations. Common's own suites compile against
  `Common/tests/board/main.h`, a stand-in with the pin labels both boards
  define.
- `FAKE_LOG` links the host's recording `LogService` fake (see the host's
  [Testing.md](../HostControllerA/Docs/Testing.md#log-fake)) and implies
  `STUBS`.

`add_native_test()` is defined once, in `Common/tests/NativeTest.cmake`; each
`tests/CMakeLists.txt` sets the project root, include and `main.h` directories
before including it.

### Assertions

`Common/tests/support/Expect.hpp` provides:

| Helper | Use |
| --- | --- |
| `Test::expect(condition, "case")` | Boolean check |
| `Test::expectEqual(actual, expected, "case")` | Equality; prints both values on failure (enums and bytes as numbers) |
| `Test::fail("case")` | Record a failure from a custom helper |
| `Test::finish("suite")` | Return from `main()`: exit code 1 if anything failed |

A failed check is counted and the suite carries on, so one run reports every
failing case.

### Stubs

`Common/tests/stubs/` holds stand-ins for `stm32g0xx_hal.h`, `cmsis_os2.h`,
`FreeRTOS.h`, `queue.h` and `task.h`. Nothing is scheduled: threads are never
created and mutexes always succeed. `StubHal.hpp` steers them from a test:

| Function | Effect |
| --- | --- |
| `Stub::reset()` | Clock to 0, all pins floating inputs |
| `Stub::setTick(ms)`, `Stub::advanceTick(ms)` | Fake clock behind `HAL_GetTick()` and `osKernelGetTickCount()`; `osDelay()` and `HAL_Delay()` advance it |
| `Stub::setStrap(port, pin, Strap::Low / High / Floating)` | What an input pin reads; a floating pin follows the pull set by `HAL_GPIO_Init()` |
| `Stub::outputState(port, pin)`, `Stub::configuredPull(port, pin)` | Inspect what the code did to a pin |

Add HAL declarations to the stub as code under test needs them, with the same
names and values as the real HAL. The host's `test_support_tests` suite checks
the stubs and the log fake themselves.

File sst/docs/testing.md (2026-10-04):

# Testing Approach

## Tech Stack

| Concern | Tool |
|---|---|
| Test runner | [Vitest](https://vitest.dev/) v4 |
| Language | TypeScript (native ESM, no transpilation step) |
| Mocking | Dependency injection first; Vitest built-ins (`vi.fn`, `vi.mock`) where needed |
| Web components | React Testing Library with jsdom |

Vitest was chosen because it supports native ESM and TypeScript out of the box, shares the same API surface as Jest, and integrates well with a monorepo project structure through its **projects** feature.

## Vitest Projects

`vitest.config.ts` declares three named projects. The `--project` flag selects which suite to run:

| npm script | Vitest project | Include pattern | Target environment |
|---|---|---|---|
| `npm run test` / `npm run test:unit` | `unit` | `packages/**/src/**/*.test.ts` | Node, no network or AWS |
| `npm run test:integration` | `integration` | `packages/**/tests/integration/**/*.test.ts` | A deployed or `sst dev` stage, through `sst shell` |
| `npm run test:web` | `web` | `packages/web/src/**/*.test.tsx` | jsdom |
| `npm run test:all` | _(all)_ | all patterns above | — |

`test:all` includes the integration project, so it needs the same SST
credentials and stage as `test:integration`.

## Unit Tests

Unit tests exercise individual functions and modules in isolation. They are
co-located with source files as `*.test.ts`. Plain `.test.ts` files under
`packages/web/src` (for example `time.test.ts`) also run in the `unit` project.

```bash
npm run test
```

Current coverage:

| Test file | Covers |
|---|---|
| `forecast/nights.test.ts` | Local-noon boundary, six consecutive nights, 21 slots, DST transitions |
| `forecast/assemble.test.ts` | Six displays and independent astronomy/weather degradation |
| `forecast/protocol.test.ts` | Serialized record order, `time` header format, and error payloads |
| `astro.test.ts` | Forecast handler: local `time` header (including after DST ends), status, content type, `404` error |
| `configurations-handler.test.ts` | `GET /configurations` response |
| `clearoutside.test.ts` | `POST /tools/clearoutside` handler |
| `weather/clearoutside.test.ts` | HTML parser against a saved fixture; fetch timeout and retry behavior |
| `weather/clearoutside-storage.test.ts` | DynamoDB keys, metadata, and `expireAt` calculation |
| `jobs/clearoutside-weather.test.ts` | Scheduled ingestion: sequential locations, failure isolation, final failure signal |
| `aurora/spans.test.ts` | Night grouping: spans keep their boundaries and join every local night they overlap |
| `aurora/gfz-hp60.test.ts`, `aurora/noaa-kp.test.ts`, `aurora/noaa-outlook.test.ts` | Source parsers against saved fixtures in `aurora/__fixtures__/`; fail-closed checks |
| `aurora/ovation.test.ts` | Grid-cell lookup, including western longitudes on the 0..359 grid |
| `aurora/fetch.test.ts` | Source fetch: last-modified header, retry on server failure only |
| `aurora/levels.test.ts` | Kp → level around `kpMain`, nowcast thresholds, ensemble band sums, storm-night triggers |
| `aurora/merge.test.ts` | Source cascade (GFZ, NOAA 3-day, 27-day), a night split at the UTC day boundary, GFZ freshness, past hours from observed bins, the nowcast raising and blinking slots |
| `aurora/noaa-live.test.ts` | Live Kp: the 30-minute maximum, malformed rows, an empty feed |
| `jobs/aurora-jobs.test.ts` | Aurora ingestion: per-night items, one failed source, a sticky flag, the per-run source and outlook lines; nowcast: flag, darkness and live-Kp gates, a live-Kp flag, slot targeting, hour maximum, calibration log and kept samples |
| `tools/handler.test.ts` | `POST /tools/<source>` factory: configuration or coordinates plus timezone, night grouping, `502` on source failure |

The forecast weather reader (`forecast/weather-reader.ts`) and astronomy
projection (`forecast/astronomy.ts`) have no dedicated unit tests yet. Astronomy is exercised indirectly through `assemble.test.ts`.

Run a focused subset by passing paths:

```bash
npx vitest run --project unit packages/functions/src/forecast
```

### Writing unit tests

Modules take their external dependencies as parameters, so most tests pass
plain fakes instead of mocking modules. The forecast assembler receives the
clock, weather reader, and logger:

```typescript
import { describe, expect, test, vi } from "vitest";
import { assembleForecast } from "./assemble";

describe("assembleForecast", () => {
  test("keeps six displays and available astronomy when weather fails", async () => {
    const result = await assembleForecast("krakow", { lat: 50, lon: 20, tz: "Europe/Warsaw" }, {
      now: () => new Date("2026-09-17T10:00:00Z"),
      readWeather: vi.fn().mockRejectedValue(new Error("Dynamo unavailable")),
      log: vi.fn()
    });

    expect(result).toHaveLength(6);
    expect(result[0].cloud).toBe("?");
  });
});
```

The same pattern applies to the other injectable entry points:

- `createHandler({ now, readWeather, log })` in `astro.ts`;
- `createWeatherReader(tableName, client)` and `createClearOutsideStore(tableName, client)`,
  which accept a DynamoDB document client;
- `ingestClearOutside({ configurations, fetchHtml, parse, store, now, waitBetweenLocations, log })`.

Astronomy tests run the real `suncalc` library, which is deterministic for an
injected time. Use `vi.mock` only for modules that are imported directly and
have no injection point, as `clearoutside.test.ts` does for the scraper.

## Integration Tests

Integration tests call a deployed API over HTTP. They live in
`packages/<pkg>/tests/integration/` rather than next to the source.

`npm run test:integration` wraps Vitest in `sst shell`, which makes the stage's
linked resources available. `globalSetup.ts` reads `Resource.AstroApi.url`, the
custom-domain API URL of the selected stage, prints it, and hands it to the
test files through Vitest's `provide`/`inject`. Test files must use
`inject("apiUrl")` rather than `Resource`: on Windows, Vitest workers receive
environment variable names upper-cased, which hides the SST links from
`Resource` inside the worker.

`sst shell` selects the stage from `SST_STAGE`, so deploy the stage first (see
[development.md](development.md)) and then run:

```bash
# Your personal stage, deployed or running under `sst dev`
npm run test:integration

# A named stage
SST_STAGE=int npm run test:integration
```

The suite covers:

- `GET /device/astro/krakow` with the stage's device key (the first entry of
  `DeviceApiKey`, read in `globalSetup.ts`) returns `200`, `text/plain`,
  protocol 3, a `time` header within the Krakow UTC offset of the test
  machine's clock, and six well-formed display blocks;
- an unknown configuration returns `404` with the versioned error body;
- a missing path parameter is not `200`;
- the device route answers `401` without a key and `403` with a wrong one;
- the web UI's routes (`/configurations`, `/astro/krakow`) answer `401`
  without a token and with one that is not a JWT. The suite has no Cognito
  user, so the signed-in path is checked by hand in the web UI.

Requests that hit the stage's one-request-per-second throttle (`429`) are
retried a few times.

The tests call the public API hostname over HTTPS, so they exercise its
certificate too. They do not check that plain HTTP is refused. After
infrastructure changes, check the hostname by hand:

```bash
curl -si "https://api.<stage>.astroweather.albedoonline.com/device/astro/krakow?key=<key>"
curl -si --max-time 10 http://api.<stage>.astroweather.albedoonline.com/configurations
```

The first should return the API response. The second should fail to connect
(time out or be refused): the API is HTTPS only.

### Live Clear Outside scrape

`clearoutside.integration.test.ts` fetches and parses the real Clear Outside
page for Wrocław and prints three nights of hourly data. It is skipped unless
`RUN_LIVE_SCRAPE=1`, which the dedicated script sets:

```bash
npm run test:clearoutside
```

Use it to check whether a Clear Outside page change has broken the parser.

## Web Tests

The web project uses React Testing Library with jsdom. API requests are stubbed
with Vitest, so component tests do not require SST or a running API:

```bash
npm run test:web
```

## Scheduled Clearoutside Ingestion

The scheduled writer is unit-tested without AWS or network access (see above).
The deployed `ClearOutsideIngestion` schedule runs every six hours without
scheduler retries. For a manual staging check, identify the generated Lambda
from the SST deployment output or AWS Console, invoke it with `{}`, and inspect
CloudWatch for one structured success or failure record per configuration
followed by the completion summary.

The table name is returned as the `forecastDataTableName` stack output. Query
one location with:

```bash
aws dynamodb query \
  --table-name <forecastDataTableName> \
  --key-condition-expression "pk = :pk" \
  --expression-attribute-values '{":pk":{"S":"LOC#krakow"}}'
```

Verify that returned items use the `NIGHT#<nightId>#WEATHER` sort-key
format, contain numeric `expireAt` values and normalized `hours`, and contain no
raw HTML. A failed scrape should leave the previous item unchanged.

## CI Usage

| Pipeline stage | Command | Notes |
|---|---|---|
| Pull Request | `npm run test` and `npm run test:web` | No AWS or network access required |
| Post-deploy | `SST_STAGE=<stage> npm run test:integration` | After `npm run deploy -- --stage <stage>`; needs AWS credentials that can read the stage's SST resources |

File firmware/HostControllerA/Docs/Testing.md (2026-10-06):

# Testing

The host's native suites and what they cover, the log fake, the bench tests
and the behaviour the tests pin. How to run and write native tests, the shared
stubs and assertions, and the shared code's suites are in the firmware-wide
[Native Tests](../../Docs/Testing.md).

## Coverage by Module

Line coverage measured with the `NativeTests-Coverage` preset on 2026-09-23:
95% over the 24 files the suites then compiled (983 lines). The suites for the
shared code (`NumericDisplay`, `DisplayCodec`, `DisplayI2cProtocol`,
`DisplayAddress`, `Crc32` and the rest) are in `../Common/tests`; see the shared
[Native Tests](../../Docs/Testing.md#common-suites). The others are in `tests/`;
`error_log_tests` and `sync_schedule_tests` are not in the figure.

| Module | Suite | Line coverage |
| --- | --- | --- |
| Test infrastructure (stubs, log fake) | `test_support_tests` | — |
| `NumericDisplay` (`DisplayTypes`) | `numeric_display_tests` | 97% |
| `DisplayCodec` | `display_codec_tests` | 100% |
| `DisplayI2cProtocol` | `display_i2c_protocol_tests` | 100% |
| `DisplayAddress` | `display_address_tests` | 100% |
| `CurrentSenseConversion` | `current_sense_conversion_tests` | 100% |
| `CalendarDate` | `calendar_date_tests` | 100% |
| `RtcTrim` | `rtc_trim_tests` | 100% |
| `ClockSync` | `clock_sync_tests` | 100% |
| `SyncSchedule` (display timeline sync) | `sync_schedule_tests` | not measured |
| `RefreshSchedule` | `refresh_schedule_tests` | 95% |
| `AstroDataParser` | `astro_data_parser_tests` | 96% |
| `AstroDisplayMapper` | `astro_display_mapper_tests` | 100% |
| `AstroProgressBar` | `astro_progress_bar_tests` | 98% |
| `Crc32` | `crc32_tests` | 100% |
| `SettingsCodec` | `settings_codec_tests` | 89% |
| `HttpResponseParser` | `http_response_parser_tests` | 100% |
| `St67HttpRules` | `st67_http_rules_tests` | 100% |
| `St67ConnectDiagnosis` | `st67_connect_diagnosis_tests` | 100% |
| `St67FetchStatusMap` | `st67_fetch_status_map_tests` | 100% |
| `ErrorLog` | `error_log_tests` | not measured |
| `SettingsStore`, `Eeprom24AA04` | — | Not covered |
| `BufferedDisplayBoard` | — | Not covered |
| Console commands, `ConsoleService` line assembly | — | Not covered |
| `AstroDataRefreshTask` run loop, `HttpClient` socket loop | — | Only through the extracted units |
| `LogService`, `PcbDisplayBoard`, `DisplaySyncTask`, `ClockTask` RTC access, Wi-Fi session | — | Bench only |

## Not Covered Yet

- `Settings::Store` and the `Eeprom24AA04` driver: page splitting, write-cycle
  polling, writing only changed pages, a read failure reported as `ReadFailed`.
- `BufferedDisplayBoard`: retries, online/offline logging.
- The console: `ConsoleService` line assembly (CR/LF, the 127-character limit,
  the 8-deep queue) and each command group's `OK`/`ERR` replies.
- The `AstroDataRefreshTask` run loop and the `HttpClient` socket loop, reached
  only through their extracted units.
- `WifiConnectResult` and `St67FetchStatus` still sit in headers that include
  `cmsis_os2.h`, so their suites need `STUBS`.

## Log Fake

`tests/fakes/FakeLogService.cpp` implements the `LogService` API and records
each `log()`, `logf()` and `sendLine()` call synchronously, without the uptime
prefix, the queue or USB. `FakeLog::lines()`, `FakeLog::contains()`,
`FakeLog::clear()` and `FakeLog::dump()` read it back. This is what lets
console commands and task code link in a test.

## Bench Tests

Not worth unit testing: the real Wi-Fi session, `LogService` over USB,
`PcbDisplayBoard` multiplexing timing and RTC register access. A scripted
smoke test on `tools/astro_console.py capture` (boot, `status`,
`astro refresh`, check the success lines) and the ADC known-voltage test from
the [hardware review](../../../KiCad/Docs/Hardware_Review.md) cover them.

**HTTPS certificate cases** need no test
server and no module reflash. Build with
`cmake --preset Debug -DAPP_ST67_TLS_BENCH_ANCHOR_ISRG=ON` so the anchor is
ISRG Root X1, flash, and in one console session (`tools/console_capture.ps1`)
run `astro refresh` against, in turn, the production host (wrong CA),
`sha256.badssl.com` or `rsa2048.badssl.com` (positive control, expect
`http=200`), `wrong.host.badssl.com` (hostname mismatch),
`untrusted-root.badssl.com`, `self-signed.badssl.com` and
`ecc256.badssl.com` (other root); set each with `api host <name>` and
`api path /`, finish with `api default`. A refused handshake logs
`ST67 https failed: connect ...`; a completed one logs the HTTP status. Then
reconfigure with `=OFF` and rebuild before flashing a production image; the
fetch log line's `ca=` names the anchor in use.

## Known Issues Pinned by Tests

Behaviour the tests record as it is today, to be decided separately. Each
test that pins one says "current behaviour".

**HTTP response** (`http_response_parser_tests`, `st67_http_rules_tests`):

- Header names are matched case-sensitively (`Content-Length`,
  `Content-Type`), although HTTP header names are case-insensitive.
- Header lines must end in CRLF; bare-LF headers never terminate.
- Chunked `Transfer-Encoding` is not decoded: chunk markers are passed on as
  body, and only the server closing the connection ends it.
- `Content-Length` accepts a leading `+`, rejects a trailing space, and takes
  the last of duplicate headers.
- Body bytes that arrive in the same read as the blank line count against the
  2048-byte header buffer.
- The `Content-Type` check is a prefix search anywhere in the headers: extra
  parameters pass, case and spacing must match exactly, and a header such as
  `X-Content-Type:` can match first.

**Fetch status** (`st67_fetch_status_map_tests`):

- Failures at module-info, callback-register, disconnect and other stages all
  report `HttpFailure`; w6x-init, wifi-init and net-init report
  `DriverFailure`.
- A `Content-Length` over 4096 reports `HttpFailure`, not `ResponseTooLarge`:
  the response is refused before the body callback that sets the flag.
- `CleanupFailure` cannot happen for a client fetch.

**Wi-Fi diagnosis** (`st67_connect_diagnosis_tests`): reason code 0 on a
failed connect classifies as `Failed`.

**Payload parser** (`astro_data_parser_tests`): a payload cut in the middle of
a line parses that partial line as complete, so the error is the record's own
(`InvalidMatrix`, `InvalidTemperature`) rather than `Truncated`; the
`Truncated` check for that case in `AstroDataParser.cpp` is unreachable.

**Progress bar** (`astro_progress_bar_tests`): a processing failure blinks the
full bar, the same pattern as success; the blink phase follows the tick and
jumps at the 32-bit wrap.

**Numeric display** (`numeric_display_tests`): every negative value at
precision 3 needs five positions and shows the error pattern. The console's
`display show` accepts up to four digits before the point and three after
(at most 32767 as an integer), so it also takes values such as `-1.234` or
`123.45` that need five positions, and the board shows the error pattern.

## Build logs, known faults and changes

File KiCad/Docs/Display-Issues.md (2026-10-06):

# Display Issues

Hardware problems found on the LED displays, with what has been measured, the
likely causes and what is still to check. The design-level issues are in
[Hardware_Review.md](Hardware_Review.md); this page collects
what shows on the displays.

| Issue | Board | Status |
| --- | --- | --- |
| [Matrix column faults around `U505`](#matrix-column-faults-around-u505) | Prototype host board | Open: column 1 stays lit |
| [Off digits and matrix rows can glow](#other-known-issues) | Every board | Not seen on the prototype; next PCB revision |
| [Random contents at power-up](#other-known-issues) | Host board | Fixed on the display boards; host firmware fix open |

## Matrix Column Faults Around `U505`

Faults on the prototype host board's dot matrix, all traced to the area around
`U505`, the SCT2024 that drives matrix columns 1 to 16. Status on 2026-10-01:
**open**. Column 1 stays lit and its brightness sometimes changes.

### What Has Been Seen

| When | Symptom | Finding |
| --- | --- | --- |
| Before 2026-10-01 | Column 16 very bright and lit all the time | A short between `U505` pad 20 (`Out15`, column 16) and pad 21 (`~SCT_EN`, OE/). Removed; column 16 has worked since. |
| 2026-10-01 | Column 1 lit from boot | Power off, in circuit: **200 Ω between `U505` pads 4 and 5**, 2 MΩ between pads 5 and 6. |
| 2026-10-01, during rework of pads 3–6 | Only numeric displays 1 and 2 worked. The rest of the matrix and numeric displays 3 and 4 were dark; column 1 was dark at first and lit a few seconds later | Recovered by itself moments later, with every display working. |
| 2026-10-01, after that | Column 1 lit again, its brightness sometimes changes | Not measured again yet. |

The console was unavailable during these observations (the USB port problem then, see
[Development.md](../../firmware/Docs/Development.md#com-port-troubleshooting)), so
none of the checks with `display` commands below have been run yet.

### How the Drivers Are Wired

The four LED drivers form one shift-register chain. Clock (`SCT_CLK_F`), latch
(`~SCT_LA`, PB6) and output enable (`~SCT_EN`, PB7) are shared by all four:

| Order | Driver | Drives | Data in | Data out |
| --- | --- | --- | --- | --- |
| 1 | `U501` SCT2024 | numeric displays 1 and 2 | `SCT_SDI` from the MCU | `SCT1_SDO` |
| 2 | `U505` SCT2024 | matrix columns 1–16 (`DIS3_1`…`DIS3_16`) | `SCT1_SDO` | `SCT2_SDO` |
| 3 | `U510` SCT2167 | matrix columns 17–21 | `SCT2_SDO` | `SCT3_SDO` |
| 4 | `U513` SCT2024 | numeric displays 3 and 4 | `SCT3_SDO` | `SCT_SDO` (not connected) |

`U505` sits on the bottom side (`B.Cu`) at (101, 54.2), rotated −90°.
Coordinates in this document are KiCad PCB editor millimetres. Its SSOP-24
pads, at 0.635 mm pitch:

| Pad | Net | Pad | Net |
| --- | --- | --- | --- |
| 1 | `GND` | 24 | `SCT2_VDD` (from `+3.3V` through `R505`, 10 Ω) |
| 2 | `SCT1_SDO` (data in) | 23 | `SCT2_REXT` (sets the output current) |
| 3 | `SCT_CLK_F` | 22 | `SCT2_SDO` (data out) |
| 4 | `~SCT_LA` | 21 | `~SCT_EN` |
| 5 | `DIS3_1` (column 1) | 20 | `DIS3_16` (column 16) |
| 6–19 | `DIS3_2`…`DIS3_15` | | |

Column 1 is the first output, next to the latch pin, just as column 16 is the
last output, next to the output-enable pin.

### What the Symptoms Point To

**Column 1 always lit.** The SCT outputs are LED cathode sinks. The latch
line sits low between its short pulses, which is almost all the time, so a
leak from column 1 to it holds the column's cathodes low whatever the data
says. Through 200 Ω that is roughly (3.7 V − about 2 V LED drop) / 200 Ω ≈
8 mA in every row slot. The SCT gives a full-brightness pixel about the same
(3.7–7.5 mA peak by the estimate in
[Hardware_Review.md](Hardware_Review.md)), so the column lights
at full brightness, in all five rows, as soon as the board multiplexes. The
current is not regulated by the SCT and flows through PB6. A leak whose
resistance changes, with temperature or humidity for example, would explain
the changing brightness.

**The temporary blackout.** `U501` kept working, so the shared clock, latch
and enable lines, the MCU and the firmware were all fine. Everything from
`U505` onward went dark, so `U505` stopped shifting or passing on data: a
fault on its data input, its own clock joint, its supply, or the chip itself.
It cleared by itself, which points to something temporary, such as
contamination that dried or a joint that makes contact only some of the time,
rather than a broken part.

### Candidate Spots

The gaps are the smallest edge-to-edge distances between copper of different
nets on the same layer: pads, tracks and vias, computed from
`KiCad/AstroWeather.kicad_pcb`.

#### Column 1 leak and changing brightness

| # | Where | Gap | Notes |
| --- | --- | --- | --- |
| 1 | `U505` pads 4 and 5 | 0.235 mm | Where the 200 Ω was measured. A solder whisker or flux residue. |
| 2 | **Under `U505`'s body, near (99.5, 54.3)** | 0.27 mm | The column 1 track runs alongside the latch track underneath the chip. Flux from two reworks can stay trapped there, where a brush cannot reach and nothing can be seen, and its resistance changes with temperature and humidity. The leading suspect for a leak that survives cleaning and varies. |
| 3 | `U505` itself | – | One output can be left leaky by the earlier OE/ short, when that pin sank unregulated current, or by rework heat. |

Column 1 is also 0.235 mm from column 2 at pads 5 and 6, and their tracks run
0.27 mm apart near (101.2, 55.6). A leak there would make the two columns
show the same pattern; 2 MΩ was measured, so it is not one now.

#### Chain break at `U505`

| # | Where | Gap | Notes |
| --- | --- | --- | --- |
| 4 | `U505` pads 1–3 | 0.235 mm | The data input (pad 2) sits between GND (pad 1) and the clock (pad 3). A leak or bridge to either, or a cracked joint on pad 2 or 3, stops `U505` shifting, so `U505`, `U510` and `U513` go dark together. Next to where the rework was done. |
| 5 | `U505` supply: pad 24 and `R505` near (94.5, 55.6) | 0.235 mm to pad 23 | An open joint on pad 24 or `R505` stops `U505` altogether. A leak from pad 24 to pad 23 (`REXT`) would change the brightness of all 16 columns, not only column 1. |
| 6 | The data line from `U501` pad 22 to `U505`, near (61.9, 57.0) | 0.22 mm to GND vias | Also breaks the chain at `U505` while `U501` works. Unlikely, as it is away from the rework. |

#### Not matching this event, for future reference

| # | Where | Gap | Notes |
| --- | --- | --- | --- |
| 7 | The data line from `U505` pad 22 to `U510`, near (97.6, 60.0) | 0.20 mm to a clock via; 0.23 mm to GND and OE vias | The tightest gap found. A fault here would darken only columns 17–21 and numeric displays 3 and 4, with columns 1–16 working. |
| 8 | The shared clock, latch and enable lines | – | Ruled out for the blackout, since `U501` kept working on the same lines. |

### Checks Still To Do

With the board running, once the console works:

- `display clear`: if column 1 still glows with everything off, it is the
  leak. If it goes dark, part of the changing brightness was real data:
  column 1 is the first hour of the sun row, whose level changes through the
  evening.
- `display test`: every column and all four numeric displays should light.

With the power off:

- Reverse the meter leads on pads 4–5. A reading that is the same in both
  directions is resistive, such as solder or contamination; one that changes
  with polarity goes through silicon, which points to the chip.
- Measure pads 4–5 of `U501` or `U513` for reference. Pad 4 is the same latch
  net there. Megohms would confirm that `U505`'s 200 Ω is a defect, not an
  in-circuit path.
- Inspect pads 1–5 and 20–24 under magnification for lifted leads, dull joints
  and bridges.

### Recommended Repair

Remove `U505` with hot air. Clean its pads and the board under it, especially
around (99.5, 54.3), and look for residue and solder balls. Then measure pad 4
to pad 5 with the chip off:

- **Still low:** the leak is in the board (spots 1 and 2). Clean further, or
  cut and re-route the track.
- **Megohms:** the old chip was leaking.

Fit a new SCT2024 either way. The old one has been reworked twice and had an
output shorted to OE/. Clean the area with IPA and let it dry fully before
power is applied: residue that is still wet conducts, which may explain the
temporary blackout.

## Other Known Issues

Both are described in full in
[Hardware_Review.md](Hardware_Review.md).

- **Off digits and matrix rows can glow (H-3).** The slot P-FETs (`Q501`–`Q505`)
  cannot be fully turned off: their gates are driven from 3.3 V while their
  sources sit at about 3.7 V. A FET with a low threshold conducts enough to
  make "off" digits and rows glow. No glow was visible on the prototype host
  board on 2026-09-24; the fix is planned for the next PCB revision.
- **Random contents at power-up (L-3).** On the host, `MX_GPIO_Init` enables
  the SCT outputs (`SCT_ENABLE`, PB7, low) before any data has been latched,
  which can briefly show whatever the drivers hold. The DisplayController
  already starts PB7 high (blanked) and enables the outputs after the first
  frame is prepared; the host needs the same initial level in its CubeMX
  configuration.

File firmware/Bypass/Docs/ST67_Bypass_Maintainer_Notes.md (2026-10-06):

# ST67 Bypass - Maintainer Notes

Internal reference for anyone extending, fixing, or re-validating this
project. User-facing build/usage instructions are in the root
[README.md](../README.md). The original design rationale and staged
validation plan ([ST67_Bootloader_Mode_Implementation_Plan.md](archive/ST67_Bootloader_Mode_Implementation_Plan.md))
and bring-up guide ([ST67_Bypass_Bootloader_Project_Guide.md](archive/ST67_Bypass_Bootloader_Project_Guide.md))
are archived; where they disagree with this document (bootloader straps "not
yet specified", STM32G0B1 references), this document is right.

## Source layout

- `Core/Src/main.c` - CubeMX-generated startup; only the `USER CODE` blocks
  call into project code (`Bridge_Init`, `ST67_EnterMode`, `Bridge_Process`).
  Required init order: GPIO (with `CHIP_EN` low) -> USART2 -> `Bridge_Init`
  -> USB device init -> `ST67_EnterMode` -> foreground `Bridge_Process` loop.
- `User/Src/bridge.c` / `User/Inc/bridge.h` - the transport. Two
  single-producer/single-consumer ring buffers (USB->UART, UART->USB),
  ISR-driven UART RX, deferred (foreground-only) ST67 reset on a CDC DTR
  rising edge, and the two status LEDs. Sizes are in
  `User/Inc/bridge_config.h` (`USB_TO_UART_RING_SIZE`, `UART_TO_USB_RING_SIZE`,
  `USB_TX_BUFFER_SIZE`) - must stay powers of two, ring indexing uses bit
  masks.
- `User/Src/st67_mode.c` / `User/Inc/st67_mode.h` - owns GPIO strap levels and
  reset timing only (`CHIP_EN`, `CS`, `BOOT`). Never touches USART2/USB/ring
  state. `bridge.c` only asks it to re-enter the configured mode.
- `USB_Device/App/usbd_desc.c` - USB identity string
  (`USBD_PRODUCT_STRING = "AstroWeather ST67 Bypass"`), used to find the
  right COM port without guessing.
- `tools/` - host-side scripts (see below).

## Mode selection

`ST67_DEFAULT_MODE` is a compile-time macro (`ST67_DEFAULT_MODE_MANUFACTURE`
or `ST67_DEFAULT_MODE_BOOTLOADER`), set from the CMake cache variable
`ST67_DEFAULT_MODE` (`MANUFACTURE`/`BOOTLOADER`) in `CMakeLists.txt`, wired to
four `CMakePresets.json` presets. Any other value fails the build via a
`#error` in `st67_mode.h` and a `FATAL_ERROR` in `CMakeLists.txt` - this is
intentional, verified by configuring with a bogus value.

Preprocessor `#if` cannot compare C enum identifiers, which is why the header
keeps separate numeric `ST67_DEFAULT_MODE_*` macros alongside the `St67Mode`
enum used at runtime.

## Reset/session-boundary handling

`Bridge_OnHostConnectionChanged` sets a pending-reset flag only on a
false->true DTR transition; the actual `HAL_Delay`-heavy `ST67_EnterMode`
call always runs from `Bridge_Process` (foreground), never from the USB
interrupt. Before re-entering the configured mode, `bridge_reset_transport_state`:

- waits up to `USB_TX_DRAIN_TIMEOUT_MS` (50 ms) for an already-submitted USB
  IN transfer to finish, so a stale packet doesn't linger into a new host
  session (counted via `usb_tx_stale_flush_count` if the timeout is hit);
- flushes both software rings;
- drains any pending USART RX data register content;
- clears UART framing/noise/parity/overrun flags.

Diagnostic counters (all file-local `static volatile` in `bridge.c`,
inspectable via debugger - intentionally not exposed through the CDC stream):
`usb_to_uart_overflow_count`, `uart_to_usb_overflow_count`,
`uart_hardware_overrun_count`, `uart_framing_error_count`,
`uart_noise_error_count`, `uart_parity_error_count`, `usb_tx_failure_count`,
`usb_tx_stale_flush_count`, `st67_session_reset_count`. Check them with a
debugger after any transport stress test.

**`usb_tx_failure_count` is not a data-loss indicator and does not need to be
zero.** `bridge_uart_to_usb` only advances `uart_to_usb_tail` (i.e. discards
bytes from the ring) after `CDC_Transmit_FS` returns `USBD_OK`; on failure it
just resets `usb_tx_busy` and retries the same bytes next loop iteration.
Confirmed 2026-08-19: a full 4 MiB debugger-instrumented read logged
`usb_tx_failure_count = 1131` and `uart_framing_error_count = 1`, yet
re-hashing that exact dump (boot2, partition table, and the active FW slot)
matched the vendor files byte-for-byte. The counters that actually indicate
lost/corrupted bytes are the ring overflow counters
(`usb_to_uart_overflow_count`, `uart_to_usb_overflow_count`) and the
hardware UART error counters (`uart_hardware_overrun_count`,
`uart_framing_error_count`, `uart_noise_error_count`,
`uart_parity_error_count`) - those should be 0, or if not, the dump they
came from should be independently re-hashed against a known-good image
before trusting it, since a SHA-256 match is stronger evidence than a clean
counter reading.

## LED semantics

`LED_1` (`PC13`) = TX-to-ST67 activity, `LED_2` (`PB9`) = RX-from-ST67
activity, both stretched to a minimum 60 ms on-time
(`LED_MIN_ON_MS`) so short bursts stay visible. CubeMX initializes `LED_1`
high (on) at boot; `bridge_update_tx_led` deliberately leaves it alone
(`tx_led_activity_seen` guard) until the first real byte is forwarded, so it
reads as "alive at boot" instead of being immediately clobbered by a stale
recent-activity timestamp during the multi-hundred-ms `ST67_EnterMode` delay
that runs before the foreground loop starts.

## Build toolchain on a machine without it on PATH

This dev machine has no `cmake`/`ninja`/`arm-none-eabi-gcc` on `PATH` by
default, but STM32CubeIDE bundles all three. Example (adjust the version
folder name):

```bash
export PATH="/c/Program Files/ST/STM32CubeIDE_2.2.0/STM32CubeIDE/plugins/com.st.stm32cube.ide.mcu.externaltools.gnu-tools-for-stm32.14.3.rel1.win32_1.0.100.202602081740/tools/bin:/c/Program Files/ST/STM32CubeIDE_2.2.0/STM32CubeIDE/plugins/com.st.stm32cube.ide.mcu.externaltools.cmake.win32_1.1.200.202605190741/tools/bin:/c/Program Files/ST/STM32CubeIDE_2.2.0/STM32CubeIDE/plugins/com.st.stm32cube.ide.mcu.externaltools.ninja.win32_1.1.200.202606260906/tools/bin:$PATH"
```

All four presets have been built clean with this toolchain with no warnings
in project-owned files.

## Host tooling (`tools/`)

- `Program-ST67.sh` / `Program-ST67.ps1` - the real programming path, wraps
  `QConn_Flash/QConn_Flash_Cmd.exe`. Validates the SDK root, exactly one
  matching QConn executable, the flash config template and every image it
  references, the selected/newest firmware version, and the efuse image,
  before generating a temporary absolute-path config and invoking QConn.
  Requires `--force` to actually run QConn; otherwise prints the lock-risk
  warning and exits 1. Propagates QConn's exact exit code on failure, and
  also treats a `Parse para error`/`ErrorCode:`/Python traceback in QConn's
  own output as a failure even when it exits 0 (it does, for some error
  paths). The bash version writes native Windows paths (`cygpath -w`) into
  the generated ini - QConn is a native Windows program that reads that
  file itself, so MSYS's argv path translation never applies to paths
  embedded inside it; a raw `/d/...` path gets misread as "root of current
  drive, folder literally named d".
- `Query-ST67.sh` - non-destructive efuse/chip-info read via
  `NCP_info/QConn_Eflash.exe -r --efuse --start=0x0 --end=0x1ff` +
  `read_chip_info`. Never needs `--force`. This is the right first check
  before ever running `Program-ST67.sh --force`.
- `Dump-ST67-Flash.sh` - bulk flash read-back for manual inspection. It uses
  `QConn_Flash_Cmd.exe --read`, which does not enforce the strict flash-type
  match applied by `QConn_Eflash.exe -r --flash`; it logs "flash config Not
  found, use default" and proceeds across boards with different flash chips.
- All scripts validate `--port` before touching the SDK (checked against
  `[System.IO.Ports.SerialPort]::GetPortNames()` on Windows, or file
  existence on Linux) and clean up any generated temp files in a
  `trap ... EXIT`.

### Vendor tool gotchas (learned the hard way)

- `QConn_Eflash.exe -a`/`--auto` means **"auto burn"** - an autonomous
  erase+program+verify cycle - not "auto-detect flash parameters for a
  read". Passing it with a read-only request causes an infinite
  connect/handshake/fail/restart loop (confirmed live: it never gives up on
  its own). Never pass `-a` for a plain read.
- Overriding `flash_id` in a private copy of
  `NCP_info/chips/qcc743/eflash_loader/eflash_loader_cfg.ini` and passing it
  via `-c` does **not** fix the `QConn_Eflash.exe --flash -r` flash-type
  mismatch - the check appears to use something else internally (possibly
  the binary `flash_para.bin` blob or a hardcoded table). Don't spend more
  time on this; it's out of scope to reverse-engineer, and
  `QConn_Flash_Cmd.exe --read` already works fine instead.
- The loader config's `verify` setting (`0` = "verify by calculating
  SHA256(xip)", `>0` = "read back and verify via SHA256(sbus)") means real
  programming already includes a built-in verification step regardless of
  which value is configured - `0` is not "no verification".

## Verified ST67 flash map (and the A/B slot trap)

Confirmed 2026-08-18 against a full 4 MiB read-back of a board programmed
with `Program-ST67.sh --port COM4 --profile MissionT02 --force`:

| Region | Address | Content |
|---|---|---|
| boot2 | `0x000000` | `st67w611m_boot2_v8.1.9.bin` (exact match) |
| partition table | `0x00E000` | `partition.bin` (exact match) |
| FW slot A (active) | `0x010000` | the programmed profile image (exact match) |
| FW slot B (standby) | `0x1C4000` | erased `0xFF` unless an OTA has run |

**The `FW` partition entry is an A/B (OTA) pair, not a single address.**
Entry layout in `partition.bin` at offset `0x34`: `type`, `device`,
`activeIndex`, `name[8]`, then `addr[0]`, `addr[1]`, `maxlen[0]`,
`maxlen[1]` as little-endian `uint32`s:

```text
00000034: 00000046 57000000 00000000 00000100
00000044: 00401c00 00401b00 00401b00 00000000
```

- `activeIndex = 0` -> slot A at `addr[0] = 0x00010000` is what runs
- `addr[1] = 0x001C4000` is the standby slot, `maxlen` `0x1B4000` each

Reading `0x1C4000` and finding all `0xFF` therefore means "no OTA image
staged", **not** "firmware missing". Mistaking `addr[1]` for the firmware
address makes every image comparison fail against blank flash.

To identify which image a board is running, compare at `0x10000`:

```bash
sdk=External/x-cube-st67w61/Projects/ST67W6X_Scripts/Binaries/NCP_Binaries
for image in "$sdk"/st67w611m_{mission,mfg}_*.bin; do
  size=$(wc -c < "$image")
  dd if=dump.bin bs=4096 skip=16 2>/dev/null | head -c "$size" |
    cmp -s - "$image" && echo "MATCH: $(basename "$image")"
done
```

Do **not** try to identify an image by its first 16 bytes: every packaged
image starts with the same `42464e50...` (`BFNP`) container header, so that
signature matches all nine of them. Searching `xxd -p` output with
`grep -bo` is also wrong - it reports offsets into the hex *text*, i.e.
double the real byte offset. Match on a long chunk taken from well inside
the image instead, and confirm the candidate offsets are self-consistent
(a constant delta across several samples) before trusting them.

## Known critical bug (fixed 2026-08-17): write-direction ring overflow

The first real `Program-ST67.sh --force` attempt erased the chip, then the
boot2 write got zero real acks for ~14 minutes straight (every single
write-chunk and the write-check retried on a fixed timeout, never a genuine
ack). Root cause: `USB_TO_UART_RING_SIZE` was 512 bytes, but QConn's own
loader config specifies `tx_size = 2056` - each write chunk arrives over USB
as one burst about 4x the ring's capacity, and `CDC_Receive_FS` always
re-arms the OUT endpoint regardless of ring space (no backpressure), so most
of every write chunk was silently dropped (would show up as a large
`usb_to_uart_overflow_count` on a debugger). The ST67 then received
corrupted/truncated data and never acked it. Reads were unaffected because
the read-direction ring was already 8192 bytes and isn't host-burst-driven.

Fixed by raising `USB_TO_UART_RING_SIZE` to 8192 in `bridge_config.h`
(matches the read-side ring). **This requires reflashing the STM32 with a
rebuilt Bootloader-mode firmware** - it's a firmware bug, not a host-script
bug, so retrying with only the host-tooling fixes applied would not help.

Also confirmed: a failed/interrupted write does not brick the board. The
ST67 ROM bootloader lives in mask ROM, independent of external SPI flash
content, so the same strap/reset entry sequence is always available for a
retry regardless of flash state.

## Real-hardware validation on record

Recorded 2026-08-16, board attached on `COM4`:

- Non-destructive chip/efuse query (`Query-ST67.sh`) succeeded repeatedly:
  chip ID `0052573237531bd700`, default MAC `40:82:7B:03:B5:2C`, part number
  `C6AFDBD111400004`, manufactured 2025 week 16, JTAG disabled, public key
  filled, anti-rollback enabled.
- Actual flash chip: GigaDevice, `jedec_id c46016`, 4 MiB capacity - **not**
  the vendor default `ef4016` (Winbond) assumed by the stock loader config.
- `QConn_Flash_Cmd.exe --read` pulled 1 MiB of real flash content twice,
  independently, byte-for-byte identical (`md5sum` match), with genuine
  byte-value diversity (confirmed non-blank/non-erased real code), over
  ~9 seconds of continuous transfer each time. This is strong evidence the
  bridge is lossless at 2,000,000 baud under sustained real-world load in
  both directions (small commands host->ST67, bulk data ST67->host).

First real `--force` attempt (2026-08-17, before the ring-size fix above)
erased the chip and failed to write boot2.

Recorded 2026-08-18, with the ring-size fix reflashed - **plan Stage F is
closed**:

- `Program-ST67.sh --port COM4 --profile MissionT02 --force` completed a
  full erase/program/verify cycle successfully.
- An independent 4 MiB read-back confirmed it byte-for-byte: boot2, the
  partition table, and the active FW slot at `0x10000` all match their
  vendor files exactly. Active image
  `st67w611m_mission_t02_v2.0.106.bin`, SHA-256
  `7762646fdff5f658659389849f20be0235ce3ba1a917b42e6568318762154a90`.
- That read-back is also the strongest transport evidence on record: a
  1.27 MiB vendor binary recovered with an exact hash match, so the bridge
  is lossless in bulk in both directions.

Recorded 2026-08-19 - **plan Stage D is closed**:

- Debugger-instrumented full 4 MiB read logged `usb_tx_failure_count = 1131`
  and `uart_framing_error_count = 1`; every other counter (both ring
  overflow counters and the remaining three UART hardware error counters)
  read 0.
- Re-hashing that exact dump (not a separate run) still matched boot2, the
  partition table, and the active FW slot byte-for-byte against the vendor
  files. This confirms `usb_tx_failure_count` is a benign retry counter (see
  the note under Reset/session-boundary handling above) and that the single
  framing error was a one-off line glitch that didn't desync either ring or
  corrupt any delivered byte.

Recorded 2026-10-03/04, the first T01 programming of the AstroWeather board
(STM32G0B1 on the same pins; `Release-Bootloader` build of this firmware
flashed over ST-LINK, then the HostController flashed back the same way):

- `Query-ST67.sh --port COM4` matched the 2026-08-16 identity exactly (same
  chip ID, MAC, part number, anti-rollback enabled).
- `Program-ST67.sh --port COM4 --profile MissionT01 --force`: erase, program
  and verify in 16.2 s; device-side SHA-256 of `st67w611m_mission_t01_v2.0.106.bin`
  `33198f446ac7c1b9c48e25573f3498e7277119dff43da12a3e25791078b552f3`, equal
  to the file; the vendor `littlefs.bin` verified at `0x378000` as well.
- Same again with `--config-path tools/astroweather_t01_flash_prog_cfg.ini`,
  writing `tools/littlefs/littlefs.bin` (one file, `AmazonRootCA1.pem`)
  instead of the vendor image: all three regions verified. This is the
  configuration the HostController needs; see the README.
- The module reports a stored file's size rounded up to 256 bytes after a
  restart (`AT+FS=0,4` gives 1280 for a 1208-byte file), which the X-CUBE
  driver takes as a changed file. Harmless here (one rewrite per boot), noted
  in case an image is ever compared by size.

## Open items / suggested next steps

1. Re-validate `Dump-ST67-Flash.sh` across boards with different flash chips.
2. Delete any stale `build/Debug` / `build/Release` directories left over
   from before the four-preset scheme, if they reappear.

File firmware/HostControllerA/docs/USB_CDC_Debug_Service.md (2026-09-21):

# USB CDC Debug Service

## Purpose and Scope

The HostController firmware exposes a USB CDC virtual COM port for diagnostic logging and a line-oriented host healthcheck. `DebugService` owns the application-facing CDC behavior: it serializes transmit requests, accepts logs from application tasks, and converts received USB bytes into echo responses.

The service is currently started only by the HostController variant. It is not started by the DisplayController variant. The service is intentionally limited to logging and the healthcheck echo; it is not a general command-line interface and does not persist logs.

## Lifecycle

`AppVariant_Init()` initializes and starts the singleton service after the RTOS kernel has been initialized. `DebugService` is a `Task<1024>` named `DebugService` with normal priority.

USB device startup remains in the CubeMX USB device layer. `CDC_Transmit_FS()` treats an uninitialized or disconnected USB CDC class as busy, allowing the debug task to continue operating while no host is attached.

## Module Boundaries

- `User/Inc/Debug/DebugService.hpp` defines the C++ service and its logging API.
- `User/Src/Debug/DebugService.cpp` implements the service and the C bridge function.
- `User/Inc/Debug/DebugServiceBridge.h` exposes `DebugService_OnUsbRxData()` to C code without exposing C++ types.
- `USB_Device/App/usbd_cdc_if.c` remains the CubeMX CDC transport implementation. Its receive callback passes bytes to `DebugService_OnUsbRxData()` and immediately rearms reception.
- `User/Src/HostController/AppVariant.cpp` is the HostController-only startup point.

Keep CDC-specific changes in CubeMX `USER CODE` sections. Application code must not call `CDC_Transmit_FS()` directly: the `DebugService` task is the sole application owner of CDC transmission.

## Logging API

Application tasks publish diagnostics through the singleton:

```cpp
DebugService::instance().log(DebugService::Level::Info, "connected");
DebugService::instance().logf(DebugService::Level::Warn, "retry %lu", retryCount);
```

`Level` values are `Info`, `Warn`, `Error`, and `Debug`, emitted as `INFO`, `WARN`, `ERR`, and `DEBUG`. When viewed in an ANSI-capable terminal, error records are red, warnings are yellow, and debug records are dark gray. Info records have no color. Each log line is formatted as:

```text
[days:hours:minutes:seconds] [LEVEL] message\n
```

The uptime is derived from `HAL_GetTick()`. `log()` and `logf()` are non-blocking, task-context APIs. They copy the formatted result into a static CMSIS message queue; callers must not retain ownership of a buffer after publishing because no caller buffer is stored.

The queue holds 64 entries of up to 127 characters plus a terminator. Formatting that exceeds the fixed record is truncated by the C formatting functions. On a full queue, the oldest queued record is removed and the newest record is inserted. If the replacement cannot be inserted, the new record is dropped. In either case, `droppedCount` is incremented for each lost record.

## Receive and Healthcheck Protocol

`CDC_Receive_FS()` may run in USB interrupt context. It passes the received bytes to the service, which places them in a single-producer/single-consumer ring buffer and wakes the debug task. The ring holds 256 bytes. Bytes received after the ring is full are discarded and counted in `rxOverflowCount`.

The debug task assembles lines as follows:

- `\r` is ignored.
- `\n` terminates a line.
- Other bytes are treated as text.
- A line stores at most 95 characters. Further characters before its terminator are discarded; one truncation is counted in `rxTruncatedCount` for that line.

Every completed line, including an empty line, produces this echo response:

```text
[days:hours:minutes:seconds]: received text\n
```

For example, `ping\n` sent by the host can produce `[0:00:01:23]: ping\n`. The host must send a newline to receive a response. The service does not interpret commands.

## Transmit Behavior and Backpressure

The debug task serializes healthcheck echoes, log records, and periodic statistics through a shared transmit buffer. It retries `CDC_Transmit_FS()` only when the transport reports `USBD_BUSY`, waiting 5 ms between attempts for no more than 40 ms. A non-busy failure or an exhausted retry window drops that outgoing packet and increments `busyDropCount`.

Queued logs are removed before they are transmitted. Therefore, a log accepted by `log()` can still be lost if CDC transmission later fails or remains busy. Echo responses use the same retry policy. This design favors keeping application tasks responsive over retaining output while the host is absent or slow.

Periodic statistics are off at boot and are switched with the `stats on` and `stats off` console commands; the setting is not persisted. While enabled, the task emits them every 5 seconds on a fixed schedule, whatever other log traffic is flowing, and once immediately when they are switched on. Earlier firmware emitted them only after 5 seconds with no other output, so they never appeared while the log was busy. Each report is:

```text
[days:hours:minutes:seconds] [STATS] sent=N dropped=N busyDrop=N rxOverflow=N rxTrunc=N\n
```

The periodic `[MEM]` and `[STACK]` records use the same dark-gray ANSI formatting as `Debug` logs. The `[STATS]` record remains uncolored.

`sent` counts successfully transmitted log records only; it does not include echo responses or statistics lines. The other counters are cumulative since startup.

## Connect Message

When a host opens the port, the console prints a short welcome so the device does not look dead while statistics are off:

```text
OK connected to AstroWeather HostController, built <date> <time>
Settings loaded from EEPROM: ok
Type 'help' for commands. Periodic stats are off; 'stats on' to switch.
```

Opening is detected from two CDC requests, both hooked in the `USER CODE 5` block of `USB_Device/App/usbd_cdc_if.c`:

- `SET_LINE_CODING`, which every terminal sends when it opens the port to set the baud rate, even though USB CDC ignores it. This is what reaches terminals that never raise DTR, such as HTerm with its default settings. It calls `ConsoleService_OnHostLineCoding()`.
- `SET_CONTROL_LINE_STATE`, on a rising edge of DTR, which pyserial and `astro_console.py` raise on open. It calls `ConsoleService_OnHostLineState()`.

A program that sends both gets them within milliseconds of each other, so the console prints at most one welcome per second. Changing the baud rate in a terminal that is already connected sends `SET_LINE_CODING` again, and so prints the welcome again.

The settings line is there because the startup log is emitted before USB enumerates and is never delivered; it restates the one boot-time result worth knowing.

## Fixed Limits

| Resource | Limit |
| --- | ---: |
| Debug task stack | 1024 bytes |
| Log queue depth | 64 records |
| Log record text | 127 characters plus terminator |
| RX ring | 256 bytes |
| RX line text | 95 characters plus terminator |
| CDC busy retry window | 40 ms |
| CDC busy retry delay | 5 ms |
| Statistics interval | 5 seconds, fixed, while `stats on` (off at boot) |

## Maintenance Notes

- Preserve the C bridge between `usbd_cdc_if.c` and the C++ service. Do not include C++ headers in CubeMX-generated C code.
- Preserve the single CDC transmit owner. Any future CDC output type should enter the service task rather than calling the transport from another task or interrupt.
- If logging from interrupt context is required, add a dedicated ISR-safe producer path. The existing logging API is documented for task context; only the USB RX ingress path is designed for interrupt context.
- Changes to queue, ring, or line limits affect static memory use and loss behavior. Update this document and validate burst logging, long input lines, and host disconnect/reconnect behavior with the affected build variant.

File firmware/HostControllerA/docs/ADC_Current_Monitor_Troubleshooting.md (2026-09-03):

# ADC Current Monitor Troubleshooting Summary

## Problem

The current monitor reads `ADC1_IN10` on `PB2`. The input is connected to an INA180A2 current-sense amplifier with:

- INA180 gain: 50 V/V
- Shunt resistor: 50 mOhm
- ADC input filter: 100 kOhm series resistor and 1 uF capacitor to ground
- Intended sample cadence: one reading every 100 ms
- Nominal ADC reference: VDDA = 3.3 V

The oscilloscope measures approximately 20-30 mV at the PB2 ADC node, but firmware reports unexpected ADC values.

## Expected result

The INA180 output relationship is:

```text
Vout = I * 0.05 ohm * 50
Vout = I * 2.5 V/A
I    = Vout / 2.5 V/A
```

For a 12-bit, right-aligned ADC using a 3.3 V reference:

```text
ADC raw = Vpb2 / 3.3 V * 4095
```

Therefore, a measured PB2 voltage of 20-30 mV should produce approximately:

```text
20 mV -> raw 25 -> current 8 mA
30 mV -> raw 37 -> current 12 mA
```

The nominal conversion used by the application is:

```text
current_mA = raw * 3300 / (4095 * 2.5)
```

The implementation uses 64-bit intermediate arithmetic to prevent overflow.

## Observed behavior

### Oversampling disabled

The firmware repeatedly reports only:

```text
raw=255  (0x0FF), current_mA=82
raw=511  (0x1FF), current_mA=164
```

For a normal 12-bit right-aligned conversion, those values correspond to approximately:

```text
raw 255 -> 205 mV -> 82 mA
raw 511 -> 412 mV -> 164 mA
```

They do not correspond to the independently measured 20-30 mV at PB2.

### 16x oversampling with four-bit right shift

The firmware reports values such as:

```text
511, 495, 447, 431, 367, 303, 271, 319
```

Many values have the form:

```text
16 * N - 1
```

For example:

```text
511 = 16 * 32 - 1
495 = 16 * 31 - 1
447 = 16 * 28 - 1
```

The current generated ADC configuration at that point was:

```c
hadc1.Init.Resolution = ADC_RESOLUTION_12B;
hadc1.Init.DataAlign = ADC_DATAALIGN_RIGHT;
hadc1.Init.OversamplingMode = ENABLE;
hadc1.Init.Oversampling.Ratio = ADC_OVERSAMPLING_RATIO_16;
hadc1.Init.Oversampling.RightBitShift = ADC_RIGHTBITSHIFT_4;
```

The repeated lower nibble `0xF` is not expected from ordinary analog quantization. It suggests that the value format, applied shift, runtime configuration, or data-register interpretation must be verified.

## Confirmed project configuration

- `PB2` is configured as `ADC1_IN10`.
- The GPIO is configured in analog mode with no pull resistor.
- ADC resolution is configured as 12-bit.
- ADC data alignment is configured as right-aligned.
- ADC rank 1 contains channel 10.
- The sample time is configured as 160.5 ADC cycles, appropriate for the high source impedance.
- The application starts one software-triggered conversion and reads it with `HAL_ADC_GetValue()`.
- The application task schedules readings every 100 ms using `osDelayUntil()`.
- PC6 is physically connected to PB2 and is configured as analog/no-pull. This should be high impedance, but any other circuitry on the PC6 net can still affect the measurement.

## Current interpretation

The issue is not the 32-bit arithmetic overflow that was previously present. That overflow has been fixed by promoting the calculation to 64-bit before multiplication.

The issue is also not explained by normal ADC left alignment:

```text
12-bit right-aligned 0.205 V -> approximately 255
12-bit left-aligned  0.205 V -> approximately 4080
```

The fact that the scope sees 20-30 mV while the ADC reports values representing 205-412 mV means at least one of the following remains possible:

1. The oscilloscope probe and ADC conversion are not observing the same electrical node or ground reference.
2. The ADC runtime registers differ from the generated source or flashed image.
3. The ADC data is being interpreted with the wrong result format.
4. Another circuit connected to the PB2/PC6 net is influencing the signal.
5. The signal changes faster than the scope measurement or the ADC sampling interval reveals.
6. The oversampling setting or right shift is not applied as expected at runtime.

The exact `0xFF` and `0x1FF` values are suspicious, but they are not by themselves proof of bit misalignment. They are valid numeric values for a normal 12-bit ADC and could result from a real 205 mV or 412 mV signal.

## Required diagnostic

The next firmware diagnostic should capture the ADC data register, status register, and configuration registers at the time of conversion:

```cpp
const uint32_t raw = HAL_ADC_GetValue(&hadc1);
const uint32_t dr = ADC1->DR;
const uint32_t isr = ADC1->ISR;
const uint32_t cfgr1 = ADC1->CFGR1;
const uint32_t cfgr2 = ADC1->CFGR2;
```

Log the values in hexadecimal. Reading `ADC1->DR` after `HAL_ADC_GetValue()` may clear the end-of-conversion flag, so for a precise register capture read the data register once and use that value as the sample, or capture the register before the HAL call during a diagnostic build.

Verify these runtime fields:

```text
CFGR1.RES  = 12-bit setting
CFGR1.ALIGN = right alignment
CFGR2.OVSE = disabled or enabled as intended
CFGR2.OVSR = 16x only when oversampling is enabled
CFGR2.OVSS = 4 only when a four-bit shift is intended
```

The most useful data-register test is to compare a stable, known voltage against the result:

```text
0.000 V -> approximately raw 0
0.330 V -> approximately raw 410
1.000 V -> approximately raw 1241
1.650 V -> approximately raw 2048
```

Do not apply a voltage above VDDA to PB2.

## Hardware checks

Measure both points relative to the STM32 ground:

```text
INA180 OUT
PB2 / PC6 net, directly at the MCU pin
```

The PB2 network should be:

```text
INA180 OUT ---- 100 kOhm ---- PB2
                              |
                             1 uF
                              |
                             GND
```

Confirm:

- The capacitor is populated and really 1 uF.
- The capacitor is connected to the PB2 side of the resistor.
- PC6 has no external pull-up, pull-down, digital output, or peripheral connection.
- INA180 ground and STM32 ground are common.
- INA180 REF is connected for the intended unidirectional measurement.
- The INA180 output remains within its supply and ADC input limits.

An oscilloscope trace at both INA180 OUT and PB2 is preferable. The 100 kOhm / 1 uF filter has a 100 ms time constant and an approximate 1.59 Hz cutoff, so PB2 should be much slower than the unfiltered amplifier output.

## Resolution path

1. Keep oversampling disabled while diagnosing the basic ADC path.
2. Apply a stable known voltage directly to PB2 and verify the four expected ADC results above.
3. Capture runtime `CFGR1`, `CFGR2`, `ISR`, and `DR` values.
4. If the known-voltage test works, investigate the INA180 output, the RC network, and the PB2/PC6 PCB net.
5. Re-enable oversampling only after the basic 12-bit result is correct.
6. With 16x oversampling, confirm the returned value is in the expected range after the configured four-bit shift before applying the normal current conversion.

## Test coverage

The pure conversion function is implemented in:

```text
User/Inc/Sensors/CurrentSenseConversion.hpp
```

and tested in:

```text
tests/CurrentSenseConversionTests.cpp
```

The test covers raw values 0, 255, 511, 4095, and a custom 3.0 V VDDA case. The native conversion test passes, and the firmware build passes.

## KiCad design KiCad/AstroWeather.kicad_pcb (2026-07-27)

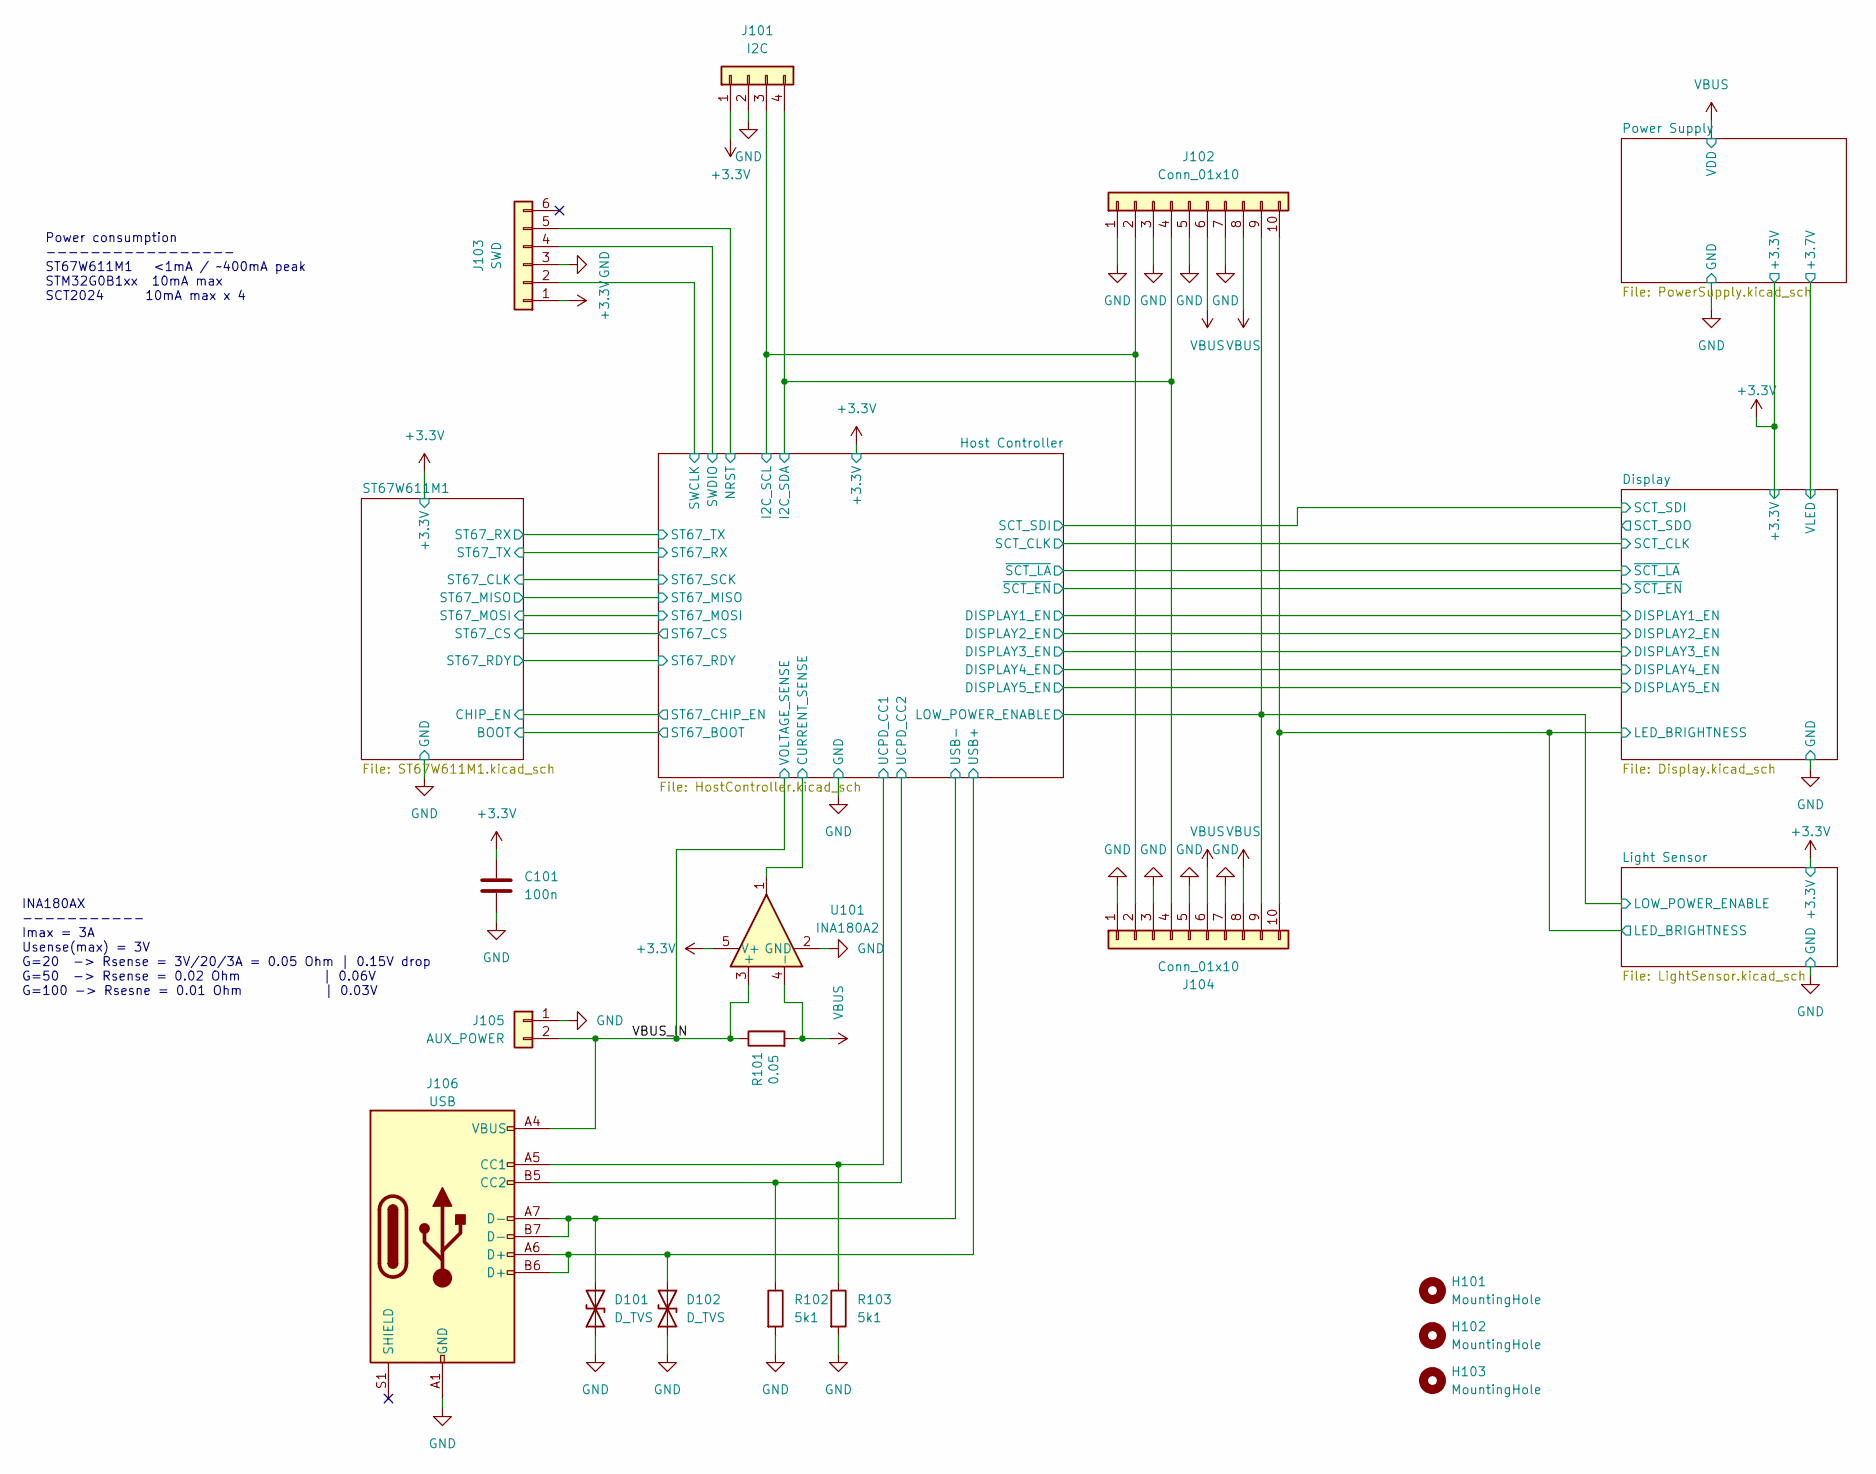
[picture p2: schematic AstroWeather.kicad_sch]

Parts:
C101: 100n; C_0603_1608Metric
D101, D102: D_TVS; D_SOD-323
H101, H102, H103: MountingHole; MountingHole_3.2mm_M3
J101: I2C; PinHeader_1x04_P2.54mm_Vertical
J102: Conn_01x10; PinSocket_1x10_P2.54mm_Horizontal
J103: SWD; JST_PH_B6B-PH-K_1x06_P2.00mm_Vertical
J104: Conn_01x10; PinHeader_1x10_P2.54mm_Horizontal
J105: AUX_POWER; PinHeader_1x02_P2.54mm_Vertical
J106: USB; USB_C_Receptacle_GCT_USB4216
R101: 0.05; R_1206_3216Metric
R102, R103: 5k1; R_0805_2012Metric
U101: INA180A2; SOT-23-5

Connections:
+3.3V: C101.1, J101.1, J103.1, U101.5 (V+); also elsewhere on the board
/Display/LED_BRIGHTNESS: J102.10, J104.10; also elsewhere on the board
/Host Controller/CURRENT_SENSE: U101.1; also elsewhere on the board
/Host Controller/I2C_SCL: J101.3, J102.2, J104.2; also elsewhere on the board
/Host Controller/I2C_SDA: J101.4, J102.4, J104.4; also elsewhere on the board
/Host Controller/LOW_POWER_ENABLE: J102.9, J104.9; also elsewhere on the board
/Host Controller/NRST: J103.5; also elsewhere on the board
/Host Controller/SWCLK: J103.2; also elsewhere on the board
/Host Controller/SWDIO: J103.4; also elsewhere on the board
/Host Controller/UCPD_CC1: J106.A5 (CC1), R103.1; also elsewhere on the board
/Host Controller/UCPD_CC2: J106.B5 (CC2), R102.1; also elsewhere on the board
/Host Controller/USB+: D102.2 (A2), J106.A6 (D+), J106.B6 (D+); also elsewhere on the board
/Host Controller/USB-: D101.2 (A2), J106.A7 (D-), J106.B7 (D-); also elsewhere on the board
/VBUS_IN: J105.2, J106.A4 (VBUS), J106.A9 (VBUS), J106.B4 (VBUS), J106.B9 (VBUS), R101.1, U101.3 (+); also elsewhere on the board
GND: C101.2, D101.1 (A1), D102.1 (A1), J101.2, J102.1, J102.3, J102.5, J102.7, J103.3, J104.1, J104.3, J104.5, J104.7, J105.1, J106.A1 (GND), J106.A12 (GND), J106.B1 (GND), J106.B12 (GND), R102.2, R103.2, U101.2 (GND); also elsewhere on the board
VBUS: J102.6, J102.8, J104.6, J104.8, R101.2, U101.4 (-); also elsewhere on the board

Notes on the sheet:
Power consumption ----------------- ST67W611M1 <1mA / ~400mA peak STM32G0B1xx 10mA max SCT2024 10mA max x 4
INA180AX ----------- Imax = 3A Usense(max) = 3V G=20 -> Rsense = 3V/20/3A = 0.05 Ohm | 0.15V drop G=50 -> Rsense = 0.02 Ohm | 0.06V G=100 -> Rsesne = 0.01 Ohm | 0.03V

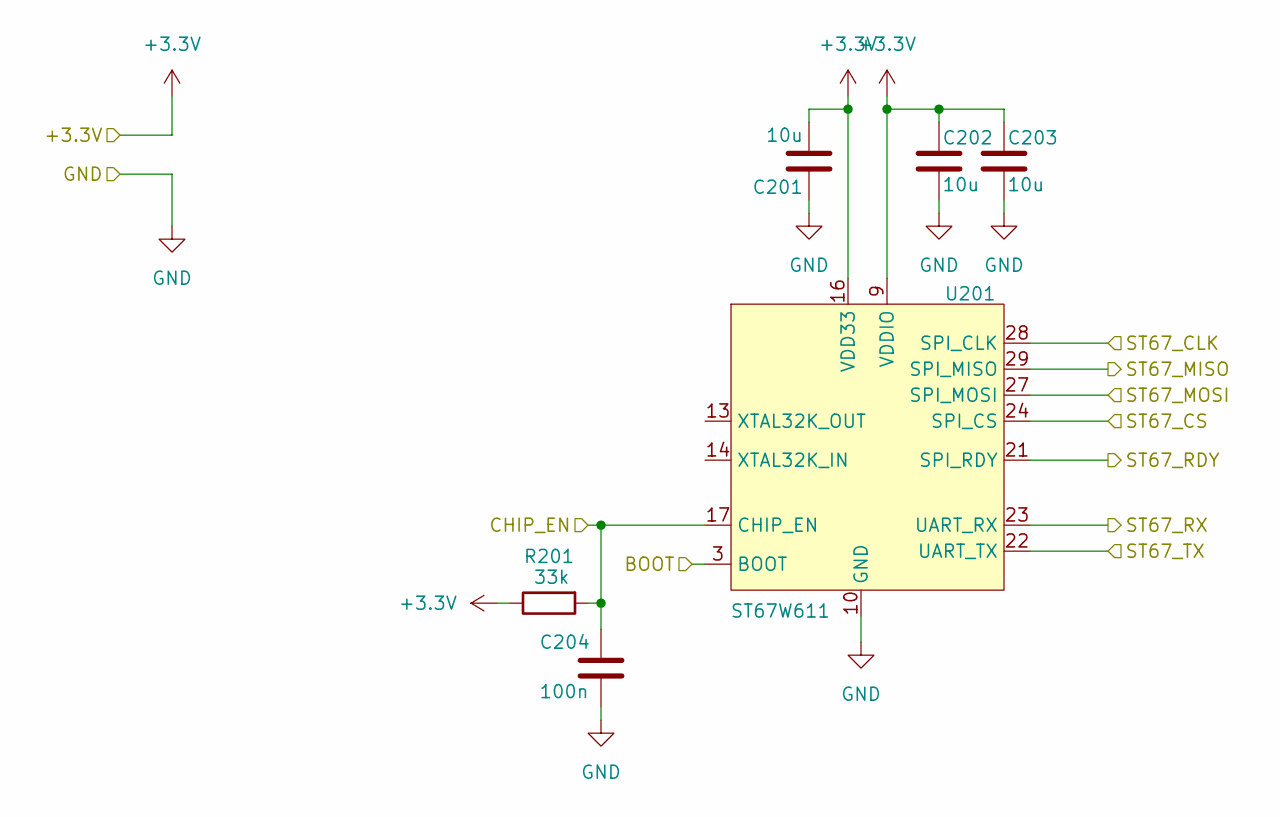
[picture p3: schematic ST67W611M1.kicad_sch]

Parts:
C201, C202, C203: 10u; C_0805_2012Metric
C204: 100n; C_0805_2012Metric
R201: 33k; R_0805_2012Metric
U201: ST67W611; ST67W611M1

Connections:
+3.3V: C201.2, C202.1, C203.1, R201.1, U201.9 (VDDIO), U201.16 (VDD33), U201.25 (VDDIO); also elsewhere on the board
/Host Controller/ST67_BOOT: U201.3 (BOOT); also elsewhere on the board
/Host Controller/ST67_CHIP_EN: C204.2, R201.2, U201.17 (CHIP_EN); also elsewhere on the board
/Host Controller/ST67_CS: U201.24 (SPI_CS); also elsewhere on the board
/Host Controller/ST67_MISO: U201.29 (SPI_MISO); also elsewhere on the board
/Host Controller/ST67_MOSI: U201.27 (SPI_MOSI); also elsewhere on the board
/Host Controller/ST67_RDY: U201.21 (SPI_RDY); also elsewhere on the board
/Host Controller/ST67_RX: U201.22 (UART_TX); also elsewhere on the board
/Host Controller/ST67_SCK: U201.28 (SPI_CLK); also elsewhere on the board
/Host Controller/ST67_TX: U201.23 (UART_RX); also elsewhere on the board
GND: C201.1, C202.2, C203.2, C204.1, U201.10 (GND), U201.15 (GND), U201.18 (GND), U201.26 (GND), U201.30 (GND), U201.32 (GND); also elsewhere on the board

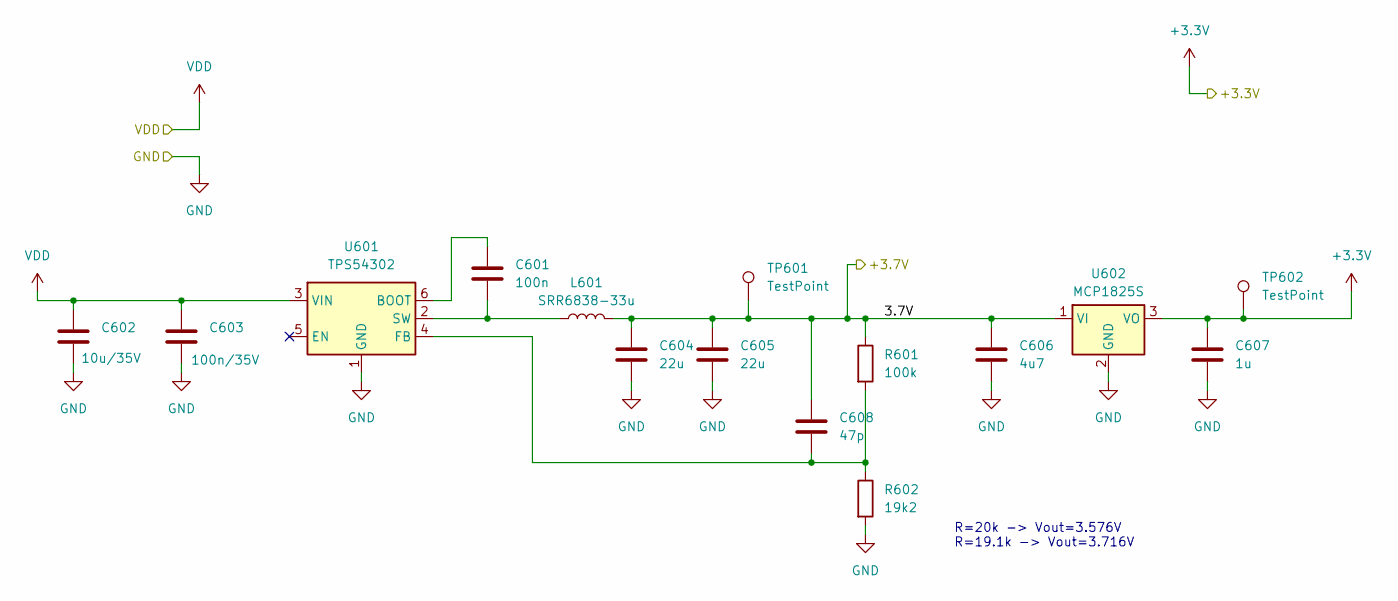
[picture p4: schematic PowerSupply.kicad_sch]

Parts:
C601: 100n; C_0805_2012Metric
C602: 10u/35V; C_0805_2012Metric
C603: 100n/35V; C_0603_1608Metric
C604, C605: 22u; C_1206_3216Metric
C606: 4u7; C_0805_2012Metric
C607: 1u; C_0805_2012Metric
C608: 47p; C_0805_2012Metric
L601: SRR6838-33u; L_Bourns_SRP7028A_7.3x6.6mm
R601: 100k; R_0805_2012Metric
R602: 19k2; R_0805_2012Metric
TP601, TP602: TestPoint; TestPoint_Pad_D1.5mm
U601: TPS54302; SOT-23-6
U602: MCP1825S; SOT-223-3_TabPin2

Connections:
+3.3V: C607.1, TP602.1, U602.3 (VO); also elsewhere on the board
GND: C602.1, C603.2, C604.2, C605.2, C606.2, C607.2, R602.2, U601.1 (GND), U602.2 (GND); also elsewhere on the board
unnamed: C601.1, U601.6 (BOOT)
unnamed: C608.2, R601.2, R602.1, U601.4 (FB)
unnamed: C601.2, L601.1, U601.2 (SW)
VBUS: C602.2, C603.1, U601.3 (VIN); also elsewhere on the board
VDD: C604.1, C605.1, C606.1, C608.1, L601.2, R601.1, TP601.1, U602.1 (VI); also elsewhere on the board

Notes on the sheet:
R=20k -> Vout=3.576V R=19.1k -> Vout=3.716V

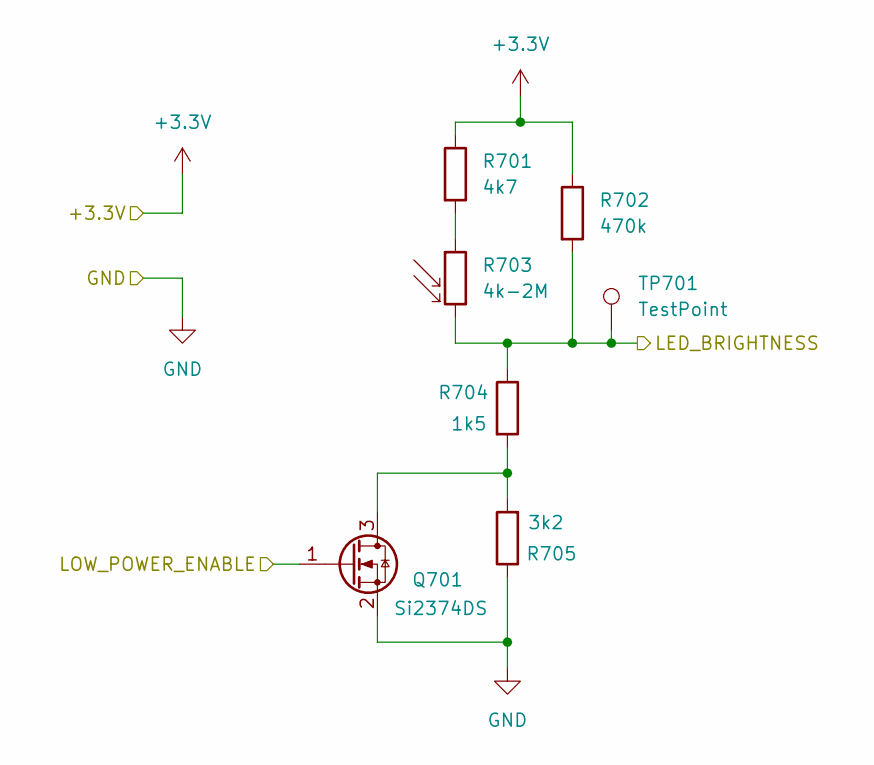
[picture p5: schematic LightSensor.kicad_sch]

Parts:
Q701: Si2374DS; SOT-23
R701: 4k7; R_0805_2012Metric
R702: 470k; R_0805_2012Metric
R703: 4k-2M; R_LDR_4.9x4.2mm_P2.54mm_Vertical
R704: 1k5; R_0805_2012Metric
R705: 3k2; R_0805_2012Metric
TP701: TestPoint; TestPoint_Pad_D1.5mm

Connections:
+3.3V: R701.1, R702.1; also elsewhere on the board
/Display/LED_BRIGHTNESS: R702.2, R703.2, R704.1, TP701.1; also elsewhere on the board
/Host Controller/LOW_POWER_ENABLE: Q701.1 (G); also elsewhere on the board
GND: Q701.2 (S), R705.1; also elsewhere on the board
unnamed: Q701.3 (D), R704.2, R705.2
unnamed: R701.2, R703.1

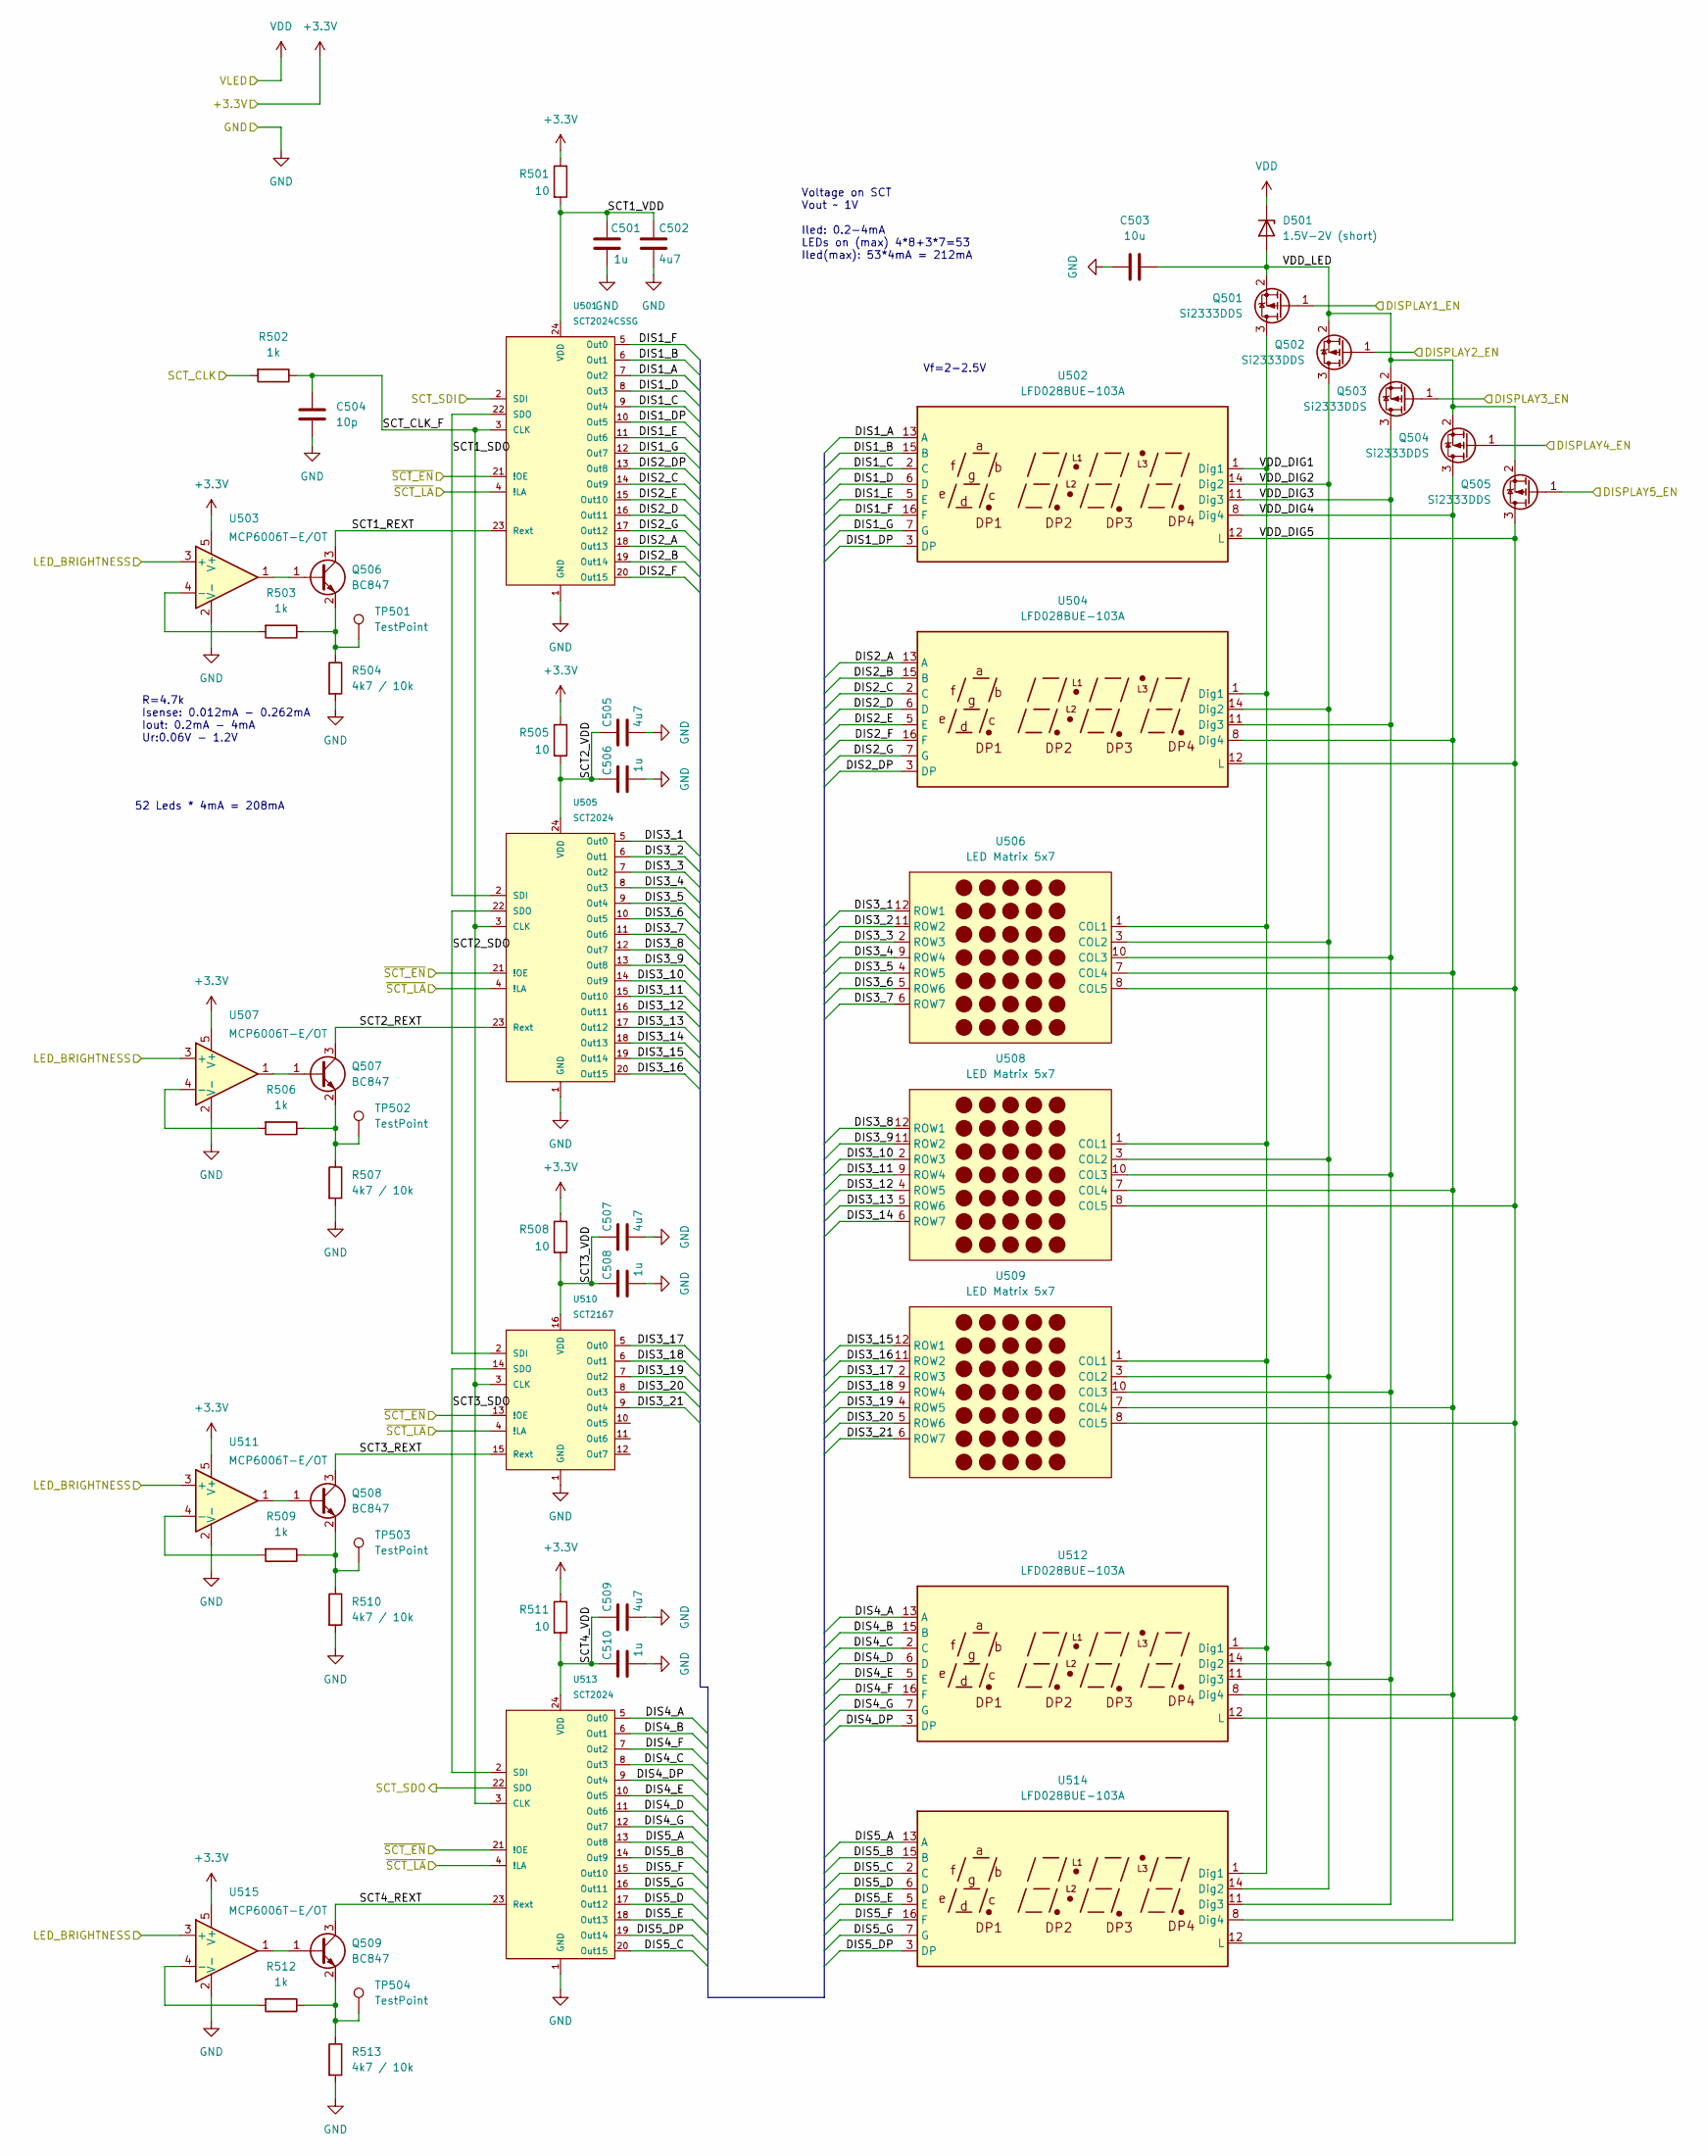
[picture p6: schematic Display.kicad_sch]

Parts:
C501, C506, C508, C510: 1u; C_0805_2012Metric
C502, C505, C507, C509: 4u7; C_0805_2012Metric
C503: 10u; C_0805_2012Metric
C504: 10p; C_0805_2012Metric
D501: 1.5V-2V (short); D_SMA
Q501, Q502, Q503, Q504, Q505: Si2333DDS; SOT-23
Q506, Q507, Q508, Q509: BC847; SOT-23
R501, R505, R508, R511: 10; R_0805_2012Metric
R502, R503, R506, R509, R512: 1k; R_0805_2012Metric
R504, R507, R510, R513: 4k7 / 10k; R_0805_2012Metric
TP501, TP502, TP503, TP504: TestPoint; TestPoint_Pad_D1.5mm
U501: SCT2024CSSG; SSOP-24_3.9x8.7mm_P0.635mm
U502, U504, U512, U514: LFD028BUE-103A
U503, U507, U511, U515: MCP6006T-E/OT; SOT-23-5
U505, U513: SCT2024; SSOP-24_3.9x8.7mm_P0.635mm
U506, U508, U509: LED Matrix 5x7; FYM-7571A
U510: SCT2167; SSOP-16_3.9x4.9mm_P0.635mm

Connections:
+3.3V: R501.1, R505.1, R508.1, R511.1, U503.5 (V+), U507.5 (V+), U511.5 (V+), U515.5 (V+); also elsewhere on the board
/Display/DIS1_A: U501.7 (Out2), U502.13 (A)
/Display/DIS1_B: U501.6 (Out1), U502.15 (B)
/Display/DIS1_C: U501.9 (Out4), U502.2 (C)
/Display/DIS1_D: U501.8 (Out3), U502.6 (D)
/Display/DIS1_DP: U501.10 (Out5), U502.3 (DP)
/Display/DIS1_E: U501.11 (Out6), U502.5 (E)
/Display/DIS1_F: U501.5 (Out0), U502.16 (F)
/Display/DIS1_G: U501.12 (Out7), U502.7 (G)
/Display/DIS2_A: U501.18 (Out13), U504.13 (A)
/Display/DIS2_B: U501.19 (Out14), U504.15 (B)
/Display/DIS2_C: U501.14 (Out9), U504.2 (C)
/Display/DIS2_D: U501.16 (Out11), U504.6 (D)
/Display/DIS2_DP: U501.13 (Out8), U504.3 (DP)
/Display/DIS2_E: U501.15 (Out10), U504.5 (E)
/Display/DIS2_F: U501.20 (Out15), U504.16 (F)
/Display/DIS2_G: U501.17 (Out12), U504.7 (G)
/Display/DIS3_1: U505.5 (Out0), U506.12 (ROW1)
/Display/DIS3_2: U505.6 (Out1), U506.11 (ROW2)
/Display/DIS3_3: U505.7 (Out2), U506.2 (ROW3)
/Display/DIS3_4: U505.8 (Out3), U506.9 (ROW4)
/Display/DIS3_5: U505.9 (Out4), U506.4 (ROW5)
/Display/DIS3_6: U505.10 (Out5), U506.5 (ROW6)
/Display/DIS3_7: U505.11 (Out6), U506.6 (ROW7)
/Display/DIS3_8: U505.12 (Out7), U508.12 (ROW1)
/Display/DIS3_9: U505.13 (Out8), U508.11 (ROW2)
/Display/DIS3_10: U505.14 (Out9), U508.2 (ROW3)
/Display/DIS3_11: U505.15 (Out10), U508.9 (ROW4)
/Display/DIS3_12: U505.16 (Out11), U508.4 (ROW5)
/Display/DIS3_13: U505.17 (Out12), U508.5 (ROW6)
/Display/DIS3_14: U505.18 (Out13), U508.6 (ROW7)
/Display/DIS3_15: U505.19 (Out14), U509.12 (ROW1)
/Display/DIS3_16: U505.20 (Out15), U509.11 (ROW2)
/Display/DIS3_17: U509.2 (ROW3), U510.5 (Out0)
/Display/DIS3_18: U509.9 (ROW4), U510.6 (Out1)
/Display/DIS3_19: U509.4 (ROW5), U510.7 (Out2)
/Display/DIS3_20: U509.5 (ROW6), U510.8 (Out3)
/Display/DIS3_21: U509.6 (ROW7), U510.9 (Out4)
/Display/DIS4_A: U512.13 (A), U513.5 (Out0)
/Display/DIS4_B: U512.15 (B), U513.6 (Out1)
/Display/DIS4_C: U512.2 (C), U513.8 (Out3)
/Display/DIS4_D: U512.6 (D), U513.11 (Out6)
/Display/DIS4_DP: U512.3 (DP), U513.9 (Out4)
/Display/DIS4_E: U512.5 (E), U513.10 (Out5)
/Display/DIS4_F: U512.16 (F), U513.7 (Out2)
/Display/DIS4_G: U512.7 (G), U513.12 (Out7)
/Display/DIS5_A: U513.13 (Out8), U514.13 (A)
/Display/DIS5_B: U513.14 (Out9), U514.15 (B)
/Display/DIS5_C: U513.20 (Out15), U514.2 (C)
/Display/DIS5_D: U513.17 (Out12), U514.6 (D)
/Display/DIS5_DP: U513.19 (Out14), U514.3 (DP)
/Display/DIS5_E: U513.18 (Out13), U514.5 (E)
/Display/DIS5_F: U513.15 (Out10), U514.16 (F)
/Display/DIS5_G: U513.16 (Out11), U514.7 (G)
/Display/DISPLAY1_EN: Q501.1 (G); also elsewhere on the board
/Display/DISPLAY2_EN: Q502.1 (G); also elsewhere on the board
/Display/DISPLAY3_EN: Q503.1 (G); also elsewhere on the board
/Display/DISPLAY4_EN: Q504.1 (G); also elsewhere on the board
/Display/DISPLAY5_EN: Q505.1 (G); also elsewhere on the board
/Display/LED_BRIGHTNESS: U503.3 (+), U507.3 (+), U511.3 (+), U515.3 (+); also elsewhere on the board
/Display/SCT1_REXT: Q506.3 (C), U501.23 (Rext)
/Display/SCT1_SDO: U501.22 (SDO), U505.2 (SDI)
/Display/SCT1_VDD: C501.1, C502.1, R501.2, U501.24 (VDD)
/Display/SCT2_REXT: Q507.3 (C), U505.23 (Rext)
/Display/SCT2_SDO: U505.22 (SDO), U510.2 (SDI)
/Display/SCT2_VDD: C505.1, C506.1, R505.2, U505.24 (VDD)
/Display/SCT3_REXT: Q508.3 (C), U510.15 (Rext)
/Display/SCT3_SDO: U510.14 (SDO), U513.2 (SDI)
/Display/SCT3_VDD: C507.1, C508.1, R508.2, U510.16 (VDD)
/Display/SCT4_REXT: Q509.3 (C), U513.23 (Rext)
/Display/SCT4_VDD: C509.1, C510.1, R511.2, U513.24 (VDD)
/Display/SCT_CLK: R502.2; also elsewhere on the board
/Display/SCT_CLK_F: C504.1, R502.1, U501.3 (CLK), U505.3 (CLK), U510.3 (CLK), U513.3 (CLK)
/Display/SCT_SDI: U501.2 (SDI); also elsewhere on the board
/Display/SCT_SDO: U513.22 (SDO)
/Display/VDD_DIG1: Q501.3 (D), U502.1 (Dig1), U504.1 (Dig1), U506.1 (COL1), U508.1 (COL1), U509.1 (COL1), U512.1 (Dig1), U514.1 (Dig1)
/Display/VDD_DIG2: Q502.3 (D), U502.14 (Dig2), U504.14 (Dig2), U506.3 (COL2), U508.3 (COL2), U509.3 (COL2), U512.14 (Dig2), U514.14 (Dig2)
/Display/VDD_DIG3: Q503.3 (D), U502.11 (Dig3), U504.11 (Dig3), U506.10 (COL3), U508.10 (COL3), U509.10 (COL3), U512.11 (Dig3), U514.11 (Dig3)
/Display/VDD_DIG4: Q504.3 (D), U502.8 (Dig4), U504.8 (Dig4), U506.7 (COL4), U508.7 (COL4), U509.7 (COL4), U512.8 (Dig4), U514.8 (Dig4)
/Display/VDD_DIG5: Q505.3 (D), U502.12 (L), U504.12 (L), U506.8 (COL5), U508.8 (COL5), U509.8 (COL5), U512.12 (L), U514.12 (L)
/Display/VDD_LED: C503.1, D501.2 (A), Q501.2 (S), Q502.2 (S), Q503.2 (S), Q504.2 (S), Q505.2 (S)
/Display/~SCT_EN: U501.21 (!OE), U505.21 (!OE), U510.13 (!OE), U513.21 (!OE); also elsewhere on the board
/Display/~SCT_LA: U501.4 (!LA), U505.4 (!LA), U510.4 (!LA), U513.4 (!LA); also elsewhere on the board
GND: C501.2, C502.2, C503.2, C504.2, C505.2, C506.2, C507.2, C508.2, C509.2, C510.2, R504.2, R507.2, R510.2, R513.2, U501.1 (GND), U503.2 (V-), U505.1 (GND), U507.2 (V-), U510.1 (GND), U511.2 (V-), U513.1 (GND), U515.2 (V-); also elsewhere on the board
unnamed: Q506.1 (B), U503.1
unnamed: Q506.2 (E), R503.1, R504.1, TP501.1
unnamed: Q507.1 (B), U507.1
unnamed: Q507.2 (E), R506.1, R507.1, TP502.1
unnamed: Q508.1 (B), U511.1
unnamed: Q508.2 (E), R509.1, R510.1, TP503.1
unnamed: Q509.1 (B), U515.1
unnamed: Q509.2 (E), R512.1, R513.1, TP504.1
unnamed: R503.2, U503.4 (-)
unnamed: R506.2, U507.4 (-)
unnamed: R509.2, U511.4 (-)
unnamed: R512.2, U515.4 (-)
VDD: D501.1 (K); also elsewhere on the board

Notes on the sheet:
R=4.7k Isense: 0.012mA - 0.262mA Iout: 0.2mA - 4mA Ur:0.06V - 1.2V
Voltage on SCT Vout ~ 1V Iled: 0.2-4mA LEDs on (max) 4*8+3*7=53 Iled(max): 53*4mA = 212mA
Vf=2-2.5V
52 Leds * 4mA = 208mA

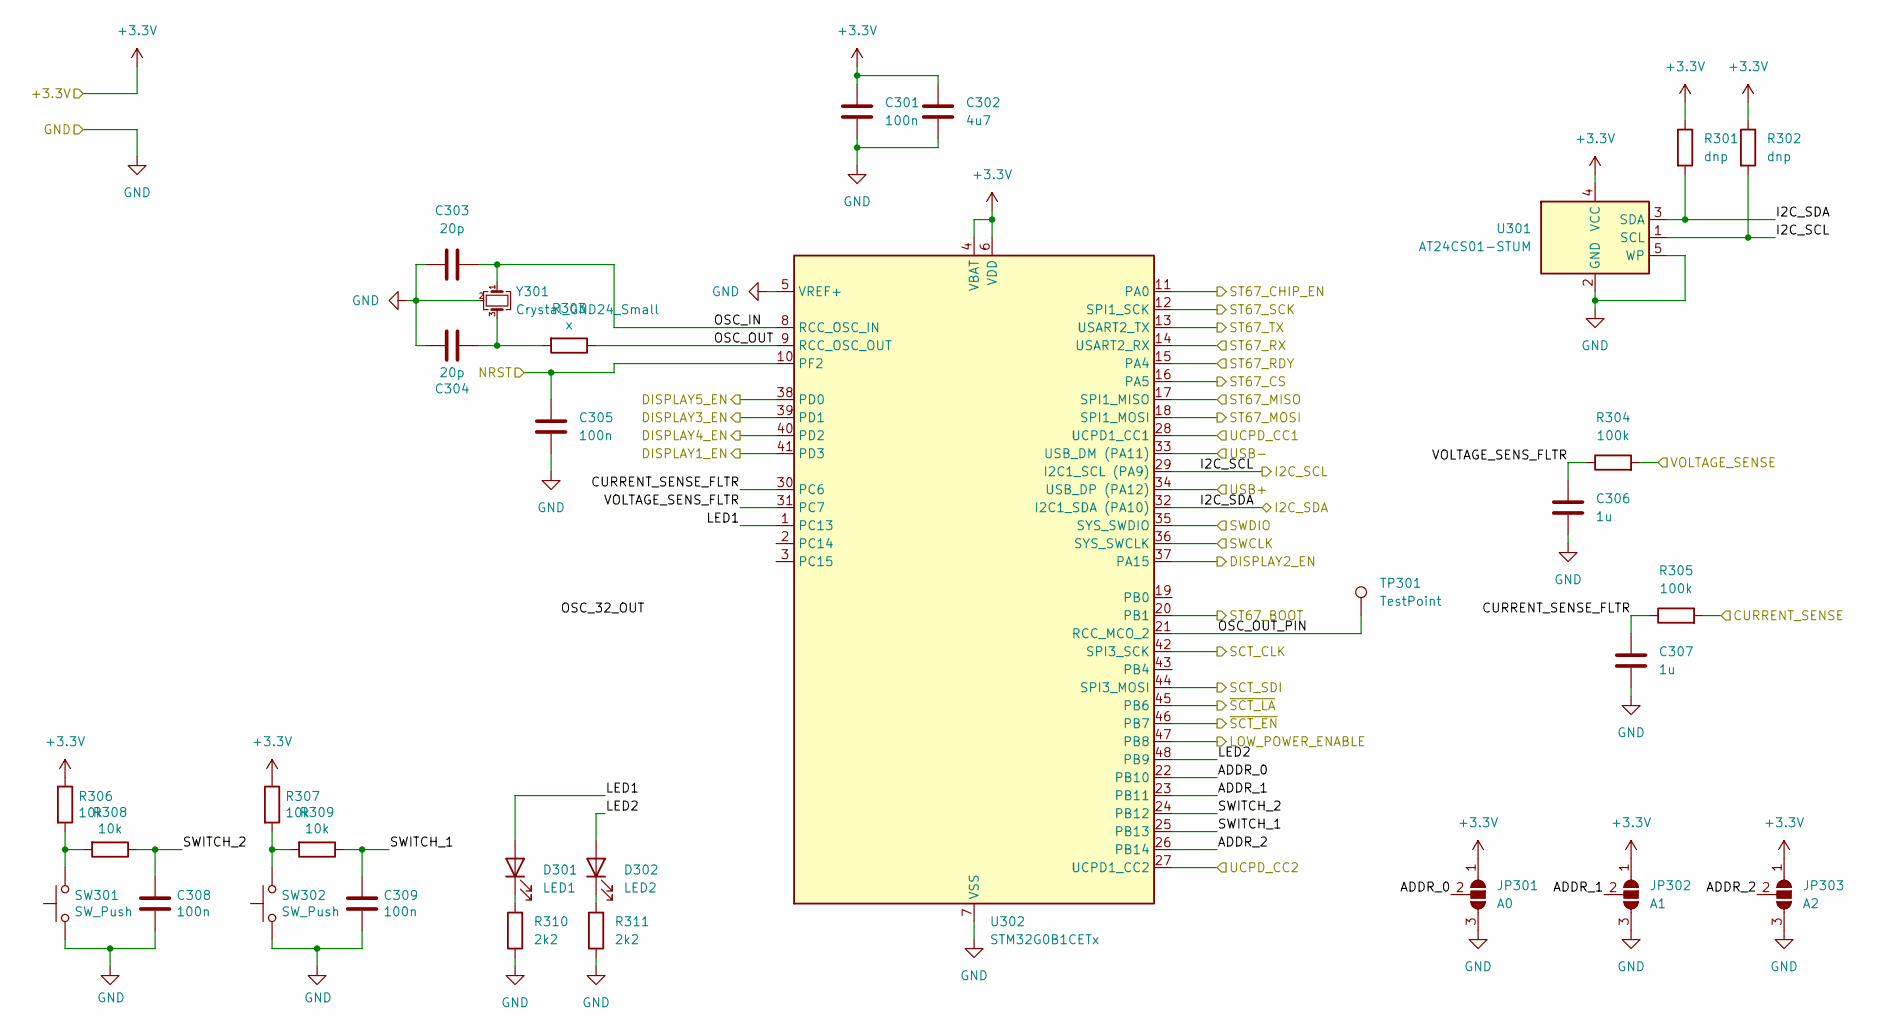
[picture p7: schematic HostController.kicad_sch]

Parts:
C301, C305, C308, C309: 100n; C_0603_1608Metric
C302: 4u7; C_0805_2012Metric
C303, C304: 20p; C_0805_2012Metric
C306, C307: 1u; C_0805_2012Metric
D301: LED1; D_0805_2012Metric
D302: LED2; D_0805_2012Metric
JP301: A0; SolderJumper-3_P1.3mm_Open_RoundedPad1.0x1.5mm
JP302: A1; SolderJumper-3_P1.3mm_Open_RoundedPad1.0x1.5mm
JP303: A2; SolderJumper-3_P1.3mm_Open_RoundedPad1.0x1.5mm
R301, R302: dnp; R_0805_2012Metric
R303: x; R_0805_2012Metric
R304, R305: 100k; R_0805_2012Metric
R306, R307, R308, R309: 10k; R_0603_1608Metric
R310, R311: 2k2; R_0805_2012Metric
SW301, SW302: SW_Push; SW_Tactile_SPST_NO_Straight_CK_PTS636Sx25SMTRLFS
TP301: TestPoint; TestPoint_Pad_D1.5mm
U301: AT24CS01-STUM; SOT-23-5
U302: STM32G0B1CETx; LQFP-48_7x7mm_P0.5mm
Y301: Crystal_GND24_Small; Crystal_SMD_Abracon_ABM3B-4Pin_5.0x3.2mm

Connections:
+3.3V: C301.1, C302.1, JP301.1 (A), JP302.1 (A), JP303.1 (A), R301.1, R302.1, R306.1, R307.1, U301.4 (VCC), U302.4 (VBAT), U302.6 (VDD); also elsewhere on the board
/Display/DISPLAY1_EN: U302.41 (PD3); also elsewhere on the board
/Display/DISPLAY2_EN: U302.37 (PA15); also elsewhere on the board
/Display/DISPLAY3_EN: U302.39 (PD1); also elsewhere on the board
/Display/DISPLAY4_EN: U302.40 (PD2); also elsewhere on the board
/Display/DISPLAY5_EN: U302.38 (PD0); also elsewhere on the board
/Display/SCT_CLK: U302.42 (SPI3_SCK); also elsewhere on the board
/Display/SCT_SDI: U302.44 (SPI3_MOSI); also elsewhere on the board
/Display/~SCT_EN: U302.46 (PB7); also elsewhere on the board
/Display/~SCT_LA: U302.45 (PB6); also elsewhere on the board
/Host Controller/ADDR_0: JP301.2 (C), U302.22 (PB10)
/Host Controller/ADDR_1: JP302.2 (C), U302.23 (PB11)
/Host Controller/ADDR_2: JP303.2 (C), U302.26 (PB14)
/Host Controller/CURRENT_SENSE: R305.2; also elsewhere on the board
/Host Controller/CURRENT_SENSE_FLTR: C307.1, R305.1, U302.30 (PC6)
/Host Controller/I2C_SCL: R302.2, U301.1 (SCL), U302.29 (I2C1_SCL (PA9)); also elsewhere on the board
/Host Controller/I2C_SDA: R301.2, U301.3 (SDA), U302.32 (I2C1_SDA (PA10)); also elsewhere on the board
/Host Controller/LED1: D301.2 (A), U302.1 (PC13)
/Host Controller/LED2: D302.2 (A), U302.48 (PB9)
/Host Controller/LOW_POWER_ENABLE: U302.47 (PB8); also elsewhere on the board
/Host Controller/NRST: C305.1, U302.10 (PF2); also elsewhere on the board
/Host Controller/OSC_IN: C303.2, U302.8 (RCC_OSC_IN), Y301.1
/Host Controller/OSC_OUT: R303.1, U302.9 (RCC_OSC_OUT)
/Host Controller/OSC_OUT_PIN: TP301.1, U302.21 (RCC_MCO_2)
/Host Controller/ST67_BOOT: U302.20 (PB1); also elsewhere on the board
/Host Controller/ST67_CHIP_EN: U302.11 (PA0); also elsewhere on the board
/Host Controller/ST67_CS: U302.16 (PA5); also elsewhere on the board
/Host Controller/ST67_MISO: U302.17 (SPI1_MISO); also elsewhere on the board
/Host Controller/ST67_MOSI: U302.18 (SPI1_MOSI); also elsewhere on the board
/Host Controller/ST67_RDY: U302.15 (PA4); also elsewhere on the board
/Host Controller/ST67_RX: U302.14 (USART2_RX); also elsewhere on the board
/Host Controller/ST67_SCK: U302.12 (SPI1_SCK); also elsewhere on the board
/Host Controller/ST67_TX: U302.13 (USART2_TX); also elsewhere on the board
/Host Controller/SWCLK: U302.36 (SYS_SWCLK); also elsewhere on the board
/Host Controller/SWDIO: U302.35 (SYS_SWDIO); also elsewhere on the board
/Host Controller/SWITCH_1: C309.1, R309.1, U302.25 (PB13)
/Host Controller/SWITCH_2: C308.1, R308.1, U302.24 (PB12)
/Host Controller/UCPD_CC1: U302.28 (UCPD1_CC1); also elsewhere on the board
/Host Controller/UCPD_CC2: U302.27 (UCPD1_CC2); also elsewhere on the board
/Host Controller/USB+: U302.34 (USB_DP (PA12)); also elsewhere on the board
/Host Controller/USB-: U302.33 (USB_DM (PA11)); also elsewhere on the board
/Host Controller/VOLTAGE_SENS_FLTR: C306.1, R304.1, U302.31 (PC7)
/VBUS_IN: R304.2; also elsewhere on the board
GND: C301.2, C302.2, C303.1, C304.1, C305.2, C306.2, C307.2, C308.2, C309.2, JP301.3 (B), JP302.3 (B), JP303.3 (B), R310.1, R311.1, SW301.1, SW302.1, U301.2 (GND), U301.5 (WP), U302.5 (VREF+), U302.7 (VSS), Y301.2 (G), Y301.4 (G); also elsewhere on the board
unnamed: C304.2, R303.2, Y301.3
unnamed: D301.1 (K), R310.2
unnamed: D302.1 (K), R311.2
unnamed: R306.2, R308.2, SW301.2
unnamed: R307.2, R309.2, SW302.2

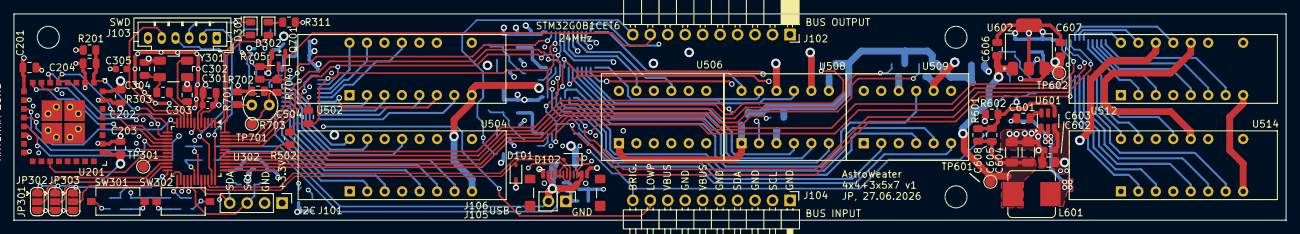
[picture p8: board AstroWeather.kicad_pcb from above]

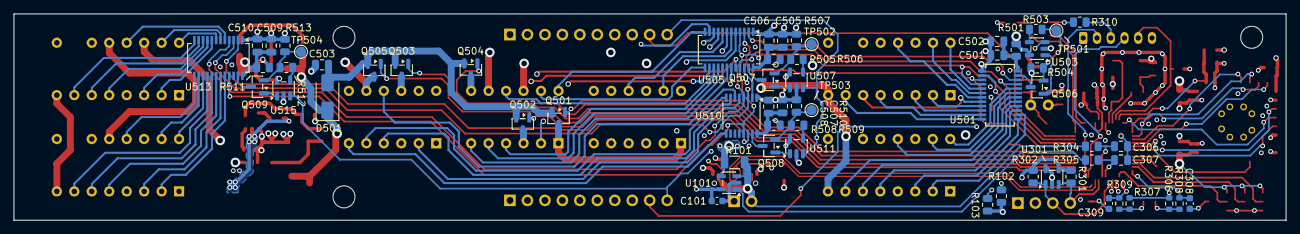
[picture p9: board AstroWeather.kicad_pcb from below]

Board: 6 copper layers, 185.0 x 30.0 mm, 127 parts (62 on the bottom side), 140 nets.

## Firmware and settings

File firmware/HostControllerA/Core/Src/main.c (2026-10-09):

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
/* Includes ------------------------------------------------------------------*/
#include "main.h"
#include "cmsis_os.h"
#include "usb_device.h"

/* USER CODE BEGIN Includes */
#include <AstroWeather.hpp>
#include "task.h"
#include "stm32g0xx_ll_crs.h"
/* USER CODE END Includes */

ADC_HandleTypeDef hadc1;
DMA_HandleTypeDef hdma_adc1;

I2C_HandleTypeDef hi2c1;

RTC_HandleTypeDef hrtc;

SPI_HandleTypeDef hspi1;
SPI_HandleTypeDef hspi3;
DMA_HandleTypeDef hdma_spi1_rx;
DMA_HandleTypeDef hdma_spi1_tx;
DMA_HandleTypeDef hdma_spi3_tx;

TIM_HandleTypeDef htim2;

UART_HandleTypeDef huart2;

/* Definitions for defaultTask */
osThreadId_t defaultTaskHandle;
const osThreadAttr_t defaultTask_attributes = {
  .name = "defaultTask",
  .priority = (osPriority_t) osPriorityNormal,
  .stack_size = 128 * 4
};
void SystemClock_Config(void);
static void MX_GPIO_Init(void);
static void MX_DMA_Init(void);
static void MX_SPI1_Init(void);
static void MX_USART2_UART_Init(void);
static void MX_SPI3_Init(void);
static void MX_I2C1_Init(void);
static void MX_TIM2_Init(void);
static void MX_ADC1_Init(void);
static void MX_RTC_Init(void);
void StartDefaultTask(void *argument);

/**
  * @brief  The application entry point.
  * @retval int
  */
int main(void)
{

  /* MCU Configuration--------------------------------------------------------*/

  /* Reset of all peripherals, Initializes the Flash interface and the Systick. */
  HAL_Init();

  /* Configure the system clock */
  SystemClock_Config();

  /* USER CODE BEGIN SysInit */
  /* CubeMX generates HSI48CalibrationValue = 32 whatever the GUI shows: the
     midpoint of the 6-bit TRIM on other families. The G0's TRIM is 7 bits
     with its midpoint and reset value at 64, so start the CRS there. USB is
     not running yet, so the CRS has not trimmed anything. */
  LL_CRS_DisableAutoTrimming();
  LL_CRS_SetHSI48SmoothTrimming(LL_CRS_HSI48CALIBRATION_DEFAULT);
  LL_CRS_EnableAutoTrimming();
  /* USER CODE END SysInit */

  /* Initialize all configured peripherals */
  MX_GPIO_Init();
  MX_DMA_Init();
  MX_SPI1_Init();
  MX_USART2_UART_Init();
  MX_SPI3_Init();
  MX_I2C1_Init();
  MX_TIM2_Init();
  MX_ADC1_Init();
  MX_RTC_Init();
  /* Init scheduler */
  osKernelInitialize();

  /* USER CODE BEGIN RTOS_MUTEX */
  /* add mutexes, ... */
  /* USER CODE END RTOS_MUTEX */

  /* USER CODE BEGIN RTOS_SEMAPHORES */
  /* add semaphores, ... */
  /* USER CODE END RTOS_SEMAPHORES */

  /* USER CODE BEGIN RTOS_TIMERS */
  /* start timers, add new ones, ... */
  /* USER CODE END RTOS_TIMERS */

  /* USER CODE BEGIN RTOS_QUEUES */
  /* add queues, ... */
  /* USER CODE END RTOS_QUEUES */

  /* Create the thread(s) */
  /* creation of defaultTask */
  defaultTaskHandle = osThreadNew(StartDefaultTask, NULL, &defaultTask_attributes);

  /* USER CODE BEGIN RTOS_THREADS */
  AstroWeather_Init();
  /* USER CODE END RTOS_THREADS */

  /* USER CODE BEGIN RTOS_EVENTS */
  /* add events, ... */
  /* USER CODE END RTOS_EVENTS */

  /* Start scheduler */
  osKernelStart();

  /* We should never get here as control is now taken by the scheduler */

  /* Infinite loop */
  /* USER CODE BEGIN WHILE */
  while (1)
  {
    /* USER CODE END WHILE */

    /* USER CODE BEGIN 3 */
  }
  /* USER CODE END 3 */
}

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
/* USER CODE BEGIN 4 */

volatile const char* g_stackOverflowTaskName = 0;

void vApplicationStackOverflowHook(TaskHandle_t xTask, signed char *pcTaskName)
{
  (void)xTask;
  g_stackOverflowTaskName = (const char*)pcTaskName;
  __disable_irq();
  while (1)
  {
  }
}

/* USER CODE END 4 */

/* USER CODE BEGIN Header_StartDefaultTask */
/**
  * @brief  Function implementing the defaultTask thread.
  * @param  argument: Not used
  * @retval None
  */
/* USER CODE END Header_StartDefaultTask */
void StartDefaultTask(void *argument)
{
  /* init code for USB_Device */
  MX_USB_Device_Init();
  /* USER CODE BEGIN 5 */
  /* CubeMX will not drop this task, so it ends itself once USB is started:
     USB runs from its interrupt, and the idle task frees this stack. It never
     runs again. */
  osThreadExit();
  /* USER CODE END 5 */
}

/**
  * @brief  Period elapsed callback in non blocking mode
  * @note   This function is called  when TIM1 interrupt took place, inside
  * HAL_TIM_IRQHandler(). It makes a direct call to HAL_IncTick() to increment
  * a global variable "uwTick" used as application time base.
  * @param  htim : TIM handle
  * @retval None
  */
void HAL_TIM_PeriodElapsedCallback(TIM_HandleTypeDef *htim)
{
  if (htim->Instance == TIM1)
  {
    HAL_IncTick();
  }
  /* USER CODE BEGIN Callback 1 */
  Display_PcbTimerElapsed(htim);

  /* USER CODE END Callback 1 */
}

/**
  * @brief  This function is executed in case of error occurrence.
  * @retval None
  */
void Error_Handler(void)
{
  /* USER CODE BEGIN Error_Handler_Debug */
  /* User can add his own implementation to report the HAL error return state */
  __disable_irq();
  while (1)
  {
  }
  /* USER CODE END Error_Handler_Debug */
}
#ifdef USE_FULL_ASSERT
/**
  * @brief  Reports the name of the source file and the source line number
  *         where the assert_param error has occurred.
  * @param  file: pointer to the source file name
  * @param  line: assert_param error line source number
  * @retval None
  */
void assert_failed(uint8_t *file, uint32_t line)
{
  /* USER CODE BEGIN 6 */
  /* User can add his own implementation to report the file name and line number,
     ex: printf("Wrong parameters value: file %s on line %d\r\n", file, line) */
  /* USER CODE END 6 */
}
#endif /* USE_FULL_ASSERT */

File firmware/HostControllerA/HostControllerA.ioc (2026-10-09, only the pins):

Mcu.UserName=STM32G0B1CETx
PA0.GPIO_Label=ST67_CHIP_EN
PA0.Signal=GPIO_Output
PA1.GPIO_Label=ST67_SCK
PA1.Signal=SPI1_SCK
PA10.Signal=I2C1_SDA
PA13.Signal=SYS_SWDIO
PA14-BOOT0.Signal=SYS_SWCLK
PA15.GPIO_Label=DISPLAY_2_EN
PA15.Signal=GPIO_Output
PA2.GPIO_Label=ST67_TX
PA2.Signal=USART2_TX
PA3.GPIO_Label=ST67_RX
PA3.Signal=USART2_RX
PA4.GPIO_Label=ST67_RDY
PA4.Signal=GPXTI4
PA5.GPIO_Label=ST67_CS
PA5.Signal=GPIO_Output
PA6.GPIO_Label=ST67_MISO
PA6.Signal=SPI1_MISO
PA7.GPIO_Label=ST67_MOSI
PA7.Signal=SPI1_MOSI
PA9.Signal=I2C1_SCL
PB1.GPIO_Label=ST67_BOOT
PB1.Signal=GPIO_Output
PB10.GPIO_Label=ADDR_0
PB10.Signal=GPIO_Input
PB11.GPIO_Label=ADDR_1
PB11.Signal=GPIO_Input
PB12.GPIO_Label=SWITCH_1
PB12.Signal=GPXTI12
PB13.GPIO_Label=SWITCH_2
PB13.Signal=GPXTI13
PB14.GPIO_Label=ADDR_2
PB14.Signal=GPIO_Input
PB2.GPIO_Label=CURRENT_SENSE
PB2.Signal=ADC1_IN10
PB3.GPIO_Label=SCT_SPI_SCK
PB3.Signal=SPI3_SCK
PB5.GPIO_Label=SCT_SPI_MOSI
PB5.Signal=SPI3_MOSI
PB6.GPIO_Label=SCT_LATCH
PB6.Signal=GPIO_Output
PB7.GPIO_Label=SCT_ENABLE
PB7.Signal=GPIO_Output
PB8.GPIO_Label=LOW_POWER_EN
PB8.Signal=GPIO_Output
PB9.GPIO_Label=LED_2
PB9.Signal=GPIO_Output
PC13.GPIO_Label=LED_1
PC13.Signal=GPIO_Output
PC6.Signal=GPIO_Analog
PC7.Signal=GPIO_Analog
PD0.GPIO_Label=DISPLAY_5_EN
PD0.Signal=GPIO_Output
PD1.GPIO_Label=DISPLAY_3_EN
PD1.Signal=GPIO_Output
PD2.GPIO_Label=DISPLAY_4_EN
PD2.Signal=GPIO_Output
PD3.GPIO_Label=DISPLAY_1_EN
PD3.Signal=GPIO_Output

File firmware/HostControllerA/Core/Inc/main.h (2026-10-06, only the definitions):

#define RTC_TIME_SET_BKP_REGISTER   RTC_BKP_DR0
#define RTC_TIME_SET_MARKER         0x54494D45UL /* "TIME" */
#define RTC_ASTRO_REFRESH_BKP_REGISTER RTC_BKP_DR1
#define LED_1_Pin GPIO_PIN_13
#define LED_1_GPIO_Port GPIOC
#define ST67_CHIP_EN_Pin GPIO_PIN_0
#define ST67_CHIP_EN_GPIO_Port GPIOA
#define ST67_SCK_Pin GPIO_PIN_1
#define ST67_SCK_GPIO_Port GPIOA
#define ST67_TX_Pin GPIO_PIN_2
#define ST67_TX_GPIO_Port GPIOA
#define ST67_RX_Pin GPIO_PIN_3
#define ST67_RX_GPIO_Port GPIOA
#define ST67_RDY_Pin GPIO_PIN_4
#define ST67_RDY_GPIO_Port GPIOA
#define ST67_RDY_EXTI_IRQn EXTI4_15_IRQn
#define ST67_CS_Pin GPIO_PIN_5
#define ST67_CS_GPIO_Port GPIOA
#define ST67_MISO_Pin GPIO_PIN_6
#define ST67_MISO_GPIO_Port GPIOA
#define ST67_MOSI_Pin GPIO_PIN_7
#define ST67_MOSI_GPIO_Port GPIOA
#define ST67_BOOT_Pin GPIO_PIN_1
#define ST67_BOOT_GPIO_Port GPIOB
#define CURRENT_SENSE_Pin GPIO_PIN_2
#define CURRENT_SENSE_GPIO_Port GPIOB
#define ADDR_0_Pin GPIO_PIN_10
#define ADDR_0_GPIO_Port GPIOB
#define ADDR_1_Pin GPIO_PIN_11
#define ADDR_1_GPIO_Port GPIOB
#define SWITCH_1_Pin GPIO_PIN_12
#define SWITCH_1_GPIO_Port GPIOB
#define SWITCH_1_EXTI_IRQn EXTI4_15_IRQn
#define SWITCH_2_Pin GPIO_PIN_13
#define SWITCH_2_GPIO_Port GPIOB
#define SWITCH_2_EXTI_IRQn EXTI4_15_IRQn
#define ADDR_2_Pin GPIO_PIN_14
#define ADDR_2_GPIO_Port GPIOB
#define DISPLAY_2_EN_Pin GPIO_PIN_15
#define DISPLAY_2_EN_GPIO_Port GPIOA
#define DISPLAY_5_EN_Pin GPIO_PIN_0
#define DISPLAY_5_EN_GPIO_Port GPIOD
#define DISPLAY_3_EN_Pin GPIO_PIN_1
#define DISPLAY_3_EN_GPIO_Port GPIOD
#define DISPLAY_4_EN_Pin GPIO_PIN_2
#define DISPLAY_4_EN_GPIO_Port GPIOD
#define DISPLAY_1_EN_Pin GPIO_PIN_3
#define DISPLAY_1_EN_GPIO_Port GPIOD
#define SCT_SPI_SCK_Pin GPIO_PIN_3
#define SCT_SPI_SCK_GPIO_Port GPIOB
#define SCT_SPI_MOSI_Pin GPIO_PIN_5
#define SCT_SPI_MOSI_GPIO_Port GPIOB
#define SCT_LATCH_Pin GPIO_PIN_6
#define SCT_LATCH_GPIO_Port GPIOB
#define SCT_ENABLE_Pin GPIO_PIN_7
#define SCT_ENABLE_GPIO_Port GPIOB
#define LOW_POWER_EN_Pin GPIO_PIN_8
#define LOW_POWER_EN_GPIO_Port GPIOB
#define LED_2_Pin GPIO_PIN_9
#define LED_2_GPIO_Port GPIOB

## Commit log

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2026-04-20 Bootstrap SST Astro API with `/astro/{configId}` and SunCalc-based Lambda (#3)
    * Initial plan
    * feat(sst): initialize api boilerplate and astro lambda handler
    Agent-Logs-Url: https://github.com/jakubprzybytek/AstroWeather/sessions/9f465143-cd99-4d77-b278-1eb755946901
    * refactor(sst): tighten configId type narrowing in astro handler
    Agent-Logs-Url: https://github.com/jakubprzybytek/AstroWeather/sessions/9f465143-cd99-4d77-b278-1eb755946901
    * fix(sst): null-safe sun and moon time serialization
    Agent-Logs-Url: https://github.com/ja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
2026-08-25 bug mentioned
    [AstroWeather.kicad_sch]
2026-08-26 Bug added: wrong sense pins
    [AstroWeather.kicad_sch]
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2026-09-17 RC values fixed
    [AstroWeather.kicad_sch]
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2026-09-20 24AA01 EEPROM driver and console probe commands
    Add Device::Eeprom24AA01 for the 24AA01T-I/OT settings EEPROM on I2C1,
    with page-aware writes and internal write-cycle (t_WC) ack polling, plus
    'eeprom probe/scan/read/write/erase/dump' console commands to bring it up.
    Verified on hardware: the chip answers at 0x50 (aliasing to 0x57, since
    its address pins are not bonded), page-straddling writes read back exact,
    and a full erase and 128-byte dump both complete.
    Bringing the bus up needed 2.2k pull-up resistors on SCL/SDA, which were
    missing. Without them the lines could never be released high, so the
    peripheral latched BUSY on its first START and no device ever answered.
    The resistors are siz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
    [HostController.kicad_sch]
2026-09-20 Re-enable remote display board I2C with reachability logging
    Remote board submits were commented out because a missing board hung the
    calling task. The cause was HAL_MAX_DELAY in BufferedDisplayBoard::submit:
    with no pull-up resistors fitted the bus could never complete a transfer,
    so an infinite timeout blocked forever. With the resistors in place an
    absent board simply NACKs, but the infinite timeout is still a hazard on a
    shared bus, so give the transfer a 50 ms bound (a refresh is ~24 bytes,
    about 2.5 ms at 100 kHz) and re-enable the submits.
    Report reachability per board instead of failing silently. Refreshes run
    at 10 Hz, so log transitions rather than every failure, and restate an
    un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
    [BufferedDisplayBoard.cpp, BufferedDisplayBoard.hpp]
2026-09-20 Serialize I2C1 access behind a bus-level lock
    hi2c1 has several unrelated clients - the settings EEPROM and every remote
    display board - driven from ConsoleService, CurrentSenseTask and
    AstroDataRefreshTask. Display::submit's mutex belongs to the Display
    object, so it serializes display refreshes against each other but does not
    exclude the EEPROM path, which never passes through it. The HAL handle
    guards itself only well enough to reject an overlapping call with
    HAL_BUSY, turning contention into a transfer that intermittently fails
    rather than one that waits its turn.
    Add Device::I2cBus, which owns the handle and a mutex, and route both
    clients through it. All HAL_I2C_* calls now live in th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
    [BufferedDisplayBoard.cpp, BufferedDisplayBoard.hpp]
2026-09-20 Document USB CDC port loss and recovery
    The console port intermittently stops working after repeated flash and
    reset cycles: it still enumerates, but opening it fails with
    FileNotFoundError and Windows reports CM_PROB_FAILED_START. This is a known
    ST USB device stack issue rather than a fault in this firmware, and it cost
    real debugging time during EEPROM bring-up.
    Record the symptoms, how to tell the failure apart from a hung or
    crash-looping firmware (read xTickCount twice over SWD with mode=HOTPLUG,
    which leaves the running image undisturbed), and the recovery steps in
    order of escalation. The key point is that a software reset is often not
    enough; -hardRst is what actually drops USB lon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
2026-09-21 Grouped help, switchable stats, and a welcome on connect
    Help: replace the one-line-per-command list with a grouped index plus
    'help <group>' for details and examples, and send 'OK help' once rather
    than prefixing every line. The descriptions now say how to use each
    command: value ranges, what 'settings save' is actually for, that offsets
    are hex, that 'eeprom erase' wipes the settings, and that stored WiFi
    credentials are not yet used to connect. 'eeprom scan' was missing and is
    now listed.
    The split into groups is forced by the log path, not just readability.
    The log queue holds 16 lines and drops the oldest when full, and the
    console and log tasks share a priority, so a whole reply burst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
2026-09-21 Connect WiFi with the credentials set by 'wifi set'
    The station connected with compile-time credentials from the gitignored
    app_credentials.h, and 'wifi set' saved values nothing read. It now takes
    the SSID and password from the settings store on every connect, so a
    'wifi set' applies to the next attempt. There is no built-in fallback:
    credentials default to empty, and an unconfigured device fails at once,
    before powering the module up, with a message saying to run 'wifi set'.
    The credentials are the one part of the settings read by another task, so
    Settings::Store gains locked setWifiCredentials/copyWifiCredentials, and
    'wifi clear' and 'settings defaults' go through the lock too.
    'wifi s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
    [SettingsCommand.cpp, SettingsStore.cpp]
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2026-09-21 Stamp the real build time into the image on every build
    The build time shown in the connect message and 'status' came from
    __DATE__/__TIME__ in FirmwareInfo.cpp, which only changes when that file is
    recompiled. After an incremental build it named an older build than the
    one flashed - on the bench it read 09:42 for an image built hours later.
    cmake/BuildInfo.cmake now writes generated/BuildInfo.cpp with the current
    time, run by a custom target on every build. The file is declared as the
    target's byproduct, so Ninja sees it change and recompiles just that file
    before relinking; touching FirmwareInfo.cpp instead would not work, since
    Ninja decides what is out of date before the build starts. T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
2026-09-21 Show astro refresh progress on the bottom matrix row
    A refresh runs for seconds - over 20 s for the first after boot - with no
    sign on the device that anything is happening, and a failure looked the
    same as nothing at all. The local board's bottom matrix row, which no
    other feature uses, now shows a progress bar: six segments for module
    start, joining WiFi, DHCP, download, disconnect and processing. Finished
    steps are solid and the current one blinks, so the 15 s module start
    still visibly moves. Success lights the full row for 1.5 s. A failure
    blinks the bar up to the step that failed for a minute, so where it
    stopped tells you what went wrong, and a new refresh interrupts it at
    once. Remot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
2026-09-21 Clock the display SPI at 1 MHz instead of 62.5 kHz
    SPI3 feeds the SCT2024/SCT2167 LED driver chain, 56 bits per multiplex
    slot. At prescaler 256 (62.5 kHz) each slot switch spent ~0.9 ms of its
    4 ms shifting data, 22% of DisplayRefresh's time, blocking in
    HAL_SPI_Transmit. Prescaler 16 (1 MHz) cuts that to ~56 us.
    1 MHz leaves wide margin: the SCT2024 accepts 25 MHz, and the pins stay
    within their GPIO_SPEED_FREQ_LOW rating, so no drive-strength change is
    needed. Beyond this the saving is tens of microseconds, not worth the
    tighter edges on the daisy chain. Going to 4 MHz or more would also need
    PB3/PB5 raised to medium speed.
    Set in CubeMX and regenerated; the only generated change is the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
    [HostControllerA.ioc, main.c]
2026-09-21 Keep the current display slot lit while the next one is shifted
    Each multiplex slot switch turned the current slot off, sent the next
    slot's 56 bits over SPI3, latched, then turned the next slot on, so the
    display was dark for the whole transfer. The SCT2024 datasheet says the
    outputs hold while LA/ is low, and its truth table shows shifting with LA/
    low leaves them unchanged, so the transfer does not need to be dark.
    SCT2xxx now exposes shift() and latch() separately (send() remains as
    both). DisplayRefresh shifts the next slot's data with the current slot
    still lit, then swaps with the outputs blanked through OE/: blank, old
    slot off, latch, new slot on, settle, unblank. Dark time per slo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
    [PcbDisplayBoard.cpp, SCT2xxx.cpp]
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2026-09-22 Show the RTC time on local numeric display 3
    The RTC is enabled in CubeMX with a calendar, clocked from the LSI: the
    G0B1 RTC cannot run from HSI, and no LSE crystal is fitted. The
    predividers are 127/249, which give 1 Hz from the 32 kHz LSI rather than
    the 32.768 kHz the defaults assume. The LSI is only good to a few
    percent, and the time restarts at 00:00 on every reset, as nothing sets
    it yet.
    ClockTask draws HH:MM on local numeric display 3 and refreshes only the
    local board. It redraws when the minute changes, sleeping until the next
    minute boundary by the RTC seconds rather than waking every second. An
    astro refresh still writes display 3; the time returns at the next
    minute.
    Verifie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
    [HostControllerA.ioc, main.c]
2026-09-22 Add time console commands, RTC trimming and a tracked date
    The clock could only be read; it is now set, trimmed and kept, and its
    approach is written up in docs/RTC.md.
    'time set <YYYY-MM-DD> <HH:MM[:SS]>' sets the calendar, seconds optional.
    'time show' prints it to the millisecond with the trim in use. 'time trim
    <ppm>' corrects this board's LSI, and 'time display on|off' switches
    display 3. The trim and the display flag are saved to the EEPROM as new
    records, ClockTrim (0x02) and ClockFlags (0x20), and applied at boot.
    The G0 has no LSI trim register, so RtcTrim turns a measured ppm error
    into RTC prescalers plus smooth calibration, within 1 ppm across the
    whole range. Writing prescaler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
    [SettingsCodec.cpp, SettingsCommand.cpp, main.c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]
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2026-09-23 Schedule the astro refresh every 6 hours and report the last weather fetch
    The device now refreshes by itself at 00:10, 06:10, 12:10 and 18:10
    local time, 10 minutes after the server's weather ingestion, which moves
    from rate(6 hours) to fixed local hours. Responses carry the time of the
    server's last successful weather fetch, and `status` shows it.
    Server (deployed to int):
    - ClearOutsideIngestion runs at cron(0 0/6 * * ? *) in Europe/Warsaw,
    so it follows DST and no longer drifts with each deploy.
    - New header record `lastWeatherFetchTime=YYYY-MM-DDTHH:MM:SS` (local),
    the newest `fetchedAt` among the weather items used, or `?` without
    weather. Weather-specific; other sources get the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
    [main.h]
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2026-09-24 Add low-brightness control on switch 2 and 'display low', record current measurements
    Switch 2 now toggles LOW_POWER_ENABLE (PB8), which turns on Q701 and
    lowers LED_BRIGHTNESS on every board. It no longer starts the WiFi stress
    batch; TriggerSt67ConnectivityCycle() is kept for bench use. The console
    gets 'display low [on|off]', saved under the new settings tag DisplayFlags
    (0x21) and applied at boot, plus a 'brightness' line in status. The
    DisplayController releases its PB8 at startup so it does not fight the host
    on the bussed net (M-4).
    Measured with all LEDs lit, low brightness cuts the LED current from
    59-65 mA to 28 mA. Hardware_Review.md also records the LED and astro
    refresh current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
    [SettingsCodec.cpp, SettingsCommand.cpp]
2026-09-24 Save low brightness from switch 2 and serialize settings saves
    Switch 2 now stores the toggled state in the EEPROM, like 'display low
    on|off', so it survives a reset. Settings::Store::save() holds the store's
    lock across the read-compare-write, since MainLoopTask now saves alongside
    the console task; setLowBrightness() sets the field under the same lock.
    Switch debouncing stays in hardware (R306/R308, C308).
    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
    [SettingsStore.cpp]
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2026-09-24 Complete the display board shopping list
    Every part is now priced: adds Samsung CL10B104KB8NNNC x200 (100n 0603)
    and Murata GRM31CR61E226KE15L x10 (22u 1206 25 V) to the TME order, and
    drops the 0805 capacitors and resistors from it. R504/R507/R510/R513 are
    4k7. The TPS54302 is still unavailable, so the TPS54202 swap stays;
    it and the switched-off digit glow move to closed items. Hardware
    review H-3 records that no glow is visible on the prototype and keeps
    the gate driver for the next PCB revision.
    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
    [Display_Board_BOM.csv]
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2026-09-24 Final display board shopping lists across Farnell, TME and Mouser
    The STM32G0B1CET6 slipped to 2027 at every distributor, so the display
    boards use the in-stock STM32G0B1CET6N with VDDIO2 tied to +3.3V (pin 31,
    decoupled at C306) and pin 30 grounded through a 0R at C307. The notes
    cover the wiring, firmware, and why other STM32G0 LQFP48 parts are
    pin-compatible but lack USB.
    Orders chosen on cost after rechecking all three distributors: Farnell
    for CET6N x7 and SRR6838A-330M x5 (free delivery above 200 zl), TME for
    the rest. Mouser, now reachable through the browser, is recorded as the
    alternative: it lacks the SCT drivers and displays and charges 105 zl
    delivery below 300 zl. The BOM gains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
    [Display_Board_BOM.csv]
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2026-09-26 Encode the display frame outside the refresh lock
    PcbDisplayBoard::submit() held frameMutex_ while encodePcb() ran, about
    0.5 ms at 16 MHz. The refresh task takes the same lock for every slot, so
    a submit could hold a slot switch back by that much. The current-sense
    readout submits every 100 ms, which showed as a 10 Hz wobble once slots
    were split into shorter gray-level passes. Encode into a local frame and
    lock only to copy it.
    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
    [PcbDisplayBoard.cpp]
2026-09-26 Run the display refresh above the lwIP netif task
    The ST67 driver creates lwIP's netif task at NETIF_TASK_PRIORITY 50, above
    DisplayRefresh at osPriorityRealtime (48). While WiFi data arrived it
    pre-empted the multiplexing and held a slot for up to 5.4 ms during an
    astro refresh. This was the untraced connect-time stall left after the
    driver's SPI and modem tasks were moved below the display.
    The value is a plain #define in the generated lwip_netif.h, so it cannot be
    overridden in a way that survives regeneration. Raise DisplayRefresh to
    osPriorityRealtime7 (55) instead, the highest task priority. Measured with
    a gray-level test: the refresh task's longest wait during a refresh fell
    from 4.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
    [PcbDisplayBoard.cpp]
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2026-09-26 Refresh the display from the timer interrupt with DMA shifts
    The refresh task woke on every timer tick, took a mutex and spent ~210 us
    in the blocking SPI HAL before a slot could change, and any task-level
    stall moved the slot boundary with it. With slots split into passes as
    short as 480 us that showed as flicker on the dim levels. Now the timer
    interrupt does it all: it latches the data the DMA shifted in during the
    pass that just ended, sets the length of the pass that starts, and starts
    the DMA for the next one. The timing depends on interrupt latency only.
    The task is gone, the frames are double-buffered and swapped at a frame
    boundary, so a frame never mixes two submissions.
    RefreshSe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
    [DisplayController.ioc, HostControllerA.ioc, PcbDisplayBoard.cpp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]
2026-09-26 Send display attributes to the DisplayController boards
    The host sends a remote board its blink and level planes (0x02-0x04) and
    then the content (0x01). The DisplayController stages the attributes in
    FrameAssembler and applies them with the content, so both change as one;
    they persist until replaced, and an old host that sends only content gets
    full brightness. I2cTarget queues four messages instead of keeping the
    newest, since the four now arrive a few milliseconds apart. The stats
    block gains the attribute, queue and refresh counters. Not yet run on a
    display board.
    Claude-Session: https://claude.ai/code/session_01Rf2C88gWwK8JtcjQz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
    [BufferedDisplayBoard.cpp]
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2026-10-04 Fetch the forecast over HTTPS with TLS in the ST67 module (T01)
    Squash of feature/https-t01 (10 commits, 2026-10-03/04).
    The ST67W611M1 moves from ST's T02 architecture (LwIP and HTTP on the STM32)
    to T01: TCP/IP, DHCP, DNS and TLS run in the module and the host drives them
    through the X-CUBE-ST67W61 1.3.0 W6X_Net socket API. The daily forecast is
    fetched over HTTPS from the CloudFront API with Amazon Root CA 1 as the trust
    anchor, and the module verifies the chain and the hostname (fails closed,
    proven against badssl.com). Plain HTTP remains a bench build option.
    Host firmware:
    - CubeMX regenerated for T01; LwIP, the generated HTTP client, altls_mbedtls
    and sntp are gone, together with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
    [HostControllerA.ioc, SettingsCommand.cpp]
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2026-10-04 Keep the API device key in the HostController's EEPROM
    `api key <key>` saves the key as settings tag 0x14 (ApiKey, 1-32 URL-safe
    characters), with APP_ST67_HTTP_KEY as an optional built-in fallback.
    The fetch appends it as ?key= (formatRequestPath), so the path stays
    /device/astro/<id>; `api show`, `settings show` and the fetch log show
    only <set>/<none>. `astro test` moves to /device/astro/test, since the
    web route now needs a Cognito token.
    To keep the worst-case settings image within the 250-byte payload the
    path limit drops from 64 to 32 (worst case 248). A longer path record
    from before is ignored on decode, falling back to the built-in path,
    rather than cut short into another path. Se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
    [SettingsCodec.cpp, SettingsCommand.cpp, SettingsStore.cpp]
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2026-10-05 Fix the display board's NACK after one byte; retry remote sends
    About one refresh in seven, the 0x11 board NACKed the second byte of a
    message and the host lost that board's data until the next refresh.
    Traced on the board: its I2C interrupt shared priority 3 with the ~170 us
    refresh interrupt, so it could handle a message's STOP only after the
    host's next address had matched. The HAL sets CR2.NACK when it handles a
    STOP, and software cannot clear that bit (only an address match, a STOP or
    a sent NACK does), so the late NACK stayed set into the next message.
    DisplayController: I2C1's interrupt now has priority 1, above the refresh
    timer, DMA and EXTI. 30 refreshes in a row then went through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
    [BufferedDisplayBoard.cpp, BufferedDisplayBoard.hpp, DisplayController.ioc]
2026-10-05 Give the host's USB interrupt priority 1; it missed SETUP packets
    The recurring COM port failures (error 31 on opening the port, Code 10
    after a reset, the port coming back under a new COM number) were the
    firmware's, not Windows'. While an EP0 receive interrupt is unserviced the
    STM32 USB peripheral does not answer a new SETUP. The USB interrupt shared
    priority 3 with the ~170 us display refresh interrupt, and takes 100-290 us
    itself in the Debug build, so a request sent right after the previous
    one's status stage could miss all three of the host's tries.
    Traced on the board with a RAM log of control requests and a scripted
    open/close loop: at priority 3, 4 of 64 and 11 of 200 opens failed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
    [HostControllerA.ioc]
2026-10-05 Let the display commands target a remote board or every board
    'display 0x12 test', 'display 0x14 show 1 12.3', 'display all clear': an
    optional address (0x10-0x15) or 'all' between 'display' and the
    subcommand. show, row, blink, level, test and clear edit the host's
    buffered copy of that board and send it, through the new
    Display::submitRemote(); the next astro refresh replaces it. No target is
    the local board as before, and so is the host's own address.
    A board that does not take it gets 'ERR display-unreachable 0x12', or a
    list after 'OK display all'. passes stays local, since the I2C messages
    carry no pass table ('ERR unsupported-remote'); low drives every board
    already.
    On the bench (h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
    [BufferedDisplayBoard.hpp]
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2026-10-06 Move the docs into Docs folders; hardware docs to KiCad/Docs
    firmware/<project>/docs becomes Docs, Development.md moves up to the
    shared firmware/Docs, and the hardware documents (review, display board
    purchasing and BOM, display issues) to KiCad/Docs. The HTTPS plan, the
    CubeMX migration plan and the USB-PD study go to archive folders. Links
    are rewritten for the moves; content is unchanged.
    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
    [Display_Board_BOM.csv]
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2026-10-06 Keep display boards on the host's refresh timeline; HSI trim
    The host broadcasts its refresh position (frame and microseconds) to the
    I2C general-call address in a burst at 0, 10, 30 and 60 s, then every
    5 minutes, and polls each remote board's one-byte sync status every
    minute to start a burst for a board that wants one. A display board
    stamps the broadcast in its receive interrupt and corrects its frame
    lengths: rate and phase through TimelineServo (slewing at most 0.5 % of
    a frame, 5 % while more than 5 ms out), jumps on its first sync or a
    host reboot, and moves HSITRIM within 8 steps when it is more than
    2000 ppm off. A trend term carries temperature drift over the 5-minute
    gaps. Native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
    [DisplayI2cProtocol.cpp, HsiTrim.hpp]
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2026-10-06 Take the sync's rate trend only from intervals of 2 minutes or more
    On the bench a burst's 20-30 s intervals gave rates 40-160 ppm off the
    5-minute ones, and the trend extrapolated that error over the next
    5 minutes: the board ended 76-81 ms out. Now only two 5-minute intervals
    make a trend. The first interval after a burst runs without one (about
    10 ms at 400 ppm/h of drift in the simulation, 1.5 ms once known).
    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
    [TimelineSync.hpp]
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2026-10-07 Fix the display timeline sync found 20-50 ms out on the bench
    Board 0x11 ended most 5-minute intervals 30-50 ms out, and up to 90 ms after
    a doubled correction (measured over SWD on 2026-10-07):
    - stampNow() read the pending correction from the frame record, stale after
    applySync() in the same frame, so a second sync a few ms after the first
    (a poll right after a regular sync) corrected the same error twice. It
    reads the servo's live value now, the record is renumbered with the frames
    at a jump, and the jump test takes the pending correction off the error.
    - The board stamps at the address match, before the data bytes, which the
    host's interrupts stretch to 690-1840 us; kSyncTrans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
    [PcbDisplayBoard.cpp, TimelineSync.hpp]
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2026-10-09 Run the RTC from the 24 MHz crystal (HSE / 32)
    CubeMX: the RTC clock mux is HSE / 32, 750 kHz, with prescalers 124/5999 for
    an exact 1 Hz; the LSI is no longer enabled. The regeneration had also reset
    the USB interrupt to priority 3; it is back at 1 in the .ioc and usbd_conf.c,
    the setting that keeps the console from failing to open (error 31, Code 10).
    RtcTrim computed prescalers for a 32 kHz LSI and setTrim() applied them at
    boot, which on the 750 kHz clock would have run the RTC about 23 times fast.
    It now computes for 750 kHz with PREDIV_A fixed at 124 (0 ppm gives 124/5999,
    CALM 0), and the trim is the crystal's error, limited to +-1000 ppm. A saved
    trim outside that range was measured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
    [HostControllerA.ioc, main.c]
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

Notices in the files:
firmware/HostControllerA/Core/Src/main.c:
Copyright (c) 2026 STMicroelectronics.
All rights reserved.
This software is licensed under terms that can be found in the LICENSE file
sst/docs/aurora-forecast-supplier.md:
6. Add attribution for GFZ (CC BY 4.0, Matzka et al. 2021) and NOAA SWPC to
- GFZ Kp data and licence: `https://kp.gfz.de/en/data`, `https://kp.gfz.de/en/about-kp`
